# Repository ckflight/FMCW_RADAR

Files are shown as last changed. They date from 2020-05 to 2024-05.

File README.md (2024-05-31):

# Frequency Modulated Continuous Wave Radar Hardware Design and the Firmware

Check the new design's Python files for better processing and analysis https://github.com/ckflight/FMCW_RADAR_2v2

#### Later Update 1: 
  New version of the hardware is available in the **Radar 2** folder. For **Radar 2** design, two separated boards in **Radar MCU** and **Radar RF** folders are brought together with several necessary improvements. I recommend using the second design since it is more reliable and tested. The reason behind two separate board was to change digital part of the board without changing the RF part of it. However, one united design performs better and have a better temperature cooling control which affect the overall perfomance significantly.
  
  ##### Important Power Supply Note: I used switching regulator for 3.3 and 5V power sources to test their effect on the RF performance and oscillation of ripple voltage on OpAmp analog amplifier side. Therefore do not use switching regulator in your design. Change them to LDO type of clean supplies. Or add second LDO stage to the switching regulator unless you want an AM modulated ( 1.4 MHz switching freq. is very visible ) signal at the OpAmp side. After observing these affects i had to fine tune components which is not necessary if you use a cleaner source !!!

#### Later Update 2: 
  I have added a new Python script for plotting the radar data with Python Qt5 and Vispy plotting tool which uses GPU instead of CPU. Radar_Plot2.py is the source code. New code plots the time domain and frequency domain data together with scale and restart options. It has thread based approach between Vispy and Qt classes by using DataSource which allows us to manage more data. See first screenshot under Python Script Plots section below.

#### Radar Info:
 * Frequency Modulated Continuous Wave Radar with 26 dBm output power covering around 250 meters range with 10 dBi gain patch antenna (400 meters in theory by using a better ADC with higher sampling rate to match the noise floor of the RF receiver chain).
 
 $$ Range(radar) = {\sqrt[4]{Pt * G^2 * \lambda^2 * \sigma \over Pmin * 4\pi^3}} $$
 
  * Receiver chain has LNA, Gain Block and Mixer. The gain block drops the Noise Figure from 7 dB to 2 dB, which doubles the detection range. To determine the radar detection range, minimum detectable signal is needed. RF receiver chain has thermal noise and it determines the noise floor for Pmin. Signal to Noise (SNR) ratio of 20 dB is assumed for a good detectable signal then:
 
 $$ Pthermal(watt) = {k * T * B * F} $$
 
 $$ Pthermal(dBm) = {10\log_{10} {kT \over 1mW} + NF + 10\log_{10} BW} $$
  
 $$ Pmin(dBm) = {Pthermal(dBm) + 20dB} $$

 * Radar, has an auto gain configuration with a digital potentiometer to control intermediate frequency (IF) signal gain at the last stage of the analog amplifier before sampling with ADC.
 
 * -40 dB / Decade Range Compensation Filter is implemented. Closer objects reflect more powerful RF signal which suppresses the signal of the objects at further distance. By amplifying the weaker signals and filtering the closer ones, each frequency band is adjusted to the same amplitude.
 
 * The IF signal is available at different stages of the amplifier and filter circuit for testing with other configurations.

 * The VCO range of the radar is from 5.5 to 6.1 GHz
 
 * Directional coupler has low insertion loss of 0.25 dB and 16 dB coupling.
 
 * ADF4158 Frequency Synthesizer is available due to the nonlinear characteristics of the VCO profile for accurate distance detection. ADF4158 can generate pulses with some gap between each sweep. During this gap samples are packed and buffered over USB.
 
  * STM32F4's DAC has a triangular waveform generation option and it can be used for VCO signal generation as well. Both option are available on board. Check schematic to populate necessary resistor values to use either mode.
 
 * SMA connector has 1 mm pad size, but the 50 Ohm transmission line is 0.342 mm wide. To prevent reflection, cutout is implemented beneath the SMA pad with CST Studio simulation which is also available at my repository https://github.com/ckflight/CST_ADS_MODELS_SIMULATIONS

 * PCB has 4 layers. 50 Ohm impedance microstrip transmission line is making 0.342mm trace width by using oshpark's stack-up below. Stack-up layer information can be found here: https://docs.oshpark.com/services/four-layer/

 * Main loop runs with a Finite State Machine (FSM) to control radar, which checks the condition of the start of the sweep and the gap. ADF4158 Muxout is generating a pulse according to the sweep condition. External interrupt tracks this pulse to move between FSM states. 

 * Hardware is configured using Python script so the PC is in Host mode and controls everything. In this way, any hardware parameters can be changed without reflashing the firmware.

 * N number of samples are determined by sweep bandwidth rise time and the sampling frequency. 
   For example:

   Fs = 500.000 samples/sec and the sweep rise time is 1 millisecond (ms) for 200 MHz bandwidth. The system will pack 500 x  16 bit ADC samples and transfer 1000 x 8 bit ADC samples to Python script in 1 ms. Therefore, 1 MegaByte data is buffered to Host PC for 500 KHz sampling frequency in 1 second.
  
 * Python Script: I have uploaded an example record file along with python scripts where the peaks of the stationary objects can be seen. 

### Object Type Detection:

 * Object type detection is done with the similar code that i wrote for my project at the repository https://github.com/ckflight/RADAR_24GHZ_NEURAL_NETWORK
 
## RADAR 2 Screenshot:
Radar 2

## RADAR 1 RF Board Screenshot:
RADAR_RF

## RADAR 1 MCU Board Screenshot:
RADAR_MCU



## Python Script Plots:
radar1

radar2

radar3

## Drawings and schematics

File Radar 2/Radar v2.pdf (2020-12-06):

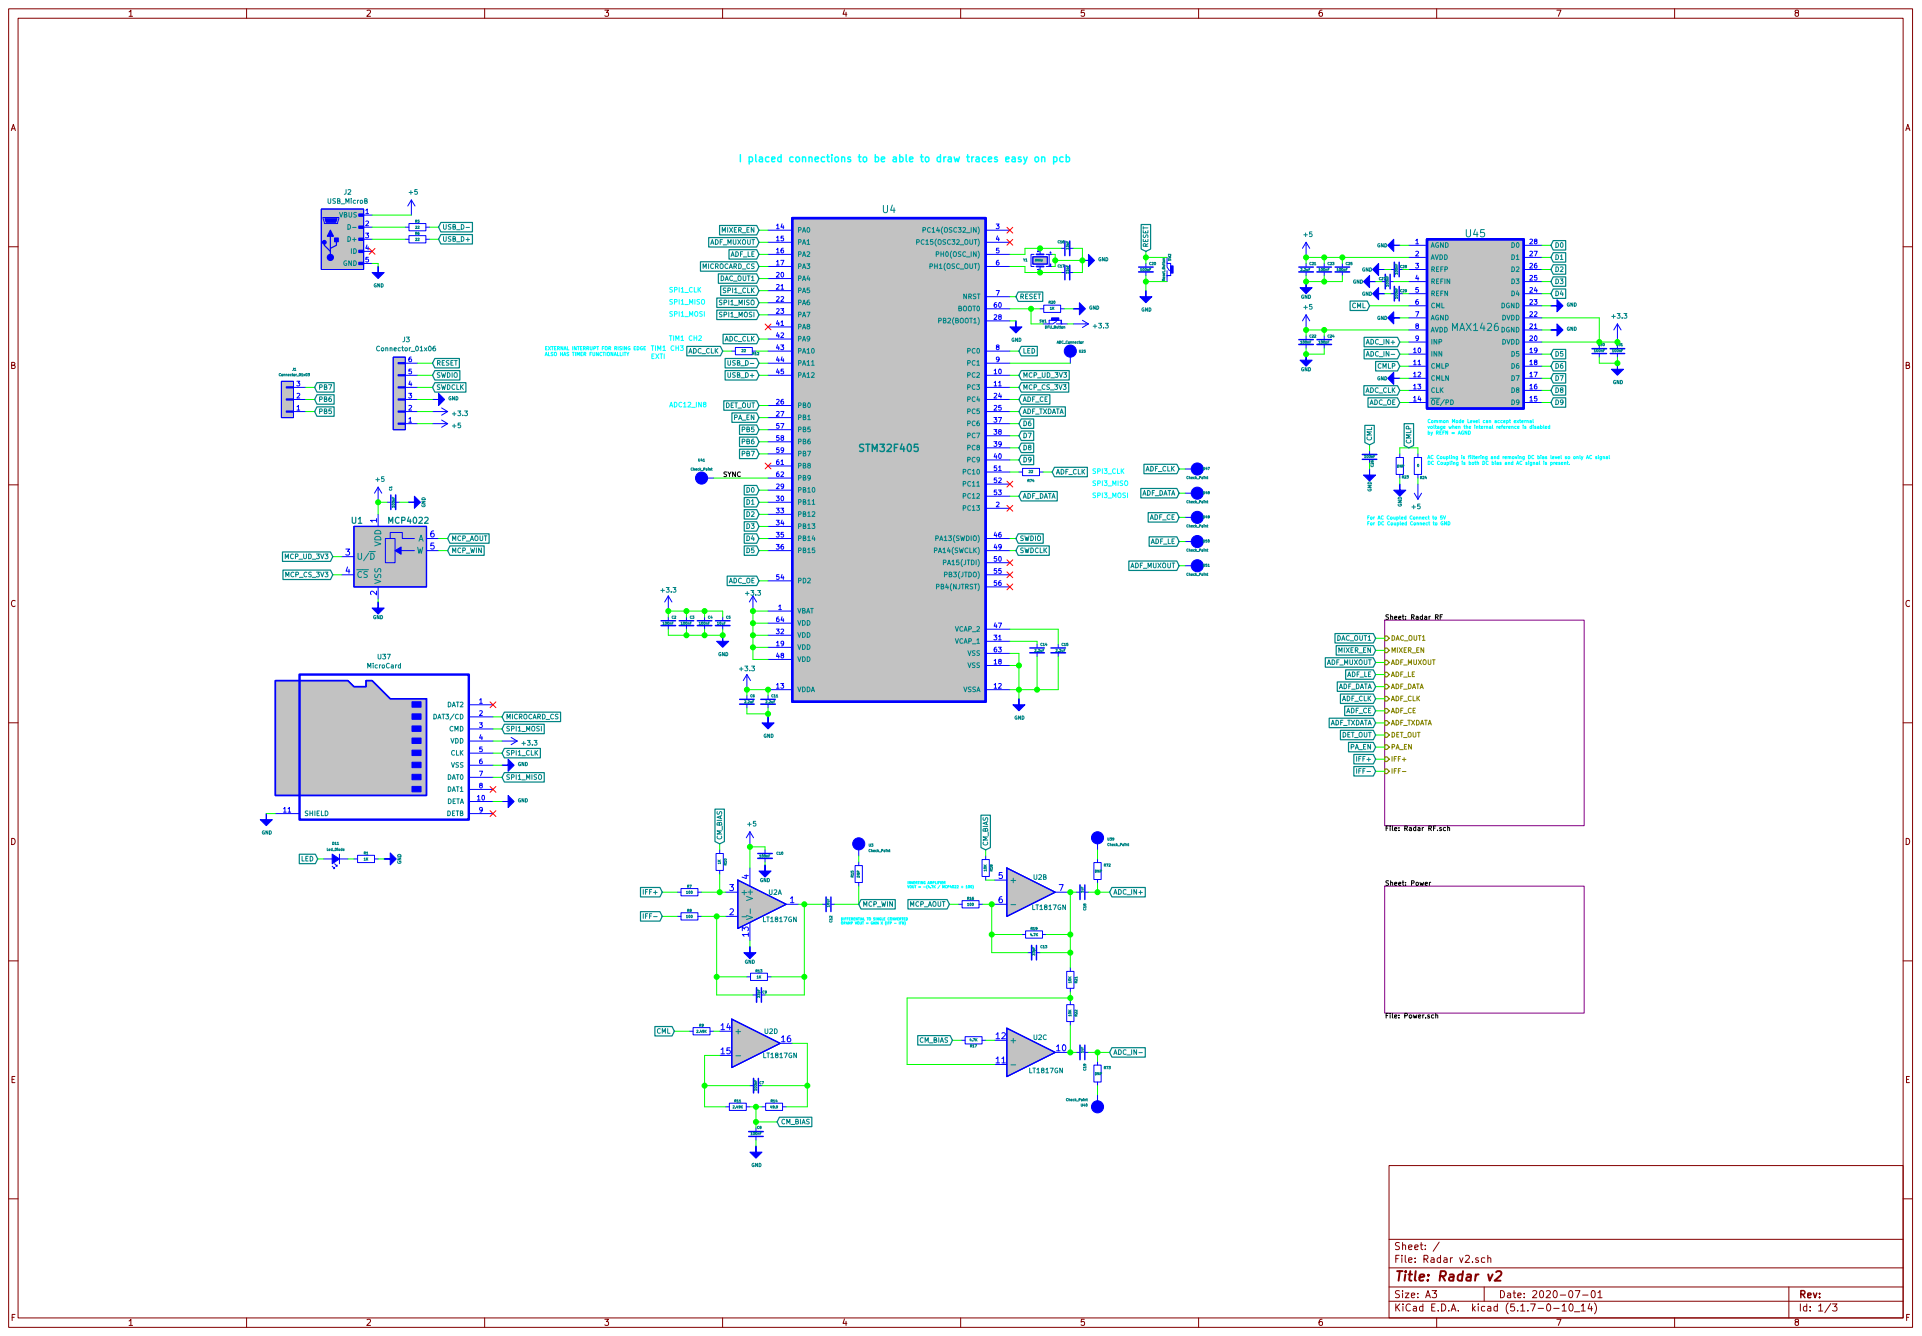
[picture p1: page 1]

I placed connections to be able to draw traces easy on pcb

LED | 1K

AC Coupling is filtering and removing DC bias level so only AC signal DC Coupling is both DC bias and AC signal is present. ADC12_IN8

Common Mode Level can accept external voltage when the internal reference is disabled

For AC Coupled Connect to 5V
For DC Coupled Connect to GND

Sheet: Radar RF
File: Radar RF.sch DAC_OUT1 MIXER_EN

VOUT = -(4.7K / MCP4022 + 100) DIFFERENTIAL TO SINGLE CONVERTED OPAMP VOUT = GAIN X (IFP - IFN)

File: Radar v2.sch Sheet: /
Id: 1/3 Title: Radar v2

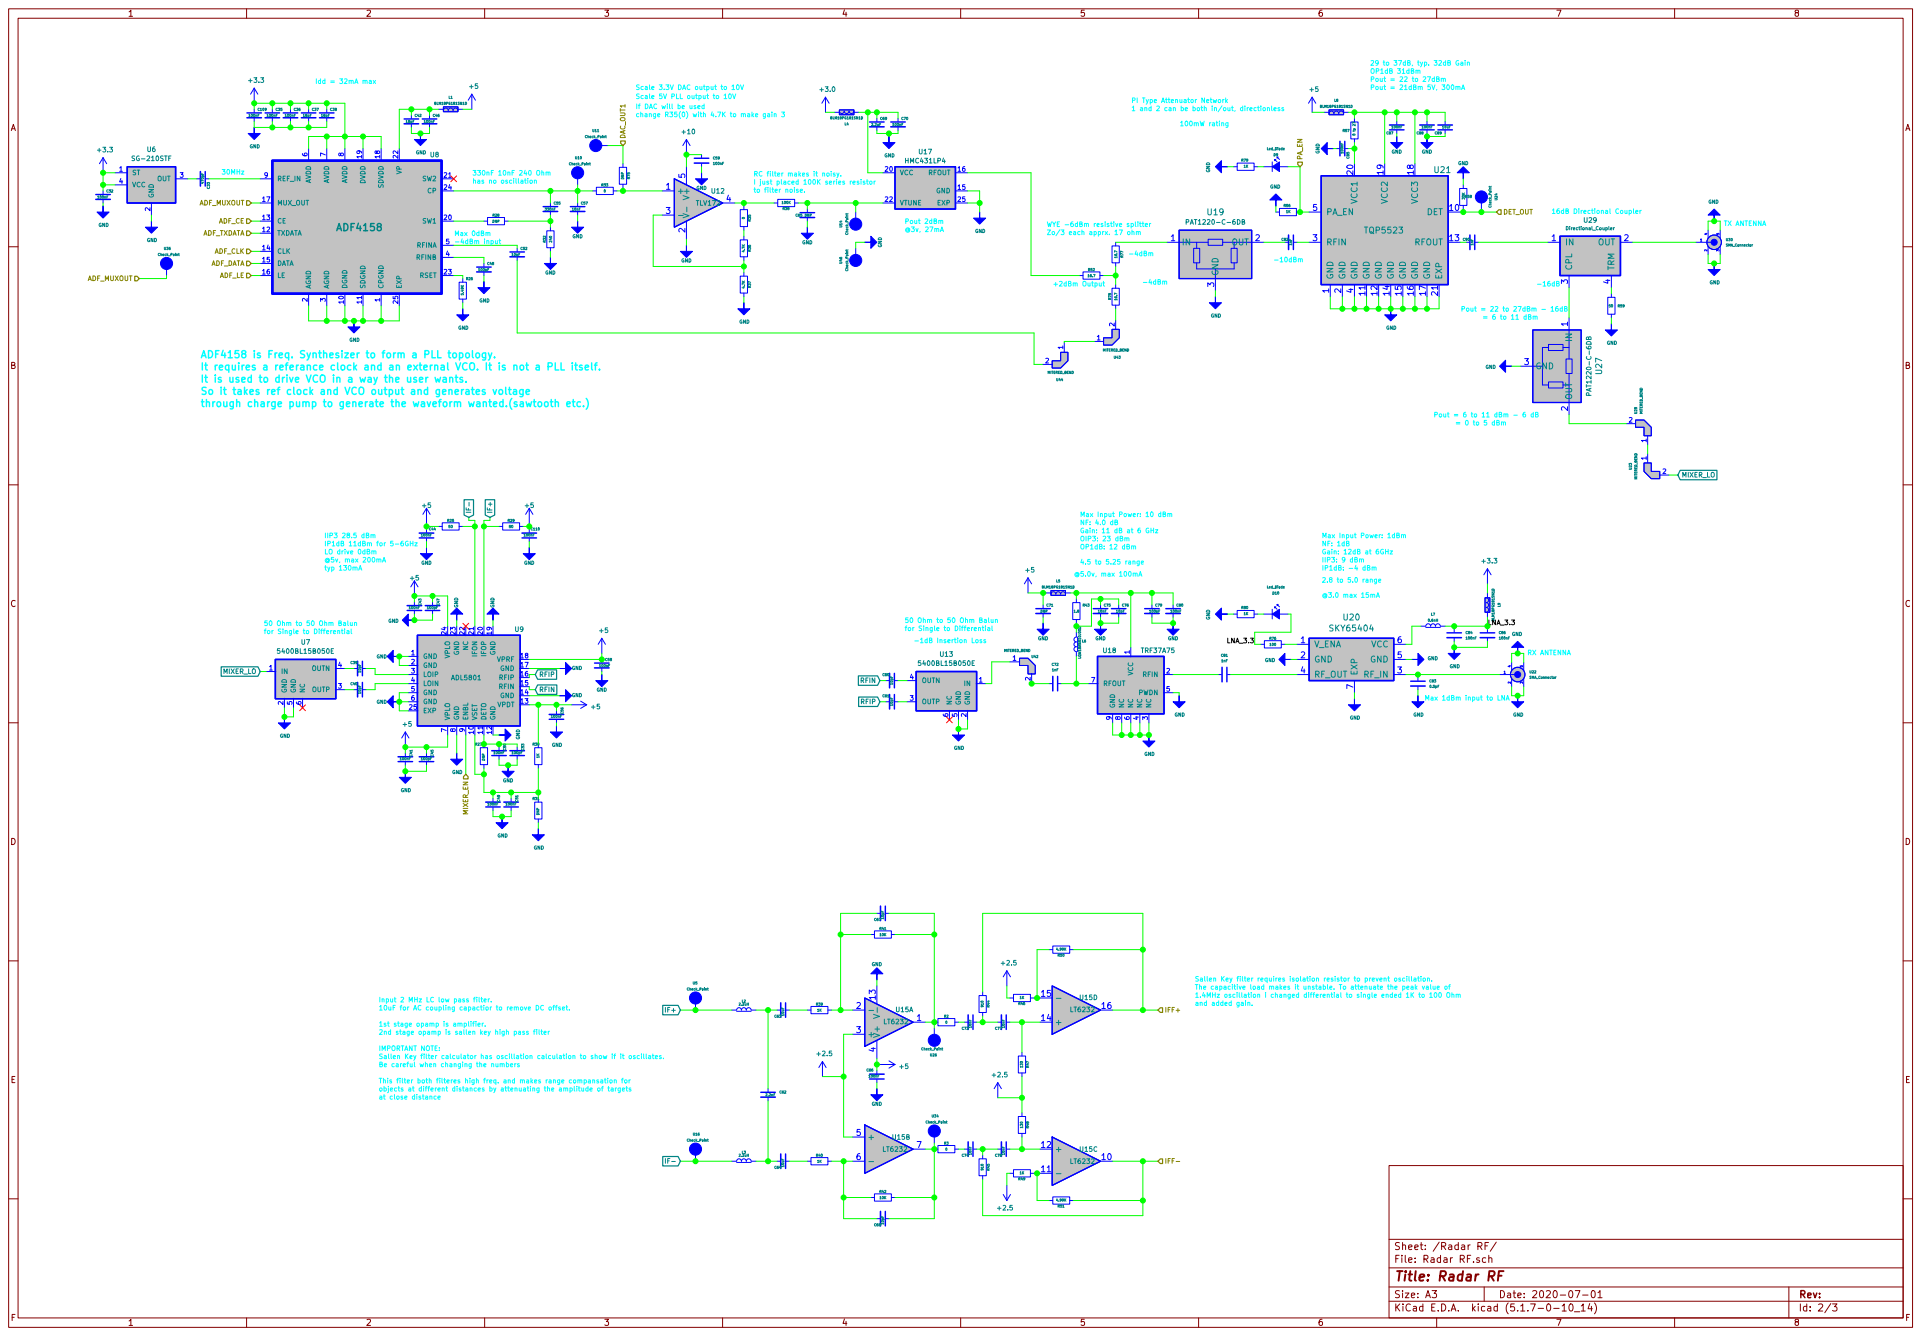
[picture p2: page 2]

Scale 3.3V DAC output to 10V
Scale 5V PLL output to 10V
If DAC will be used
change R35(0) with 4.7K to make gain 3

Pout = 21dBm 5V, 300mA WYE -6dBm resistive splitter Zo/3 each apprx. 17 ohm

2 SW1 20 SW2 21 VP 22 RSET 23 CP 24 EXP 25 AGND

1 DET 10 GND 11 GND 12 RFOUT 13 GND 14 GND 15 GND 16 GND 17 VCC3 18 VCC2 19 GND

RC filter makes it noisy.
I just placed 100K series resistor
to filter noise.

1 DGND 10 SDGND 11 TXDATA 12 CE 13 CLK 14 DATA 15

for Single to Differential ADF4158 is Freq. Synthesizer to form a PLL topology.
It requires a referance clock and an external VCO. It is not a PLL itself.
It is used to drive VCO in a way the user wants.
So it takes ref clock and VCO output and generates voltage
through charge pump to generate the waveform wanted.(sawtooth etc.)

Pout = 6 to 11 dBm - 6 dB
= 0 to 5 dBm

Max 1dBm input to LNA Max Input Power: 10 dBm
NF: 4.0 dB Gain: 11 dB at 6 GHz OIP3: 23 dBm

IIP3 28.5 dBm
IP1dB 11dBm for 5-6GHz LO drive 0dBm @5v, max 200mA

RX ANTENNA Max Input Power: 1dBm
NF: 1dB Gain: 12dB at 6GHz

100pF GND
for Single to Differential 50 Ohm to 50 Ohm Balun

50 Ohm to 50 Ohm Balun

Sallen Key filter requires isolation resistor to prevent oscillation. The capacitive load makes it unstable. To attenuate the peak value of 1.4MHz oscillation i changed differential to single ended 1K to 100 Ohm

Input 2 MHz LC low pass filter. 10uF for AC coupling capactior to remove DC offset. 1st stage opamp is amplifier. 2nd stage opamp is sallen key high pass filter

IMPORTANT NOTE: Sallen Key filter calculator has oscillation calculation to show if it oscillates. Be careful when changing the numbers This filter both filteres high freq. and makes range compansation for objects at different distances by attenuating the amplitude of targets

Id: 2/3 Title: Radar RF

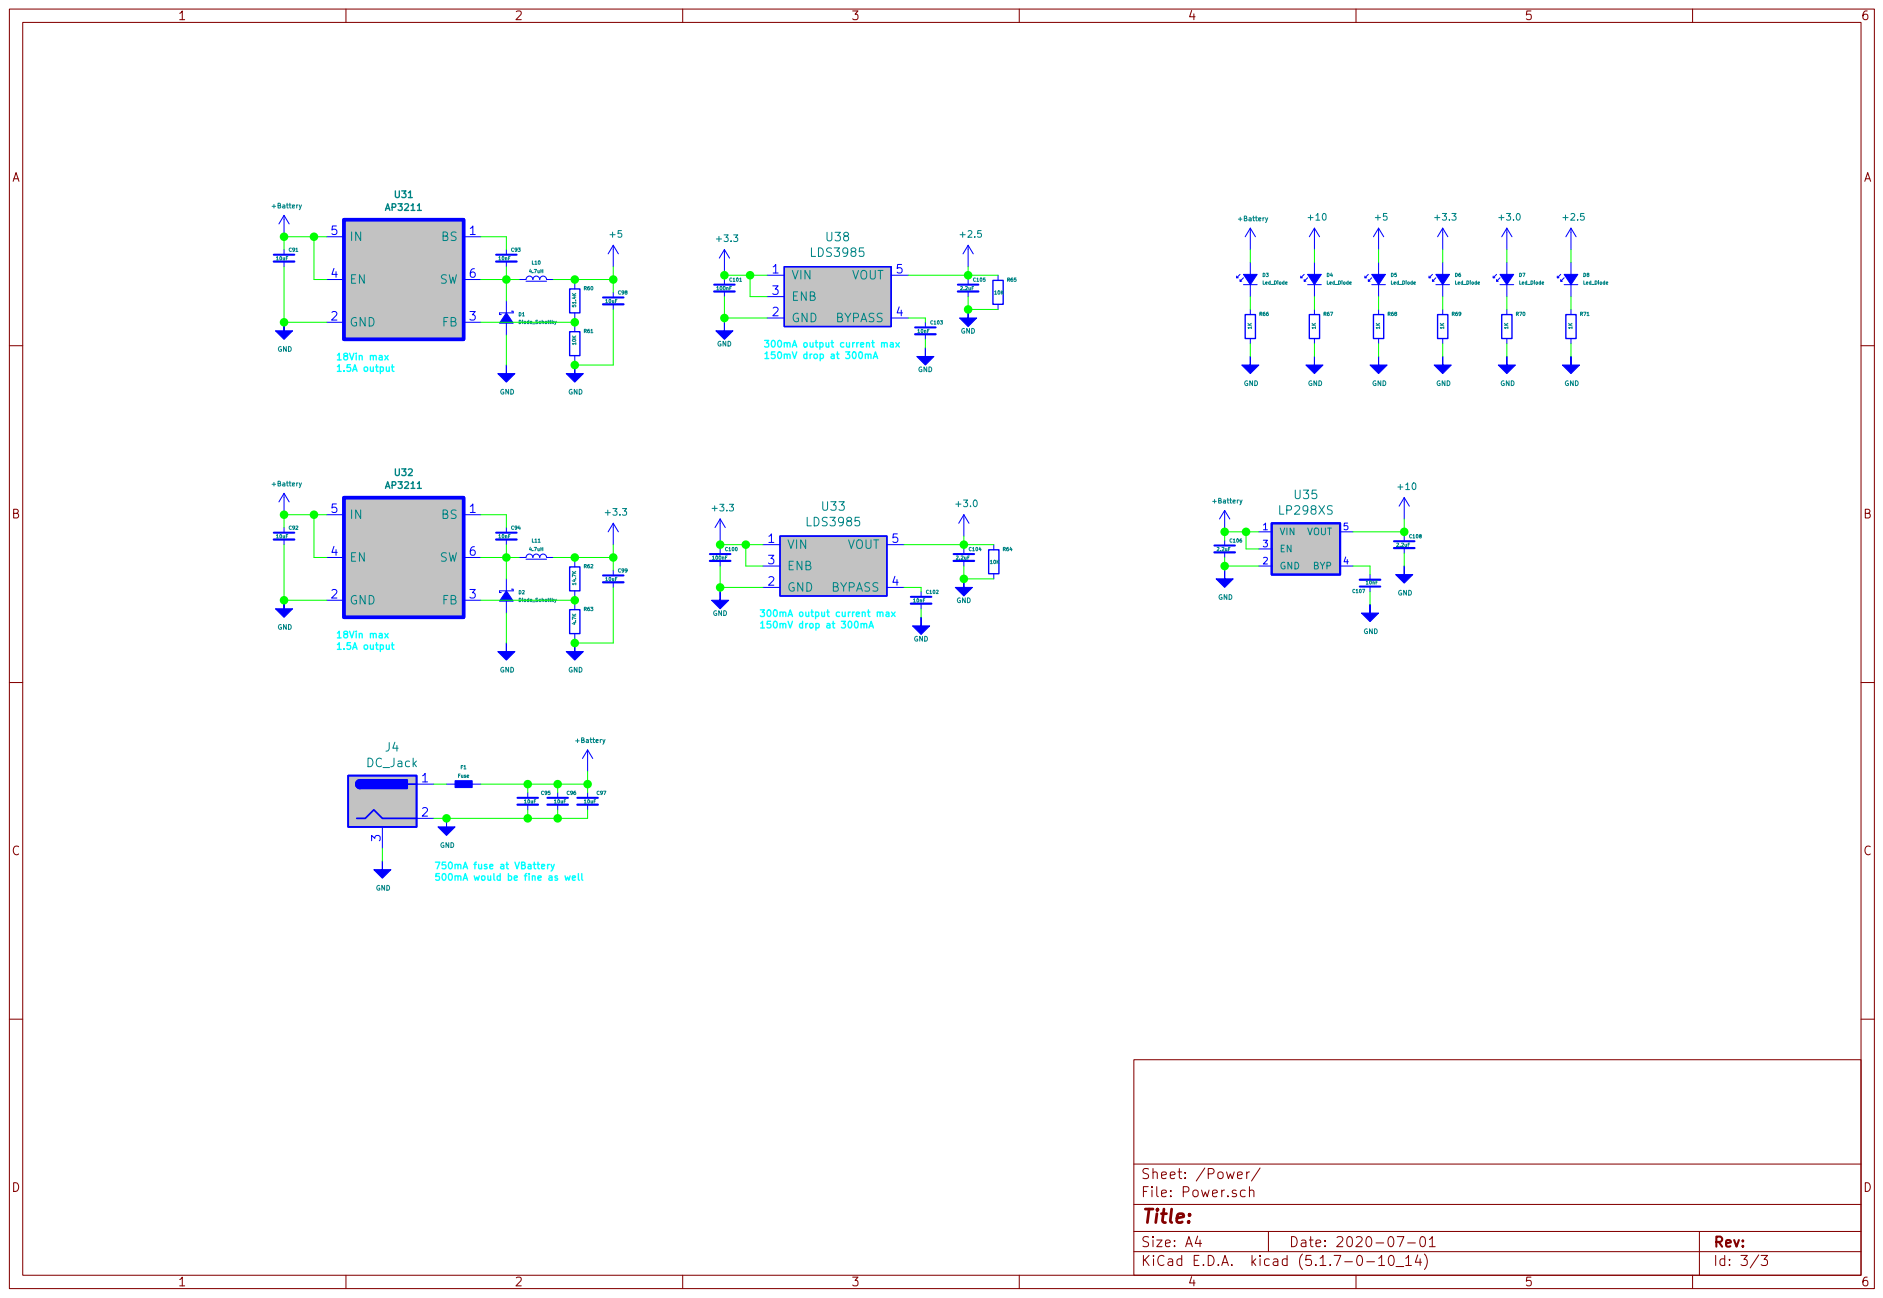
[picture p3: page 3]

Id: 3/3 Title: File: Power.sch Sheet: /Power/

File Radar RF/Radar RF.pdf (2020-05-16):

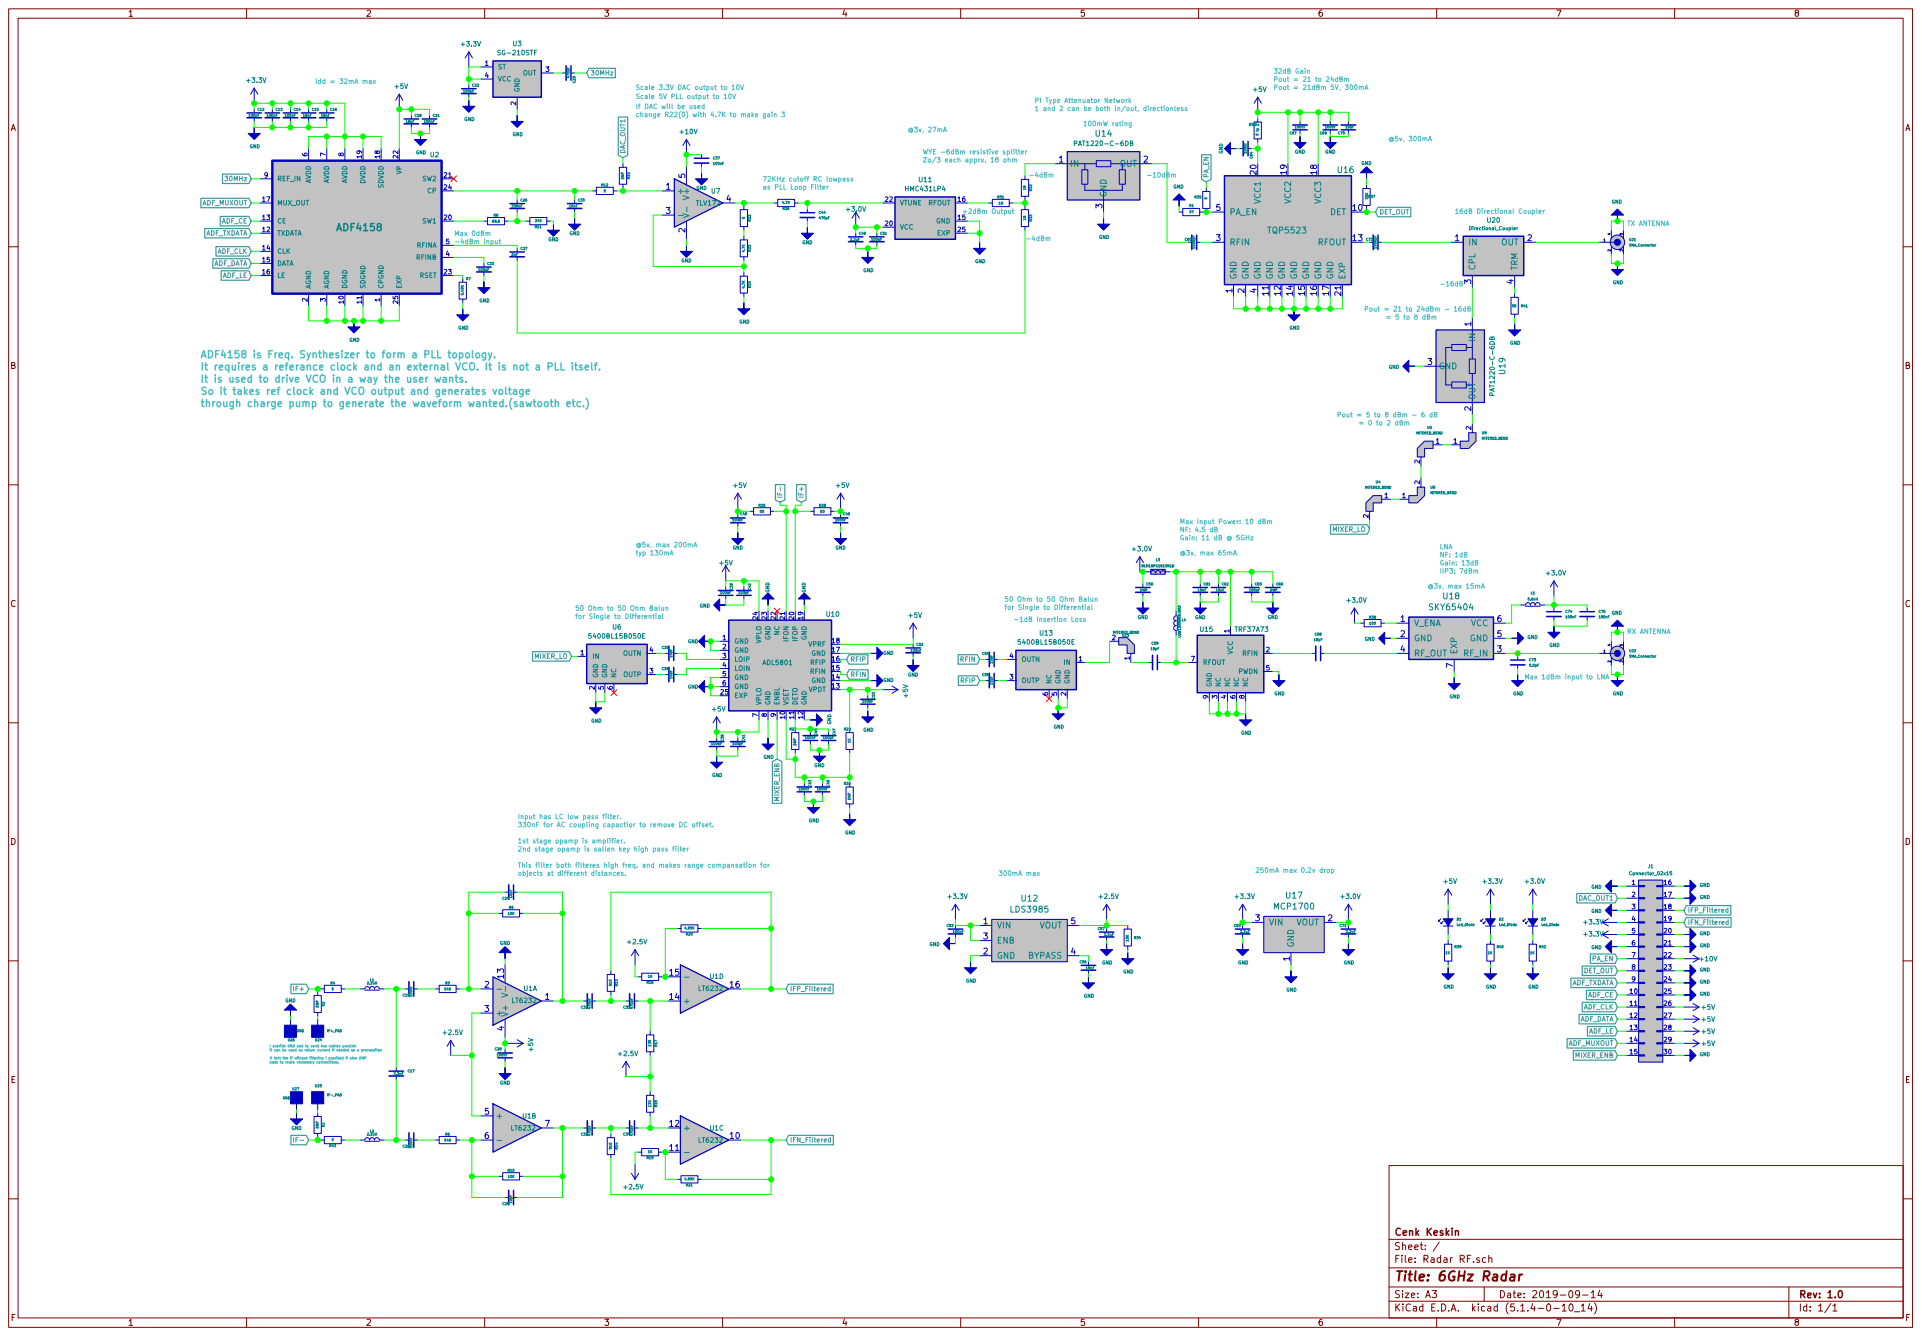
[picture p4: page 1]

Scale 5V PLL output to 10V
If DAC will be used

PI Type Attenuator Network

2 SW1 20 SW2 21 VP 22 RSET 23 CP 24 EXP 25 AGND

WYE -6dBm resistive splitter Zo/3 each apprx. 18 ohm

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

1 DGND 10 SDGND 11 TXDATA 12 CE 13 CLK 14 DATA 15

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

Pout = 5 to 8 dBm - 6 dB
= 0 to 2 dBm

50 C40 | 50 GND

NF: 4.5 dB Gain: 11 dB @ 5GHz

Input has LC low pass filter. 330nF for AC coupling capactior to remove DC offset. 1st stage opamp is amplifier. 2nd stage opamp is sallen key high pass filter This filter both filteres high freq. and makes range compansation for objects at different distances.

GND GND GND GND GND GND +3.3V

I provide GND pad to send two cables parallel
it can be used as return current if needed as a precausiton

If test the if without filtering i provided 0 ohm DNP pads to make necessary connections.

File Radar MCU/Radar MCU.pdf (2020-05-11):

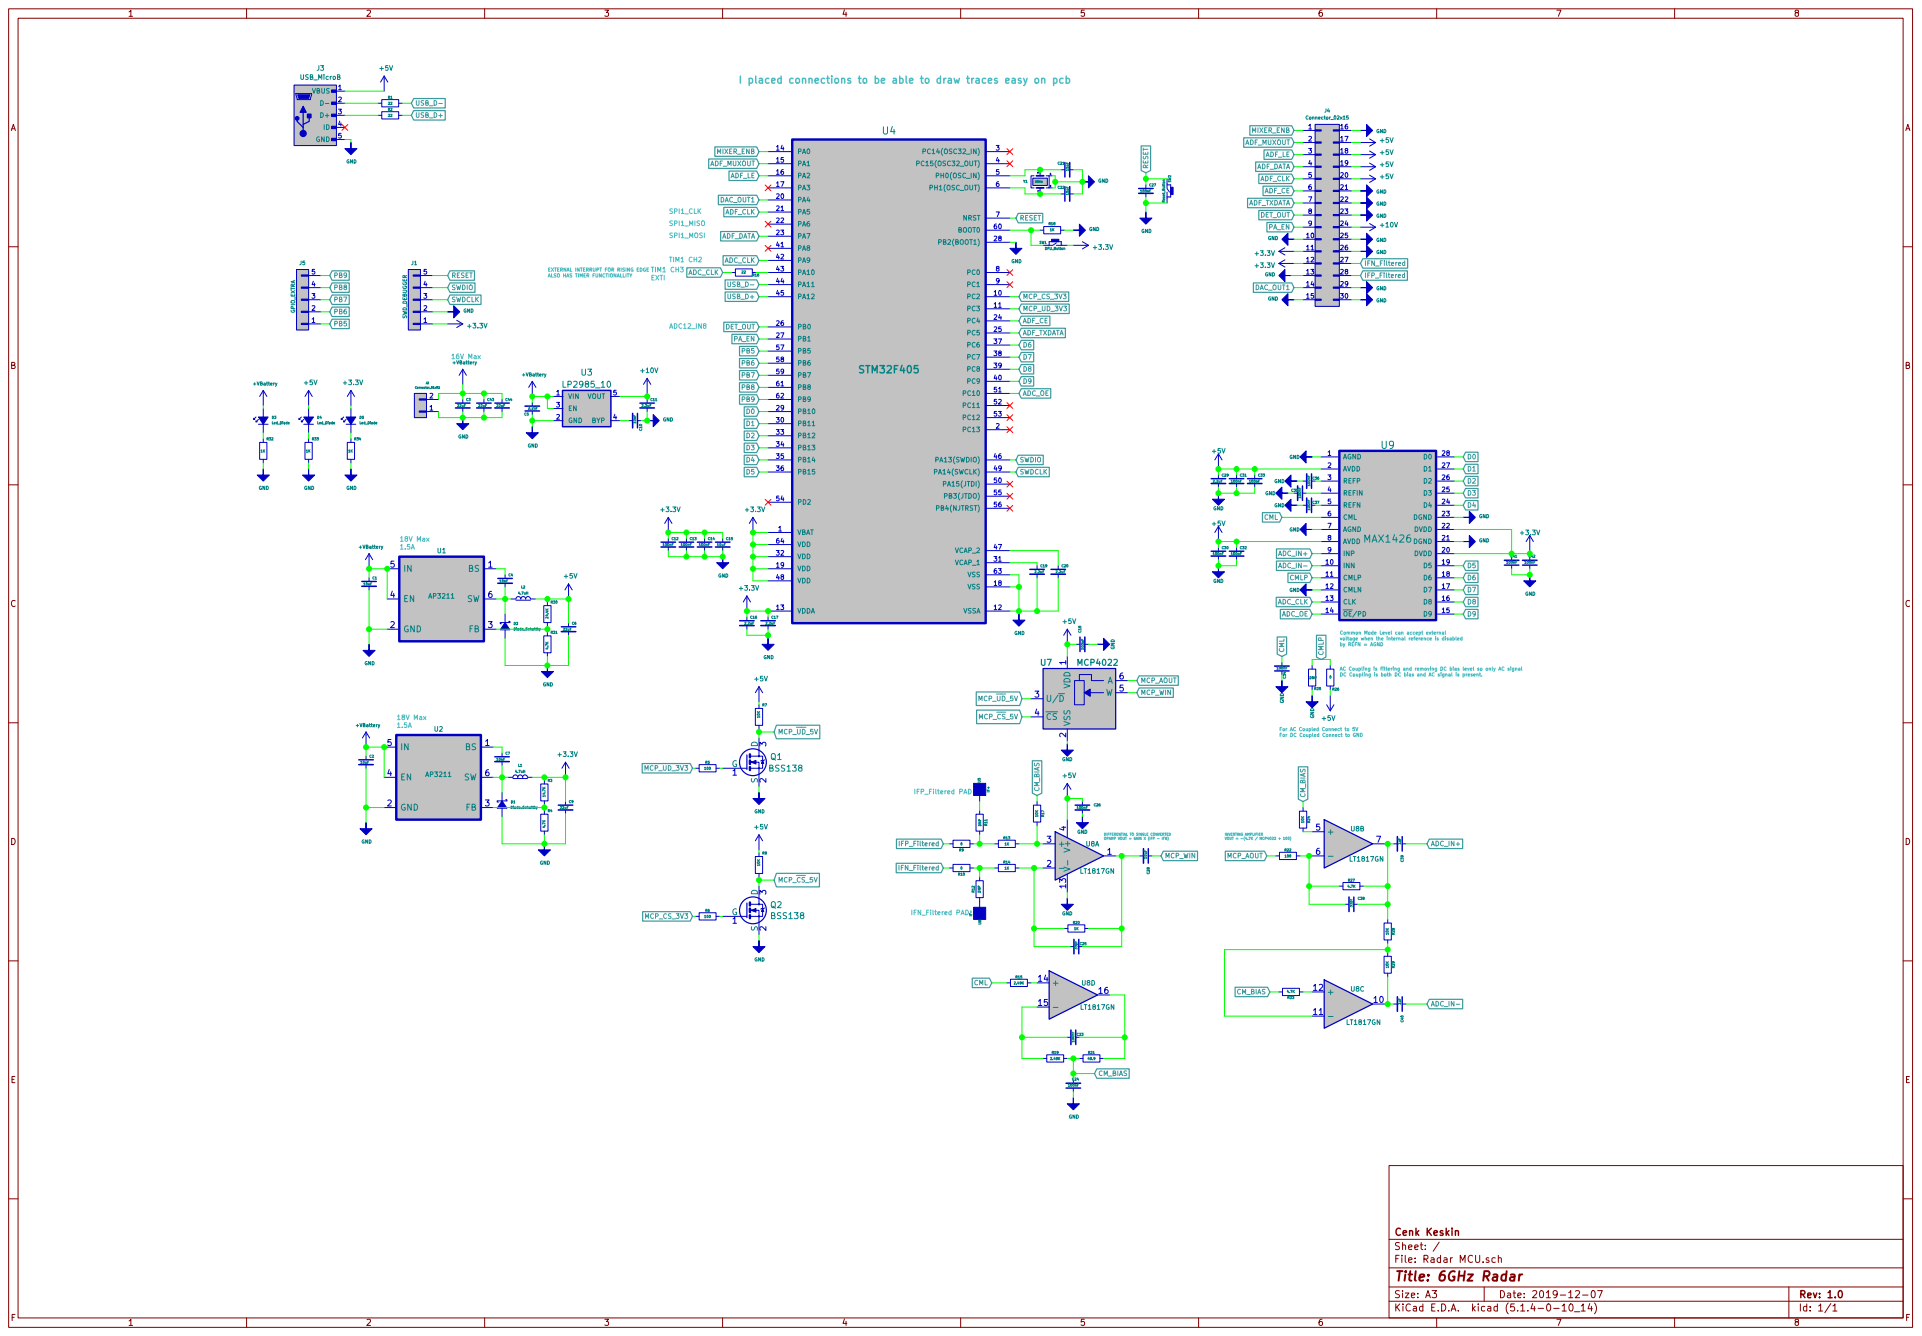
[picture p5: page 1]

I placed connections to be able to draw traces easy on pcb

EXTERNAL INTERRUPT FOR RISING EDGE ALSO HAS TIMER FUNCTIONALLITY

AC Coupling is filtering and removing DC bias level so only AC signal DC Coupling is both DC bias and AC signal is present. Common Mode Level can accept external voltage when the internal reference is disabled

For AC Coupled Connect to 5V
For DC Coupled Connect to GND

VOUT = -(4.7K / MCP4022 + 100) DIFFERENTIAL TO SINGLE CONVERTED OPAMP VOUT = GAIN X (IFP - IFN)

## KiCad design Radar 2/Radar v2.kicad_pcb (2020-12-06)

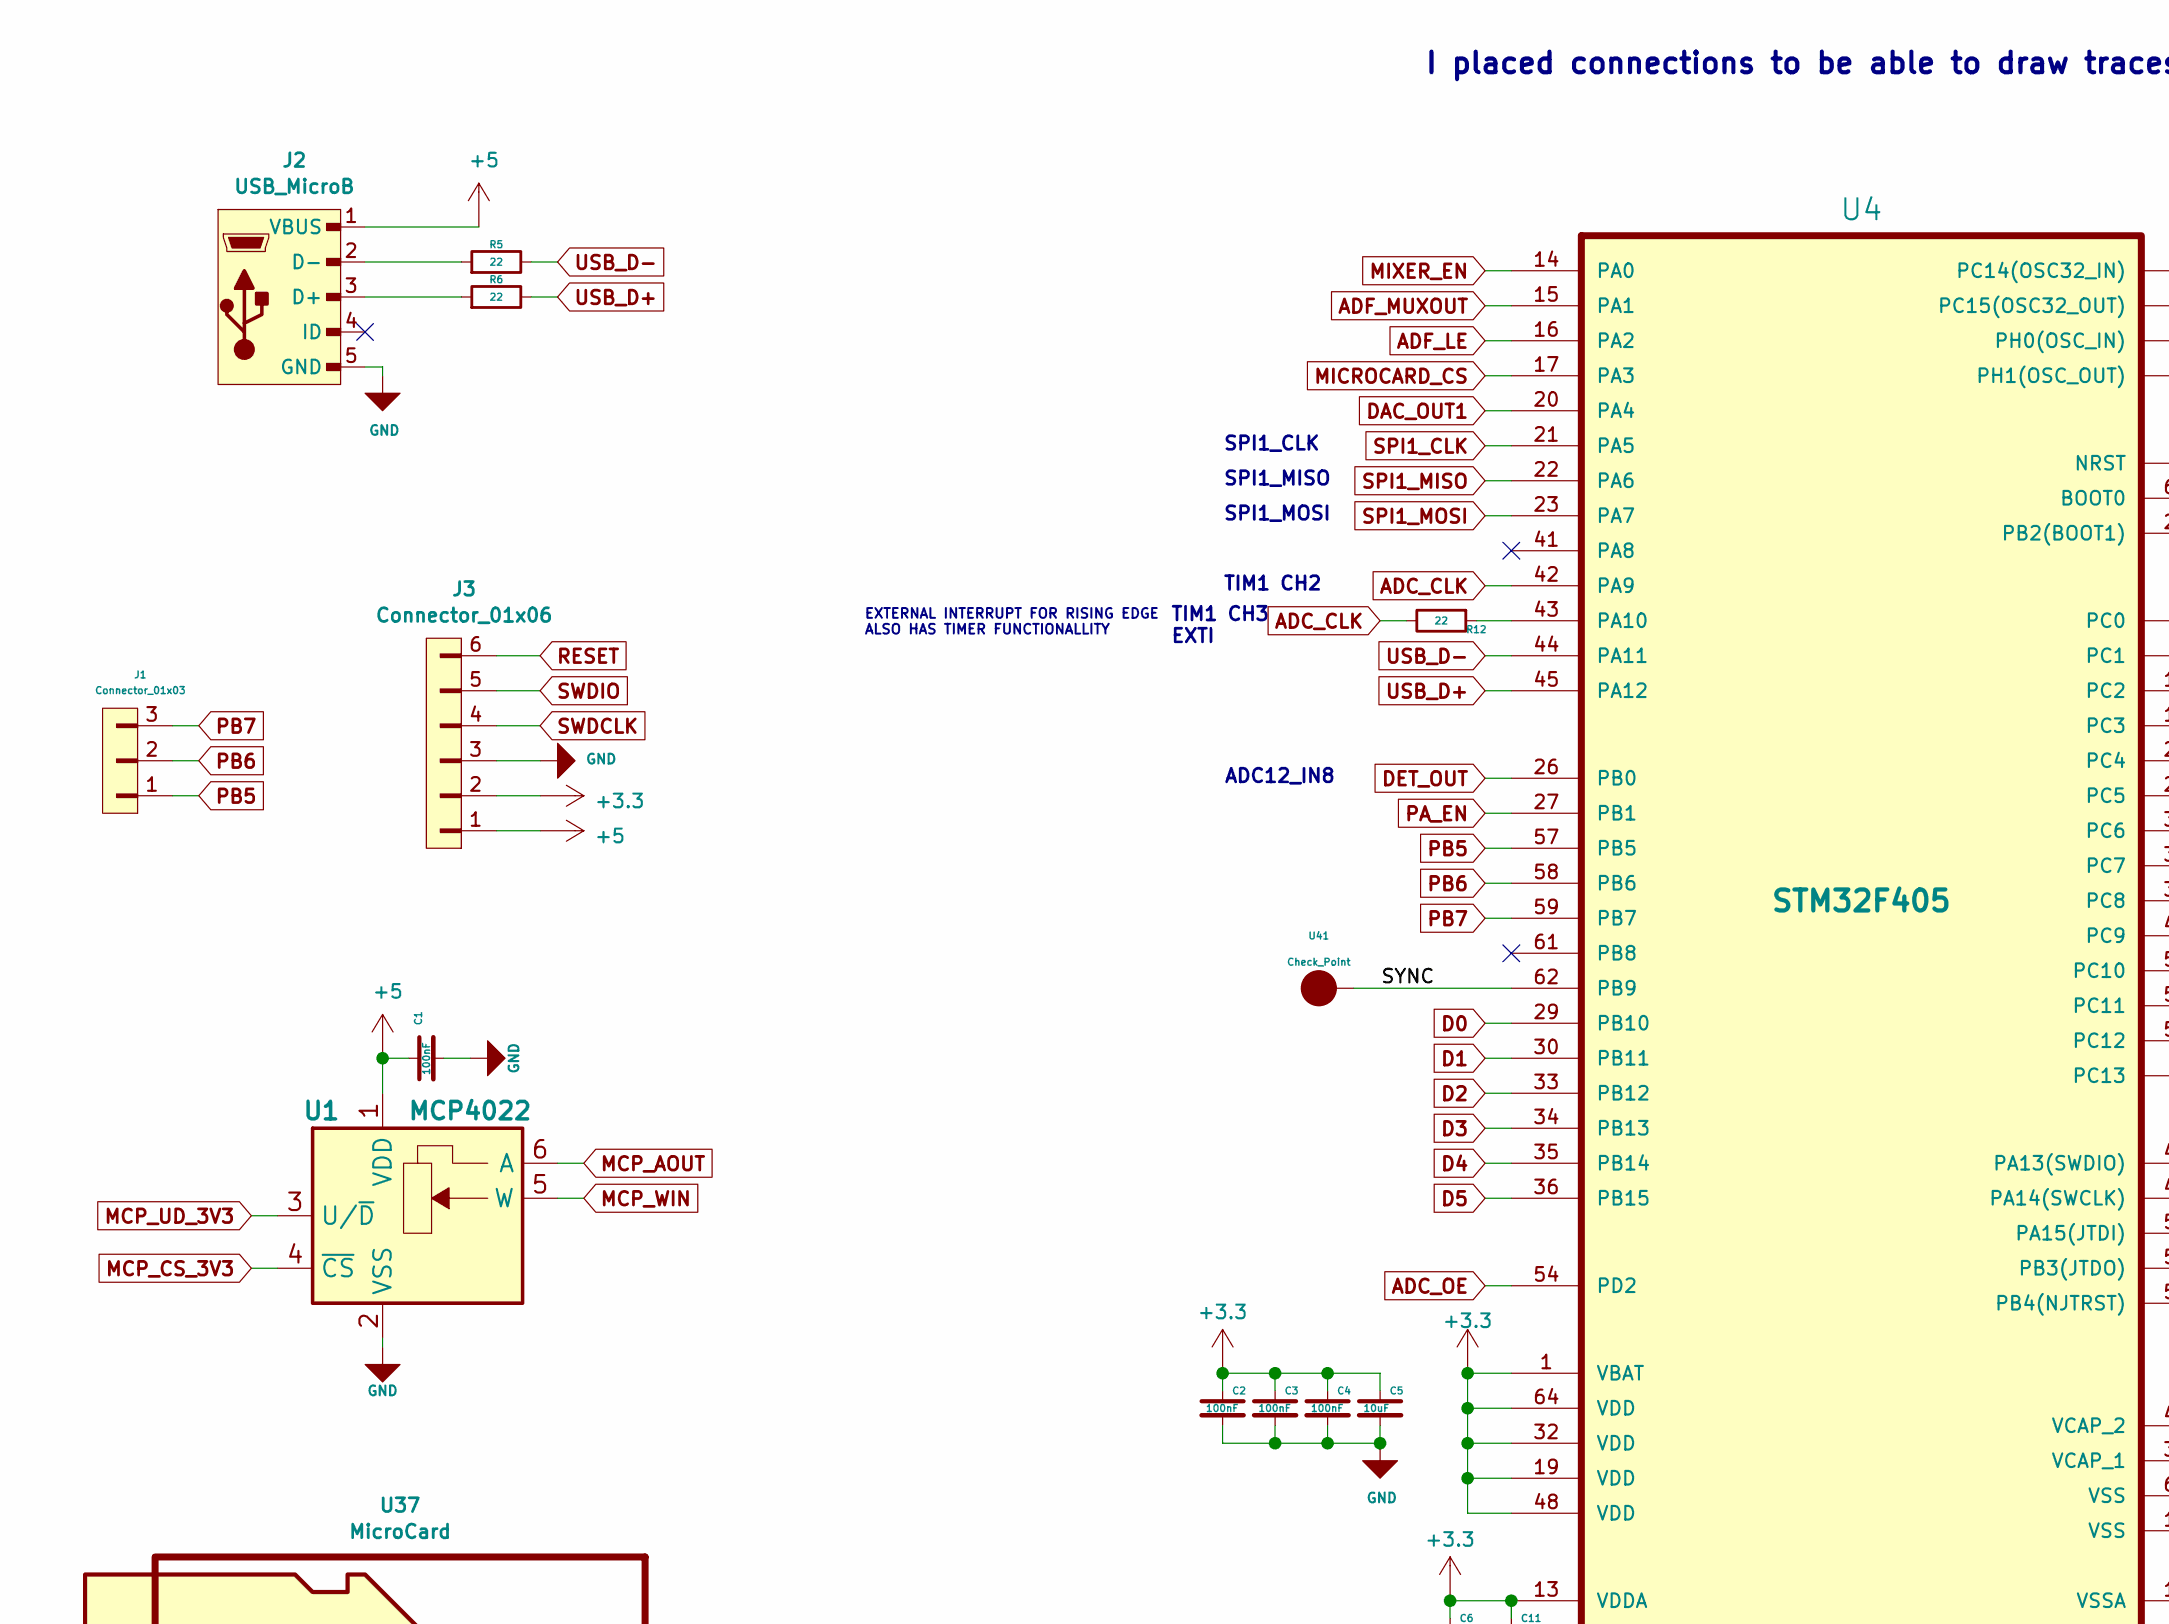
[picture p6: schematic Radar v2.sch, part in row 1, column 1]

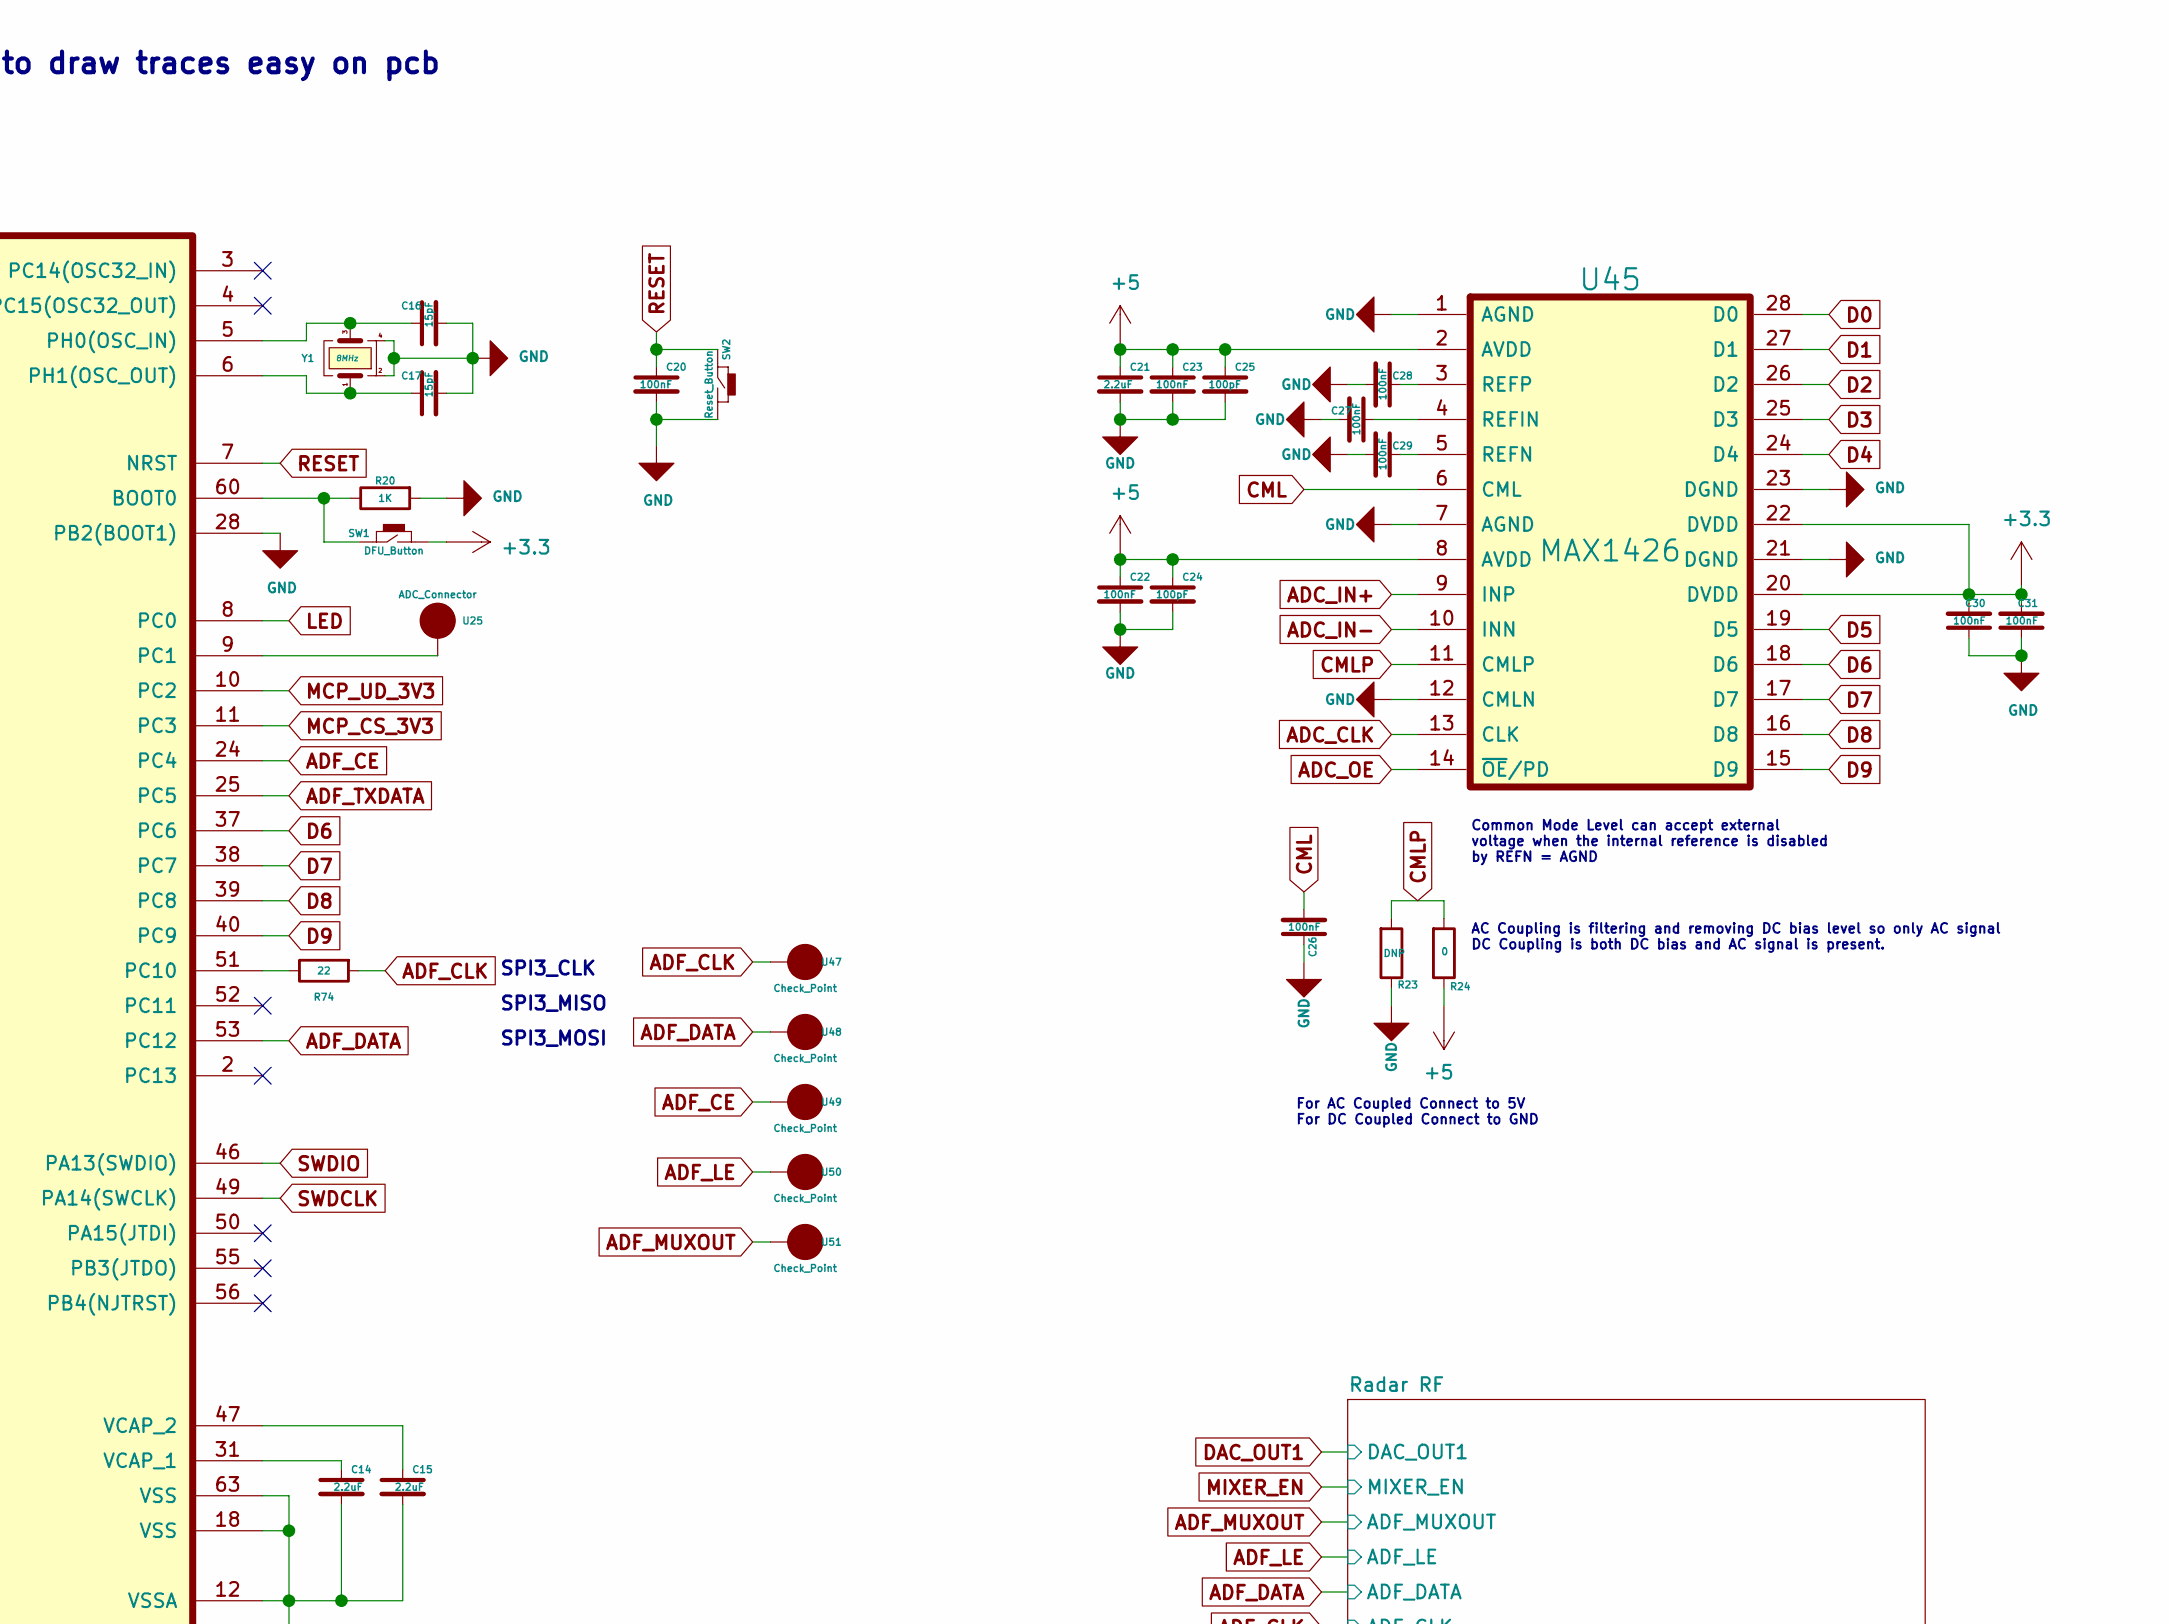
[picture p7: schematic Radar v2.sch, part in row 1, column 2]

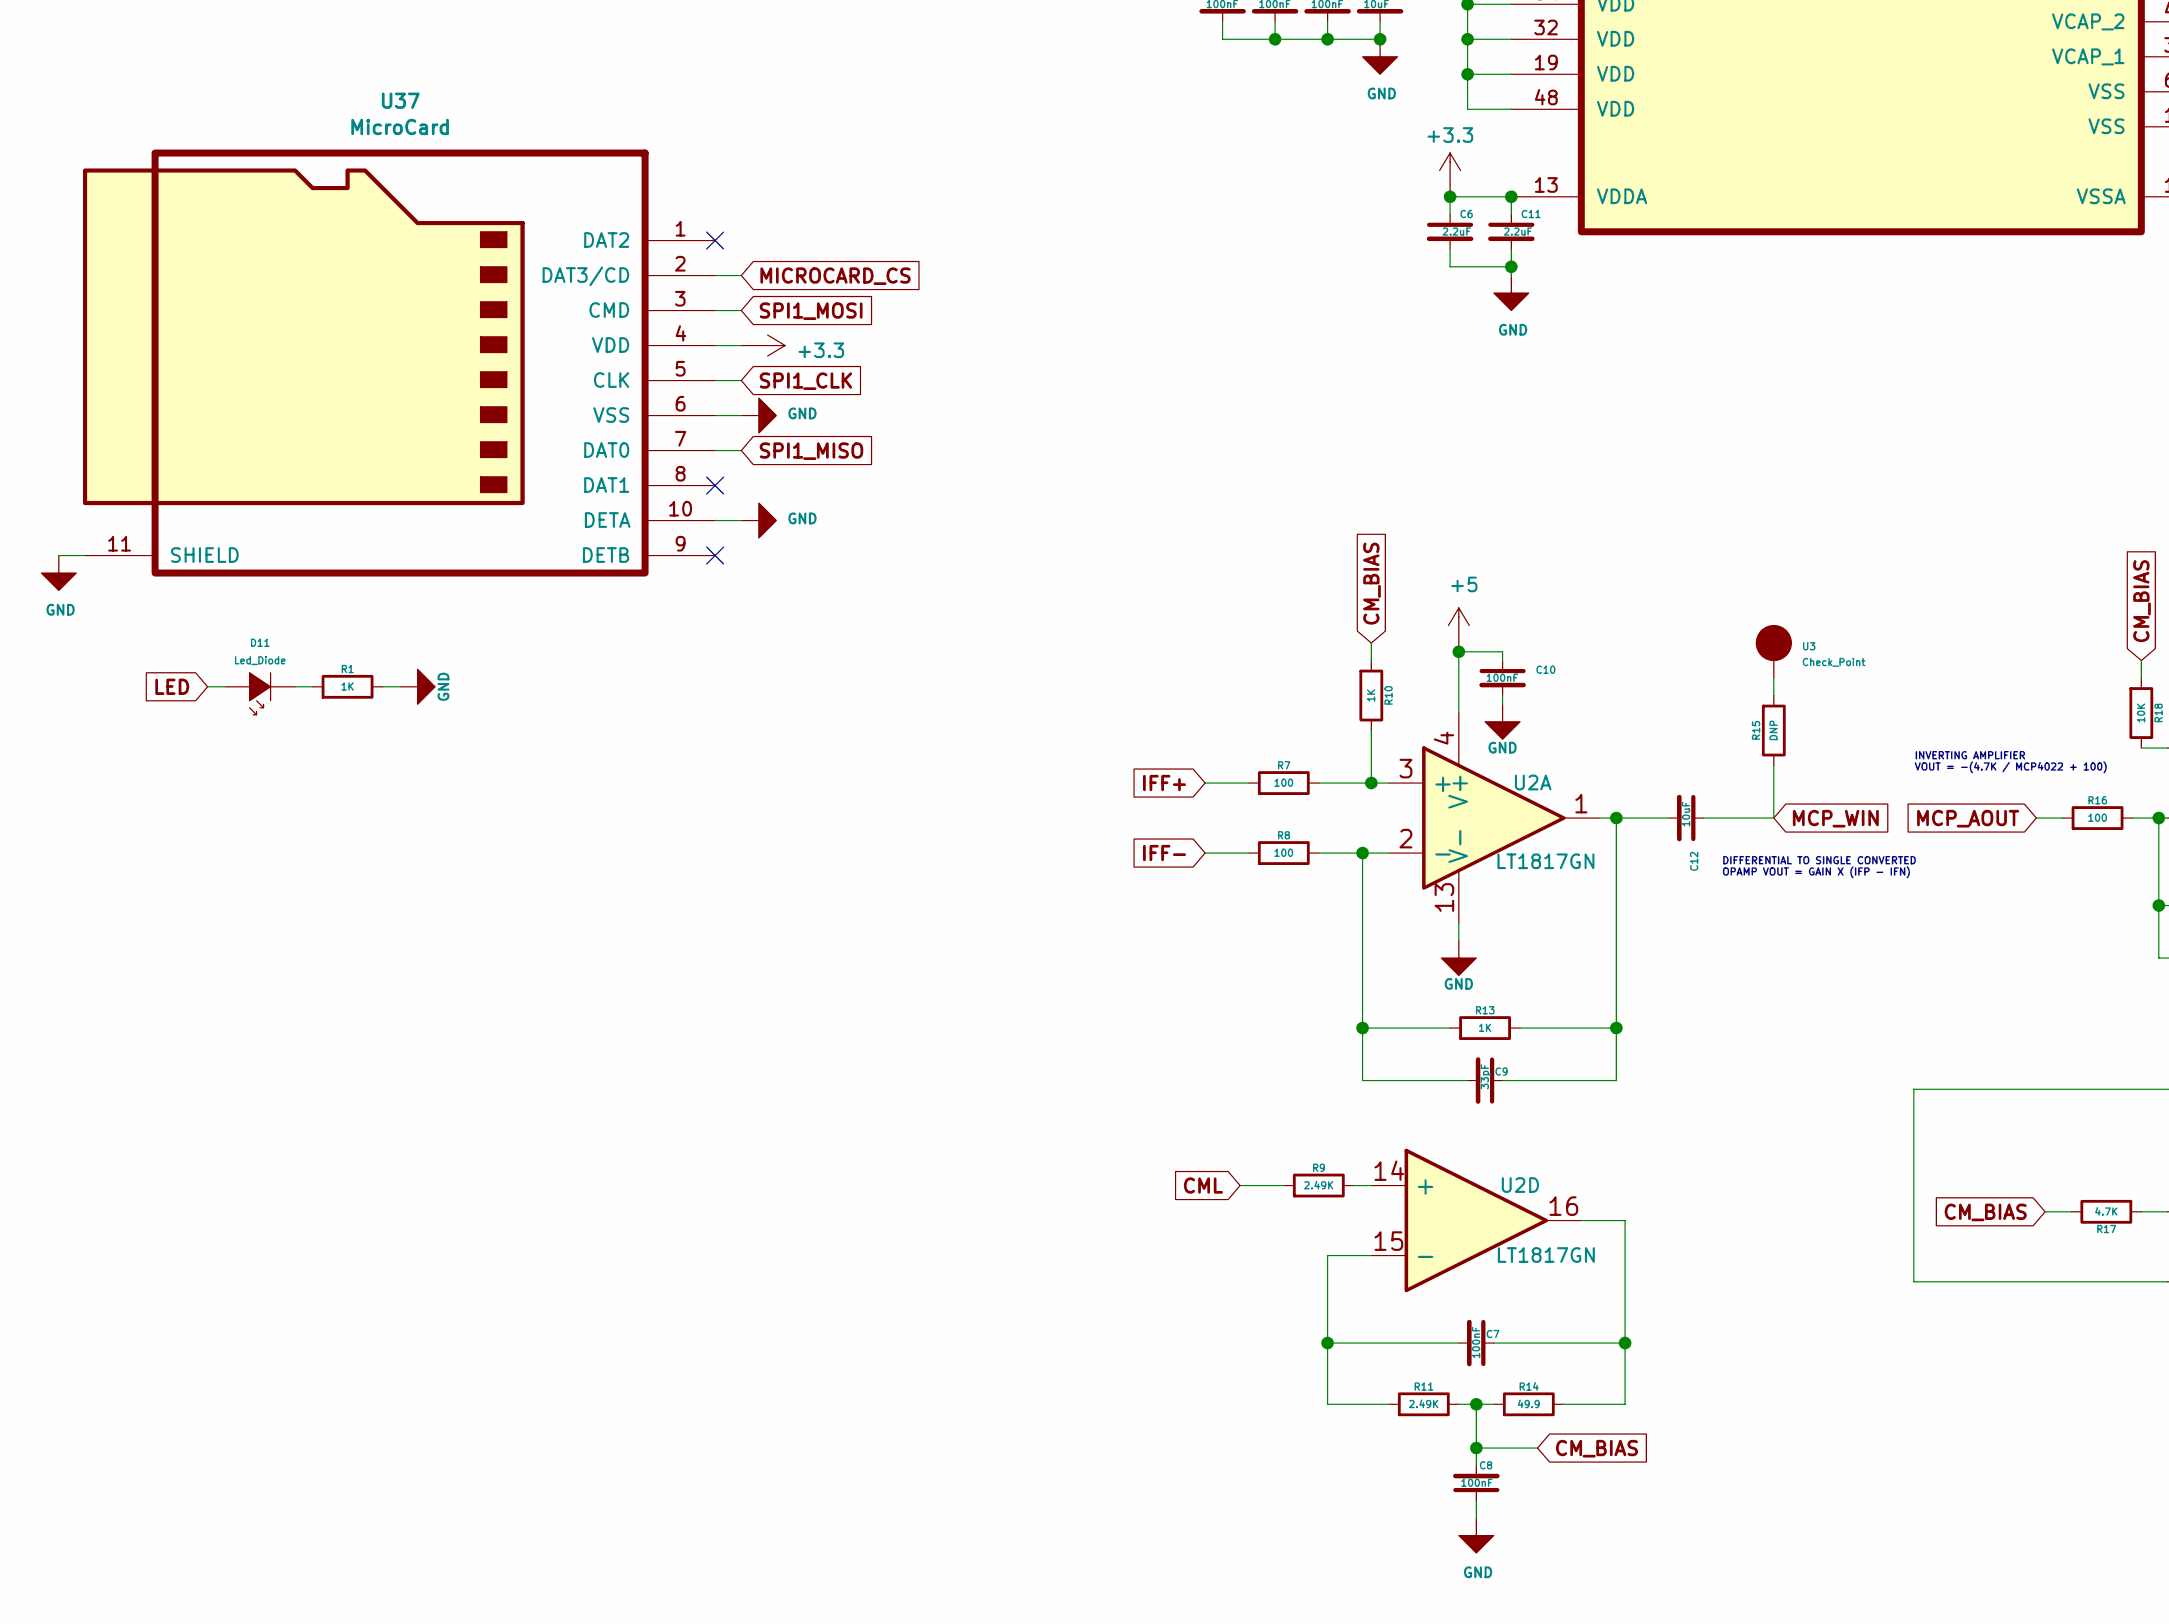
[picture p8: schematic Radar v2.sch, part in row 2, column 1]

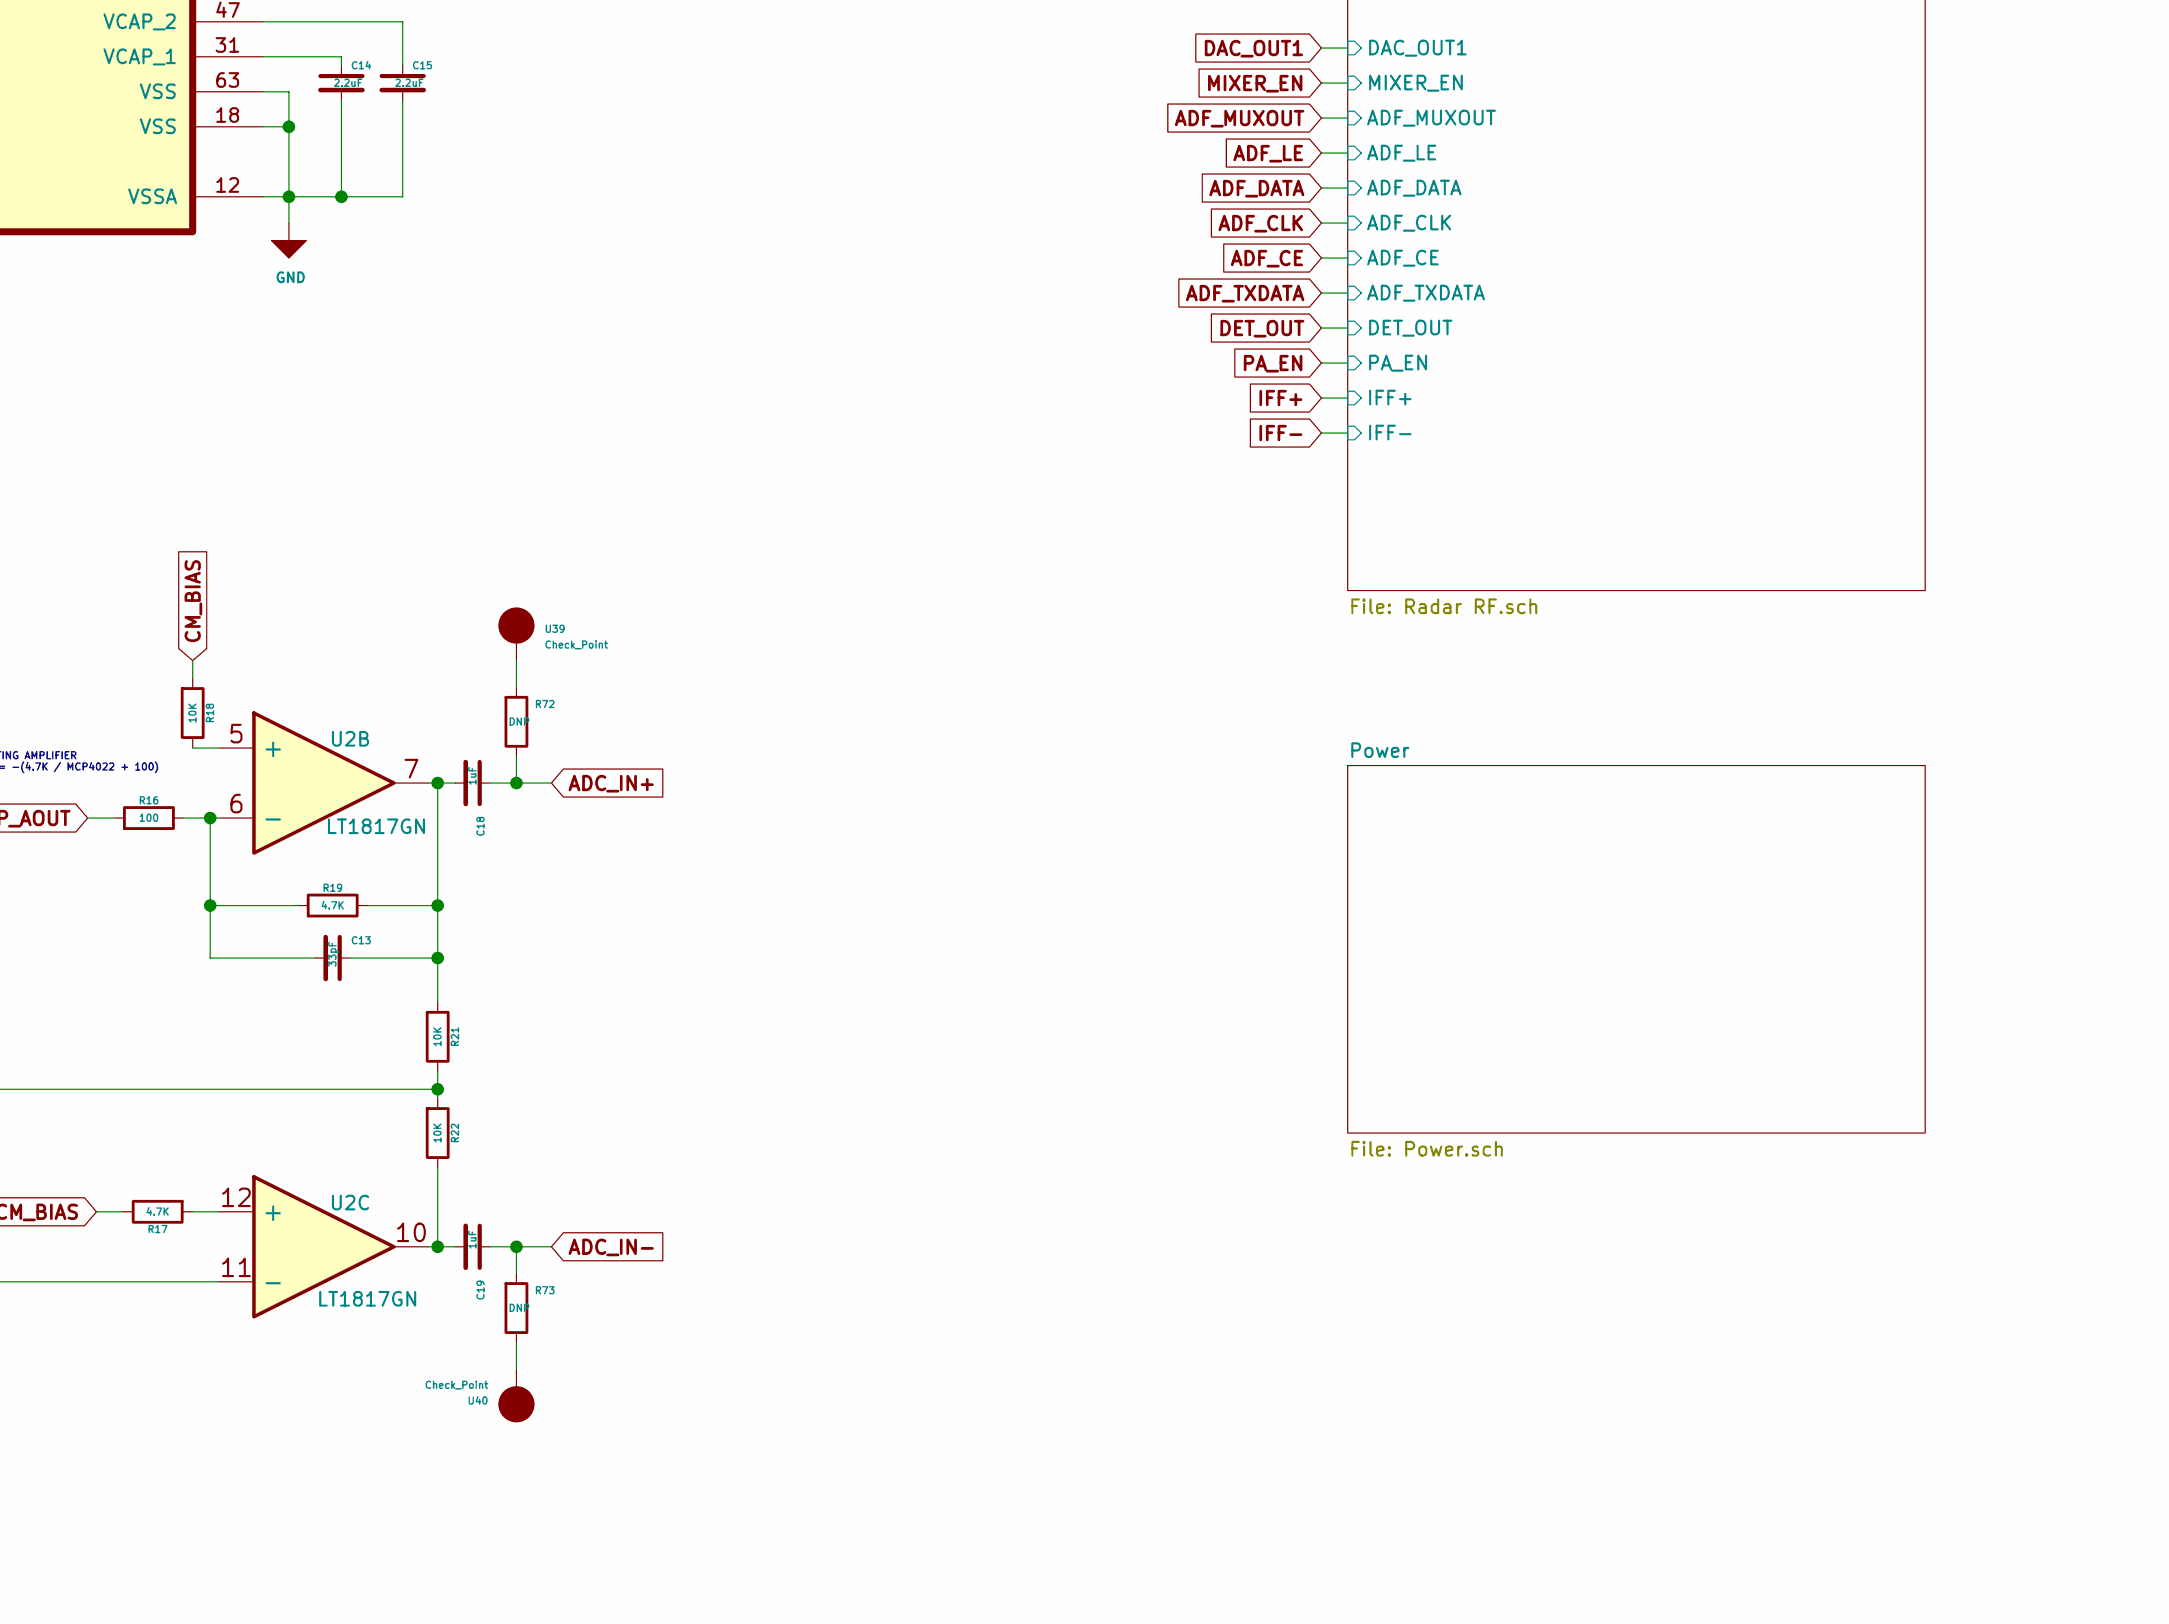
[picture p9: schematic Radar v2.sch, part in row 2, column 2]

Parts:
C1, C2, C3, C4, C7, C8, C10, C20, C22, C23, C26, C27, C28, C29, C30, C31: 100nF; SMD_0402
C5, C12: 10uF; SMD_0603
C6, C11, C14, C15, C21: 2.2uF; SMD_0402
C9, C13: 33pF; SMD_0402
C16, C17: 15pF; SMD_0402
C18, C19: 1uF; SMD_0402
C24, C25: 100pF; SMD_0402
D11: Led_Diode; Diode_0603
J1: Connector_01x03; PinHeader_1x3_P2.5mm
J2: USB_MicroB; USB_MicroB_TH
J3: Connector_01x06; PinHeader_1x6_P2.5mm
R1, R10, R13, R20: 1K; SMD_0402
R5, R6, R12, R74: 22; SMD_0402
R7, R8, R16: 100; SMD_0402
R9, R11: 2.49K; SMD_0402
R14: 49.9; SMD_0402
R15, R23, R72, R73: DNP; SMD_0402
R17, R19: 4.7K; SMD_0402
R18, R21, R22: 10K; SMD_0402
R24: 0; SMD_0402
SW1: DFU_Button; Button_B3U_1000P
SW2: Reset_Button; Button_B3U_1000P
U1: MCP4022; SOT23_6
U2: LT1817GN; SSOP16_3.9x4.9mm_P0.635mm
U3, U39, U40, U41: Check_Point; SolderPad_1_1.5mm_SMD_Circle
U4: STM32F405; LQFP64_10x10mm_P0.5mm
U25: ADC_Connector; SolderPad_1_1.5mm_SMD_Circle
U37: MicroCard; MICROCARD_DM3AT_SF_PEJM5
U45: MAX1426; SSOP28_5.3x10.2mm_P0.65mm
U47, U48, U49, U50, U51: Check_Point; SolderPad_1_1.2mm_SMD_Circle
Y1: 8MHz; Crystal_3.2x2.5mm

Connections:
+3.3: C2.1, C3.1, C4.1, C5.1, C6.1, C11.1, C30.2, C31.2, J3.2, SW1.2, U4.1 (VBAT), U4.13 (VDDA), U4.19 (VDD), U4.32 (VDD), U4.48 (VDD), U4.64 (VDD), U37.4 (VDD), U45.20 (DVDD), U45.22 (DVDD); also elsewhere on the board
+5: C1.1, C10.1, C21.1, C22.1, C23.1, C24.1, C25.1, J2.1 (VBUS), J3.1, R24.2, U1.1 (VDD), U2.4 (V+), U45.2 (AVDD), U45.8 (AVDD); also elsewhere on the board
/SYNC: U4.62 (PB9), U41.1
ADC_CLK: R12.2, U4.42 (PA9), U45.13 (CLK)
ADC_IN+: C18.1, R72.2, U45.9 (INP)
ADC_IN-: C19.1, R73.1, U45.10 (INN)
ADC_OE: U4.54 (PD2), U45.14 (~OE~/PD)
ADF_CE: U4.24 (PC4), U49.1; also elsewhere on the board
ADF_CLK: R74.1, U47.1; also elsewhere on the board
ADF_DATA: U4.53 (PC12), U48.1; also elsewhere on the board
ADF_LE: U4.16 (PA2), U50.1; also elsewhere on the board
ADF_MUXOUT: U4.15 (PA1), U51.1; also elsewhere on the board
ADF_TXDATA: U4.25 (PC5); also elsewhere on the board
CML: C26.2, R9.1, U45.6 (CML)
CMLP: R23.1, R24.1, U45.11 (CMLP)
CM_BIAS: C8.2, R10.1, R11.2, R14.1, R17.2, R18.1
D0: U4.29 (PB10), U45.28 (D0)
D1: U4.30 (PB11), U45.27 (D1)
D2: U4.33 (PB12), U45.26 (D2)
D3: U4.34 (PB13), U45.25 (D3)
D4: U4.35 (PB14), U45.24 (D4)
D5: U4.36 (PB15), U45.19 (D5)
D6: U4.37 (PC6), U45.18 (D6)
D7: U4.38 (PC7), U45.17 (D7)
D8: U4.39 (PC8), U45.16 (D8)
D9: U4.40 (PC9), U45.15 (D9)
DAC_OUT1: U4.20 (PA4); also elsewhere on the board
DET_OUT: U4.26 (PB0); also elsewhere on the board
GND: C1.2, C2.2, C3.2, C4.2, C5.2, C6.2, C8.1, C10.2, C11.2, C14.2, C15.2, C16.2, C17.2, C20.2, C21.2, C22.2, C23.2, C24.2, C25.2, C26.1, C27.2, C28.2, C29.2, C30.1, C31.1, J2.5 (GND), J3.3, R1.2, R20.1, R23.2, SW2.2, U1.2 (VSS), U2.13 (V-), U4.12 (VSSA), U4.18 (VSS), U4.28 (PB2(BOOT1)), U4.63 (VSS), U37.6 (VSS), U37.10 (DETA), U37.11 (SHIELD), U45.1 (AGND), U45.7 (AGND), U45.12 (CMLN), U45.21 (DGND), U45.23 (DGND), Y1.2, Y1.4; also elsewhere on the board
IFF+: R7.1; also elsewhere on the board
IFF-: R8.1; also elsewhere on the board
LED: D11.2 (A), U4.8 (PC0)
MCP_AOUT: R16.1, U1.6 (A)
MCP_CS_3V3: U1.4 (~CS), U4.11 (PC3)
MCP_UD_3V3: U1.3 (U/~D), U4.10 (PC2)
MCP_WIN: C12.1, R15.2, U1.5 (W)
MICROCARD_CS: U4.17 (PA3), U37.2 (DAT3/CD)
MIXER_EN: U4.14 (PA0); also elsewhere on the board
unnamed: C7.1, R14.2, U2.16
unnamed: C7.2, R11.1, U2.15 (-)
unnamed: C9.2, R8.2, R13.1, U2.2 (-)
unnamed: C9.1, C12.2, R13.2, U2.1
unnamed: C13.1, C18.2, R19.2, R21.1, U2.7
unnamed: C13.2, R16.2, R19.1, U2.6 (-)
unnamed: C14.1, U4.31 (VCAP_1)
unnamed: C15.1, U4.47 (VCAP_2)
unnamed: C16.1, U4.5 (PH0(OSC_IN)), Y1.3
unnamed: C17.1, U4.6 (PH1(OSC_OUT)), Y1.1
unnamed: C19.2, R22.2, U2.10
unnamed: C27.1, U45.4 (REFIN)
unnamed: C28.1, U45.3 (REFP)
unnamed: C29.1, U45.5 (REFN)
unnamed: D11.1 (K), R1.1
unnamed: J2.2 (D-), R5.1
unnamed: J2.3 (D+), R6.1
unnamed: R9.2, U2.14 (+)
unnamed: R7.2, R10.2, U2.3 (+)
unnamed: R12.1, U4.43 (PA10)
unnamed: R15.1, U3.1
unnamed: R17.1, U2.12 (+)
unnamed: R18.2, U2.5 (+)
unnamed: R20.2, SW1.1, U4.60 (BOOT0)
unnamed: R21.2, R22.1, U2.11 (-)
unnamed: R72.1, U39.1
unnamed: R73.2, U40.1
unnamed: R74.2, U4.51 (PC10)
unnamed: U4.9 (PC1), U25.1
PA_EN: U4.27 (PB1); also elsewhere on the board
PB5: J1.1, U4.57 (PB5)
PB6: J1.2, U4.58 (PB6)
PB7: J1.3, U4.59 (PB7)
RESET: C20.1, J3.6, SW2.1, U4.7 (NRST)
SPI1_CLK: U4.21 (PA5), U37.5 (CLK)
SPI1_MISO: U4.22 (PA6), U37.7 (DAT0)
SPI1_MOSI: U4.23 (PA7), U37.3 (CMD)
SWDCLK: J3.4, U4.49 (PA14(SWCLK))
SWDIO: J3.5, U4.46 (PA13(SWDIO))
USB_D+: R6.2, U4.45 (PA12)
USB_D-: R5.2, U4.44 (PA11)

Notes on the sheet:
SPI1_MOSI
SPI1_CLK
ADC12_IN8
For AC Coupled Connect to 5V For DC Coupled Connect to GND
Common Mode Level can accept external voltage when the internal reference is disabled by REFN = AGND
AC Coupling is filtering and removing DC bias level so only AC signal DC Coupling is both DC bias and AC signal is present.
DIFFERENTIAL TO SINGLE CONVERTED OPAMP VOUT = GAIN X (IFP - IFN)
INVERTING AMPLIFIER VOUT = -(4.7K / MCP4022 + 100)
TIM1 CH2
EXTERNAL INTERRUPT FOR RISING EDGE ALSO HAS TIMER FUNCTIONALLITY
SPI1_MISO
TIM1 CH3 EXTI
I placed connections to be able to draw traces easy on pcb
SPI3_CLK
SPI3_MISO
SPI3_MOSI

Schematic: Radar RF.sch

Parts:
C32, C35, C36, C41, C43, C44, C46, C49, C50, C51, C56, C58, C59, C66, C70, C80, C84, C85, C86, C87, C88, C109, C110: 100nF; SMD_0402
C33: 470pF; SMD_0402
C37, C38, C42: 18pF; SMD_0402
C39, C40, C52, C60, C61, C67, C68, C76: 10pF; SMD_0402
C45, C47, C48, C53, C79: 100pF; SMD_0402
C55: 330nF; SMD_0402
C57, C73, C74, C75, C77, C78: 10nF; SMD_0402
C62: 2.2nF; SMD_0402
C63, C64, C89: 10uF; SMD_0603
C65, C71: DNP; SMD_0402
C69: 2.2uF; SMD_0402
C72, C81, C82, C90: 1nF; SMD_0402
C83: 0.5pF; SMD_0402
D9, D10: Led_Diode; Diode_0603
L1, L4, L5, L8, L9: BLM18PG181SN1D; SMD_0603
L2, L3: 2.2uH; SMD_0603
L6: LQW18ANR10J00D; SMD_0603
L7: 0.6nH; SMD_0402
R2, R3, R33, R35: 0; SMD_0402
R25, R29, R59: 50; SMD_0402
R26: 5.49K; SMD_0402
R27, R28, R31, R75: DNP; SMD_0402
R30, R39, R40, R46, R49, R56, R79, R80: 1K; SMD_0402
R32: 240; SMD_0402
R36, R37: 4.7K; SMD_0402
R38: 100K; SMD_0402
R41, R42: 10K; SMD_0402
R43: 1.8; SMD_0402
R44, R45: 910; SMD_0402
R47, R48: 130; SMD_0402
R50, R51: 4.99K; SMD_0402
R52, R77, R78: 16.7; SMD_0402
R57: 0 to 27; SMD_0402
R58: 30K; SMD_0402
R76: 100; SMD_0402
U5, U10, U11, U14, U16, U24, U26, U34, U36, U46: Check_Point; SolderPad_1_1.5mm_SMD_Circle
U6: SG-210STF; Crystal_2.5x2mm
U7, U13: 5400BL15B050E; Balun_5400BL15B050E
U8: ADF4158; LFCSP24_4x4mm_P0.5mm_1EXP_2.5x2.5mm
U9: ADL5801; LFCSP24_4x4mm_P0.5mm_1EXP_2.5x2.5mm
U12: TLV172; SC70_5
U15: LT6232; SSOP16_3.9x4.9mm_P0.635mm
U17: HMC431LP4; QFN24_4x4mm_P0.5mm_1EXP_2.7x2.7mm
U18: TRF37A75; WSON8_2x2mm_P0.5mm_1EXP_0.9x1.6mm
U19, U27: PAT1220-C-6DB; PAT1220_6dB
U20: SKY65404; SKY65404_31
U21: TQP5523; QFN20_4x4mm_P0.5mm_1EXP_2.5x2.5mm
U22, U30: SMA_Connector
U23, U28, U42, U43, U44: MITERED_BEND; Mitered_Bend_0.33mm_90
U29: Directional_Coupler; Directional_Coupler_15dB

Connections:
+2.5: R46.2, R47.2, R48.1, R49.2, U15.3 (+), U15.5 (+); also elsewhere on the board
+3.0: L4.2; also elsewhere on the board
+3.3: C32.1, C35.1, C36.1, C37.1, C38.1, C109.1, L9.1, U6.1 (ST), U6.4 (VCC), U8.6 (AVDD), U8.7 (AVDD), U8.8 (AVDD), U8.18 (SDVDD), U8.19 (DVDD); also elsewhere on the board
+5: C41.2, C43.2, C44.2, C45.2, C47.2, C56.2, C58.1, C66.2, C71.1, C110.2, L1.2, L5.1, L8.1, R25.1, R29.2, R30.1, U9.7 (VPLO), U9.13 (VPDT), U9.18 (VPRF), U9.24 (VPLO), U15.4 (V+); also elsewhere on the board
+10: C59.1, U12.5 (V+); also elsewhere on the board
/Radar RF/LNA_3.3: C84.1, C86.1, D10.2 (A), L7.2, L9.2, R76.1
ADF_CE: U8.13 (CE); also elsewhere on the board
ADF_CLK: U8.14 (CLK); also elsewhere on the board
ADF_DATA: U8.15 (DATA); also elsewhere on the board
ADF_LE: U8.16 (LE); also elsewhere on the board
ADF_MUXOUT: U8.17 (MUX_OUT), U36.1; also elsewhere on the board
ADF_TXDATA: U8.12 (TXDATA); also elsewhere on the board
DAC_OUT1: R75.1, U11.1; also elsewhere on the board
DET_OUT: R58.1, U21.10 (DET), U24.1; also elsewhere on the board
GND: C32.2, C35.2, C36.2, C37.2, C38.2, C41.1, C42.2, C43.1, C44.1, C45.1, C46.2, C47.1, C48.2, C49.1, C50.1, C51.1, C53.1, C56.1, C57.2, C58.2, C59.2, C65.2, C66.1, C69.2, C70.2, C71.2, C75.2, C76.2, C79.2, C80.2, C83.2, C84.2, C85.2, C86.2, C87.1, C88.1, C89.1, C109.2, C110.1, R26.2, R31.2, R32.1, R37.2, R56.2, R58.2, R59.2, R79.2, R80.2, U6.2 (GND), U7.2 (GND), U7.5 (GND), U8.1 (CPGND), U8.2 (AGND), U8.3 (AGND), U8.10 (DGND), U8.11 (SDGND), U8.25 (EXP), U9.1 (GND), U9.2 (GND), U9.5 (GND), U9.6 (GND), U9.8 (GND), U9.12 (GND), U9.14 (GND), U9.17 (GND), U9.19 (GND), U9.23 (GND), U9.25 (EXP), U12.2 (V-), U13.2 (GND), U13.5 (GND), U15.13 (V-), U17.15 (GND), U17.25 (EXP), U18.3 (NC), U18.4 (NC), U18.5 (PWDN), U18.6 (NC), U18.8 (NC), U18.9 (GND), U19.3 (GND), U20.2 (GND), U20.5 (GND), U20.7 (EXP), U21.1 (GND), U21.2 (GND), U21.4 (GND), U21.11 (GND), U21.12 (GND), U21.14 (GND), U21.15 (GND), U21.16 (GND), U21.17 (GND), U21.21 (EXP), U22.2, U22.3, U22.4, U22.5, U27.3 (GND), U30.2, U30.3, U30.4, U30.5, U46.1; also elsewhere on the board
IF+: L2.1, R29.1, U5.1, U9.20 (IFOP)
IF-: L3.1, R25.2, U9.21 (IFON), U16.1
IFF+: R44.1, R50.1, U15.16; also elsewhere on the board
IFF-: R45.2, R51.1, U15.10; also elsewhere on the board
MIXER_EN: U9.9 (ENBL); also elsewhere on the board
MIXER_LO: U7.1 (IN), U23.2
unnamed: C33.1, U8.9 (REF_IN)
unnamed: C33.2, U6.3 (OUT)
unnamed: C39.1, U9.3 (LOIP)
unnamed: C39.2, U7.4 (OUTN)
unnamed: C40.1, U9.4 (LOIN)
unnamed: C40.2, U7.3 (OUTP)
unnamed: C42.1, C46.1, L1.1, U8.22 (VP)
unnamed: C48.1, U8.4 (RFINB)
unnamed: C49.2, C51.2, R27.2, R30.2, R31.1, U9.10 (VSET)
unnamed: C50.2, C53.2, R27.1, U9.11 (DETO)
unnamed: C52.1, U8.5 (RFINA)
unnamed: C52.2, U44.2
unnamed: C55.1, C57.1, R33.1, U8.24 (CP), U10.1
unnamed: C55.2, R28.2, R32.2
unnamed: C60.1, U13.4 (OUTN)
unnamed: C61.1, U13.3 (OUTP)
unnamed: C62.1, C63.2, L2.2
unnamed: C62.2, C64.2, L3.2
unnamed: C63.1, R39.1
unnamed: C64.1, R40.1
unnamed: C65.1, R38.1, U14.1, U17.22 (VTUNE)
unnamed: C67.1, R2.1, R41.2, U15.1, U26.1
unnamed: C67.2, R39.2, R41.1, U15.2 (-)
unnamed: C68.1, R3.1, R42.2, U15.7, U34.1
unnamed: C68.2, R40.2, R42.1, U15.6 (-)
unnamed: C69.1, C70.1, L4.1, U17.20 (VCC)
unnamed: C72.1, L6.1, U18.7 (RFOUT)
unnamed: C72.2, U42.2
unnamed: C73.1, C77.2, R44.2
unnamed: C73.2, R2.2
unnamed: C74.1, C78.2, R45.1
unnamed: C74.2, R3.2
unnamed: C75.1, C76.1, L6.2, R43.2
unnamed: C77.1, R47.1, U15.14 (+)
unnamed: C78.1, R48.2, U15.12 (+)
unnamed: C79.1, C80.1, L5.2, R43.1, U18.1 (VCC)
unnamed: C81.1, U20.4 (RF_OUT)
unnamed: C81.2, U18.2 (RFIN)
unnamed: C82.1, U21.3 (RFIN)
unnamed: C82.2, U19.2 (OUT)
unnamed: C83.1, U20.3 (RF_IN), U22.1
unnamed: C85.1, R57.2, U21.20 (VCC1)
unnamed: C87.2, C88.2, C89.2, L8.2, R57.1, U21.18 (VCC3), U21.19 (VCC2)
unnamed: C90.1, U29.1 (IN)
unnamed: C90.2, U21.13 (RFOUT)
unnamed: D9.1 (K), R79.1
unnamed: D10.1 (K), R80.1
unnamed: L7.1, U20.6 (VCC)
unnamed: R26.1, U8.23 (RSET)
unnamed: R28.1, U8.20 (SW1)
unnamed: R33.2, R75.2, U12.1 (+)
unnamed: R35.1, R38.2, U12.4
unnamed: R35.2, R36.1
unnamed: R36.2, R37.1, U12.3 (-)
unnamed: R46.1, R50.2, U15.15 (-)
unnamed: R49.1, R51.2, U15.11 (-)
unnamed: R52.1, U17.16 (RFOUT)
unnamed: R52.2, R77.1, R78.2
unnamed: R59.1, U29.4 (TRM)
unnamed: R76.2, U20.1 (V_ENA)
unnamed: R77.2, U19.1 (IN)
unnamed: R78.1, U43.2
unnamed: U13.1 (IN), U42.1
unnamed: U23.1, U28.1
unnamed: U27.1 (IN), U29.3 (CPL)
unnamed: U27.2 (OUT), U28.2
unnamed: U29.2 (OUT), U30.1
unnamed: U43.1, U44.1
PA_EN: D9.2 (A), R56.1, U21.5 (PA_EN); also elsewhere on the board
RFIN: C60.2, U9.15 (RFIN)
RFIP: C61.2, U9.16 (RFIP)

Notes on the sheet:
Scale 3.3V DAC output to 10V
Scale 5V PLL output to 10V
If DAC will be used change R35(0) with 4.7K to make gain 3
RC filter makes it noisy. I just placed 100K series resistor to filter noise.
Max 0dBm -4dBm input
-4dBm
29 to 37dB, typ. 32dB Gain OP1dB 31dBm Pout = 22 to 27dBm Pout = 21dBm 5V, 300mA
WYE -6dBm resistive splitter Zo/3 each apprx. 17 ohm
-10dBm
100mW rating
TX ANTENNA
16dB Directional Coupler
-16dB
Pout = 6 to 11 dBm - 6 dB = 0 to 5 dBm
Pout = 22 to 27dBm - 16dB = 6 to 11 dBm
RX ANTENNA
Max Input Power: 1dBm NF: 1dB Gain: 12dB at 6GHz IIP3: 9 dBm IP1dB: -4 dBm
Max 1dBm input to LNA
Max Input Power: 10 dBm NF: 4.0 dB Gain: 11 dB at 6 GHz OIP3: 23 dBm OP1dB: 12 dBm
-1dB Insertion Loss
Idd = 32mA max
Pout 2dBm @3v, 27mA
PI Type Attenuator Network 1 and 2 can be both in/out, directionless
@3.0 max 15mA
@5.0v, max 100mA
IIP3 28.5 dBm IP1dB 11dBm for 5-6GHz LO drive 0dBm @5v, max 200mA typ 130mA
Input 2 MHz LC low pass filter. 10uF for AC coupling capactior to remove DC offset. 1st stage opamp is amplifier. 2nd stage opamp is sallen key high pass filter IMPORTANT NOTE: Sallen Key filter calculator has oscillation calculation to show if it oscillates. Be careful when changing the numbers Th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
ADF4158 is Freq. Synthesizer to form a PLL topology. It requires a referance clock and an external VCO. It is not a PLL itself. It is used to drive VCO in a way the user wants. So it takes ref clock and VCO output and generates voltage through charge pump to generate the waveform wanted.(sawtooth e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
50 Ohm to 50 Ohm Balun for Single to Differential
4.5 to 5.25 range
30MHz
2.8 to 5.0 range
+2dBm Output
330nF 10nF 240 Ohm has no oscillation
Sallen Key filter requires isolation resistor to prevent oscillation. The capacitive load makes it unstable. To attenuate the peak value of 1.4MHz oscillation i changed differential to single ended 1K to 100 Ohm and added gain.

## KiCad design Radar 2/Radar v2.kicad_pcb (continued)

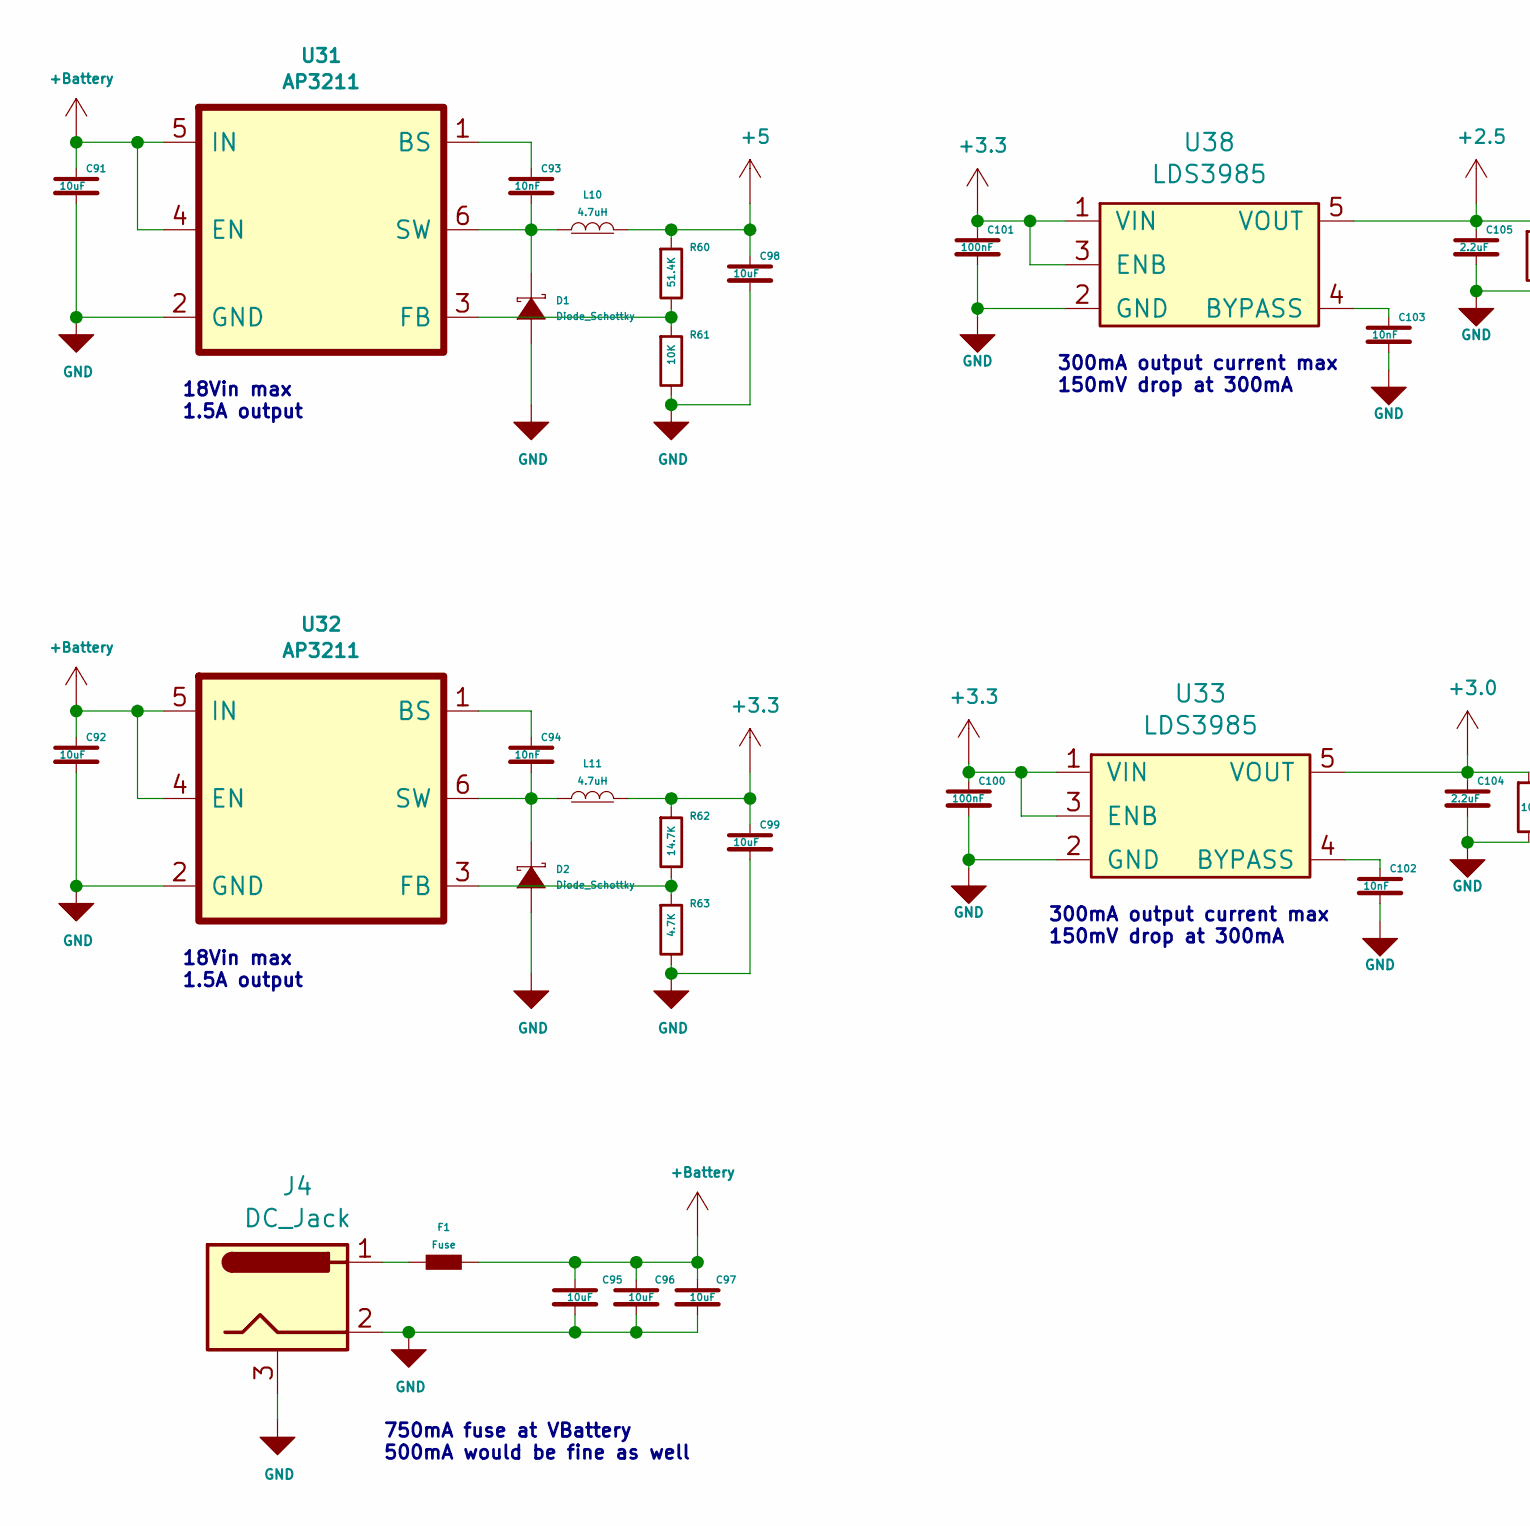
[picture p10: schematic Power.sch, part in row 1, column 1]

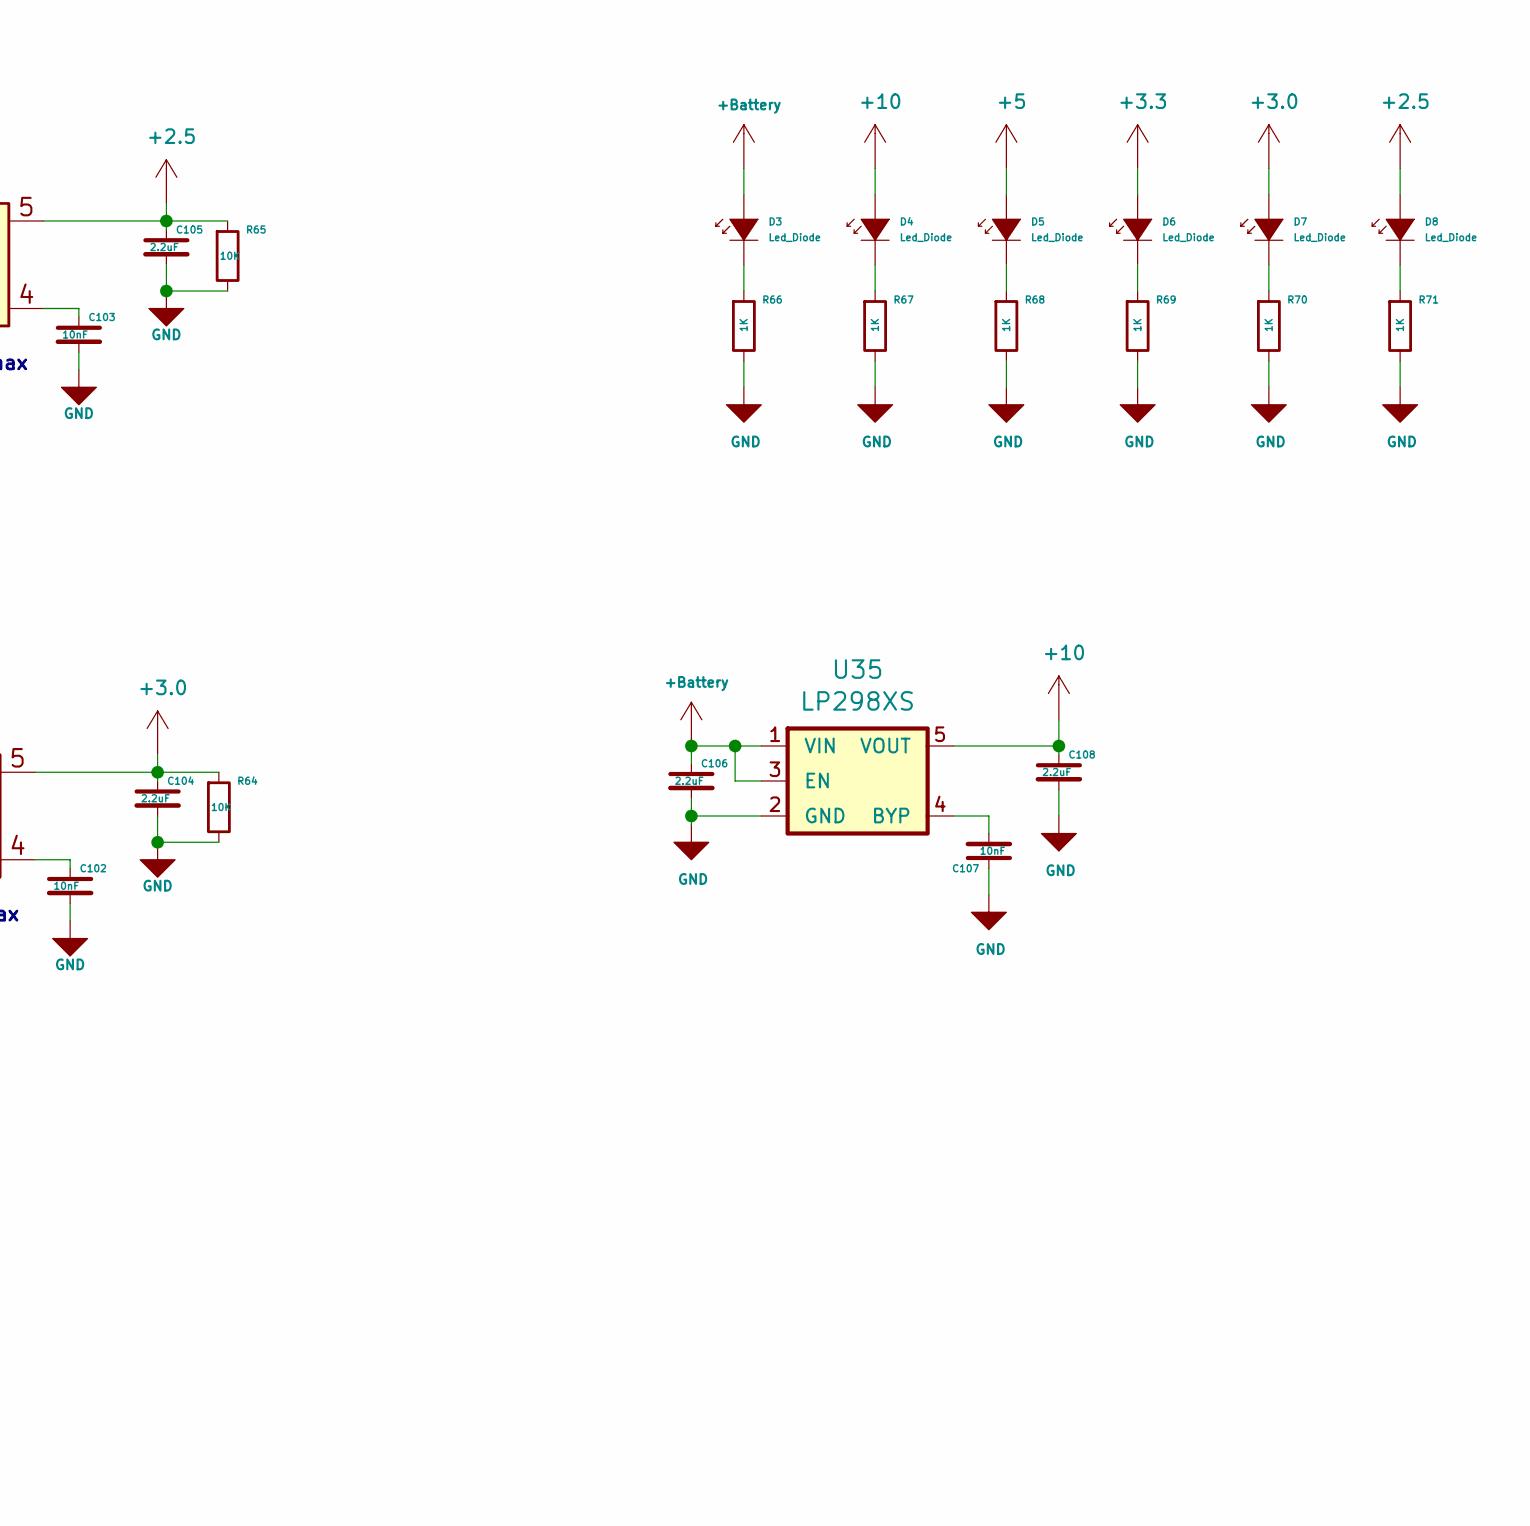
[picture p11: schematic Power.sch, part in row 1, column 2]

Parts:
C91, C92, C95, C96, C97, C98, C99: 10uF; SMD_0603
C93, C94, C102, C103, C107: 10nF; SMD_0402
C100, C101: 100nF; SMD_0402
C104, C105, C106, C108: 2.2uF; SMD_0603
D1, D2: Diode_Schottky; Diode_SDM2U30CSP_7
D3, D4, D5, D6, D7, D8: Led_Diode; Diode_0603
F1: Fuse; SMD_0805
J4: DC_Jack; BarrelJack
L10, L11: 4.7uH; SMD_0805
R60: 51.4K; SMD_0402
R61, R64, R65: 10K; SMD_0402
R62: 14.7K; SMD_0402
R63: 4.7K; SMD_0402
R66, R67, R68, R69, R70, R71: 1K; SMD_0402
U31, U32: AP3211; SOT23_6
U33, U38: LDS3985; SOT23_5
U35: LP298XS; SOT23_5

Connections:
+2.5: C105.1, D8.2 (A), R65.1, U38.5 (VOUT); also elsewhere on the board
+3.0: C104.1, D7.2 (A), R64.1, U33.5 (VOUT); also elsewhere on the board
+3.3: C99.1, C100.1, C101.1, D6.2 (A), L11.2, R62.1, U33.1 (VIN), U33.3 (ENB), U38.1 (VIN), U38.3 (ENB); also elsewhere on the board
+5: C98.1, D5.2 (A), L10.2, R60.1; also elsewhere on the board
+10: C108.1, D4.2 (A), U35.5 (VOUT); also elsewhere on the board
+Battery: C91.1, C92.1, C95.1, C96.1, C97.1, C106.1, D3.2 (A), F1.2, U31.4 (EN), U31.5 (IN), U32.4 (EN), U32.5 (IN), U35.1 (VIN), U35.3 (EN)
GND: C91.2, C92.2, C95.2, C96.2, C97.2, C98.2, C99.2, C100.2, C101.2, C102.2, C103.2, C104.2, C105.2, C106.2, C107.1, C108.2, D1.2 (A), D2.2 (A), J4.2, J4.3, R61.2, R63.2, R64.2, R65.2, R66.2, R67.2, R68.2, R69.2, R70.2, R71.2, U31.2 (GND), U32.2 (GND), U33.2 (GND), U35.2 (GND), U38.2 (GND); also elsewhere on the board
unnamed: C93.1, U31.1 (BS)
unnamed: C93.2, D1.1 (C), L10.1, U31.6 (SW)
unnamed: C94.1, U32.1 (BS)
unnamed: C94.2, D2.1 (C), L11.1, U32.6 (SW)
unnamed: C102.1, U33.4 (BYPASS)
unnamed: C103.1, U38.4 (BYPASS)
unnamed: C107.2, U35.4 (BYP)
unnamed: D3.1 (K), R66.1
unnamed: D4.1 (K), R67.1
unnamed: D5.1 (K), R68.1
unnamed: D6.1 (K), R69.1
unnamed: D7.1 (K), R70.1
unnamed: D8.1 (K), R71.1
unnamed: F1.1, J4.1
unnamed: R60.2, R61.1, U31.3 (FB)
unnamed: R62.2, R63.1, U32.3 (FB)

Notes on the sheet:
300mA output current max 150mV drop at 300mA
18Vin max 1.5A output
750mA fuse at VBattery 500mA would be fine as well

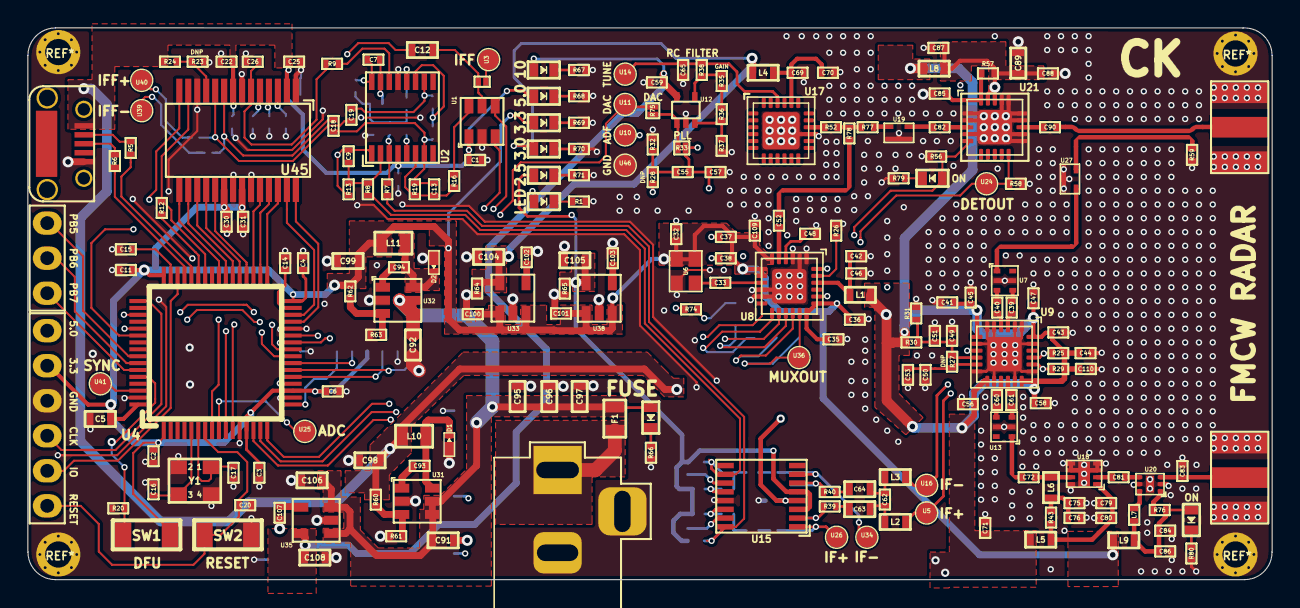
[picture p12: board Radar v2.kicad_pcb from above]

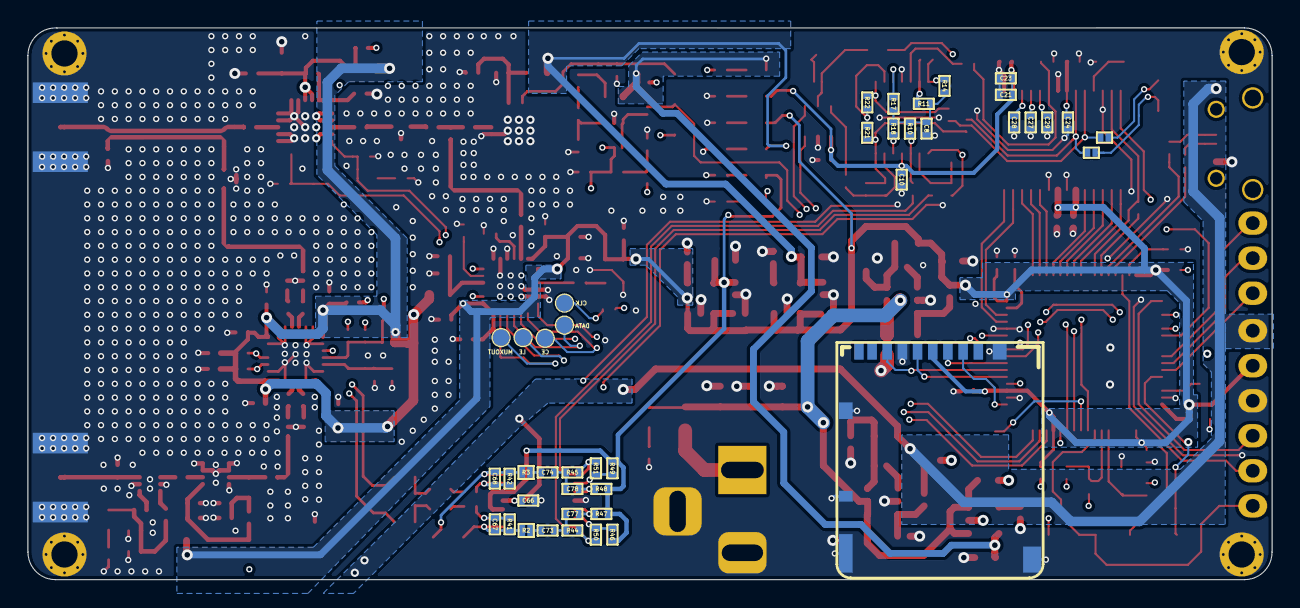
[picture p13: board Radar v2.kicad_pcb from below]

Board: 4 copper layers, 90.2 x 40.0 mm, 264 parts (42 on the bottom side), 173 nets.

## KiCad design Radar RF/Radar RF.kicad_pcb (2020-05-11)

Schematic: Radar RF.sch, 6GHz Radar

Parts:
C12, C13, C14, C21, C22, C28, C37, C38, C39, C40, C43, C45, C46, C48, C50, C51, C52, C53, C64, C67, C69, C74, C75: 100nF; SMD_0402
C15, C16, C18, C59, C68: 18pF; SMD_0402
C17: 2.2nF; SMD_0402
C19, C20, C26: 330nF; SMD_0402
C23, C41, C42, C47, C65: 100pF; SMD_0402
C24, C25, C35, C36, C54, C55, C62: 10pF; SMD_0402
C27: 2pF; SMD_0402
C29, C31, C32, C33, C34, C44: 470pF; SMD_0402
C30, C56, C61: 10nF; SMD_0402
C49, C57, C63, C71: 2.2uF; SMD_0402
C58, C66: DNP; SMD_0402
C60, C72: 1000pF; SMD_0402
C70: 10uF; SMD_0603
C73: 0.5pF; SMD_0402
D1, D2, D3: Led_Diode; Diode_0603
J1: Connector_02x15; PinHeader_2x15_DF12B(5.0)-30DP-0.5V(86)
L1, L2: 2.2uH; SMD_0603
L3: BLM18PG181SN1D; SMD_0603
L4: LQW15AN9N9J80D; SMD_0402
L5: 0.6nH; SMD_0402
R1, R16, R19, R29, R39, R40, R42: 1K; SMD_0402
R2, R3, R15, R27, R30: DNP; SMD_0402
R4, R12, R22, R35, R43: 0; SMD_0402
R5, R6: 549; SMD_0402
R7: 5.49K; SMD_0402
R8: 69.8; SMD_0402
R9, R10, R34: 10K; SMD_0402
R11: 240; SMD_0402
R13, R14: 910; SMD_0402
R17, R18: 130; SMD_0402
R20, R21: 4.99K; SMD_0402
R23, R24, R26: 4.7K; SMD_0402
R25, R28, R41: 50; SMD_0402
R31, R32, R33: 18; SMD_0402
R36: 0 to 27; SMD_0402
R37: 30K; SMD_0402
R38: 100; SMD_0402
U1: LT6232; SSOP16_3.9x4.9mm_P0.635mm
U2: ADF4158; LFCSP24_4x4mm_P0.5mm_1EXP_2.5x2.5mm
U3: SG-210STF; Crystal_2.5x2mm
U4, U9, U23: MITERED_BEND; Mitered_Bend_0.34mm_90
U5: MITERED_BEND; Mitered_Bend_0.34mm_45
U6, U13: 5400BL15B050E; Balun_5400BL15B050E
U7: TLV172; SC70_5
U8: MITERED_BEND; Mitered_Bend_0.34mm_45_Mirrored
U10: ADL5801; LFCSP24_4x4mm_P0.5mm_1EXP_2.5x2.5mm
U11: HMC431LP4; QFN24_4x4mm_P0.5mm_1EXP_2.7x2.7mm
U12: LDS3985; SOT23_5
U14, U19: PAT1220-C-6DB; PAT1220_6dB
U15: TRF37A73; WSON8_2x2mm_P0.5mm_1EXP_0.9x1.6mm
U16: TQP5523; QFN20_4x4mm_P0.5mm_1EXP_2.5x2.5mm
U17: MCP1700; SOT23_3
U18: SKY65404; SKY65404_31
U20: Directional_Coupler; Directional_Coupler_15dB
U21, U22: SMA_Connector
U24: IF+_PAD; SolderPad_1_1.5mm_SMD_Rectangle
U25: IF-_PAD; SolderPad_1_1.5mm_SMD_Rectangle
U26, U27: GND; SolderPad_1_1.5mm_SMD_Rectangle

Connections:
25MHz: C29.1, U2.9 (REF_IN)
+2V5: C57.1, R16.2, R17.2, R18.1, R19.2, R34.1, U1.3 (+), U1.5 (+), U12.5 (VOUT)
+3V0: C49.1, C51.1, C58.1, C71.1, C74.1, C75.1, D3.2 (A), L3.1, L5.2, R38.1, U11.20 (VCC), U17.2 (VOUT); also elsewhere on the board
+3V3: C12.1, C13.1, C14.1, C15.1, C16.1, C22.1, C53.1, C63.1, D2.2 (A), J1.4, J1.5, U2.6 (AVDD), U2.7 (AVDD), U2.8 (AVDD), U2.18 (SDVDD), U2.19 (DVDD), U3.1 (ST), U3.4 (VCC), U12.1 (VIN), U12.3 (ENB), U17.3 (VIN); also elsewhere on the board
+5V: C18.1, C21.1, C28.2, C38.2, C39.2, C40.2, C41.2, C42.2, C48.2, C50.2, C52.1, C67.2, C69.2, C70.2, D1.2 (A), J1.26, J1.27, J1.28, J1.29, R25.1, R28.2, R29.1, R36.1, U1.4 (V+), U2.22 (VP), U10.7 (VPLO), U10.13 (VPDT), U10.18 (VPRF), U10.24 (VPLO), U16.18 (VCC3), U16.19 (VCC2); also elsewhere on the board
+10V: C37.1, J1.22, U7.5 (V+)
ADF_CE: J1.10, U2.13 (CE)
ADF_CLK: J1.11, U2.14 (CLK)
ADF_DATA: J1.12, U2.15 (DATA)
ADF_LE: J1.13, U2.16 (LE)
ADF_MUXOUT: J1.14, U2.17 (MUX_OUT)
ADF_TXDATA: J1.9, U2.12 (TXDATA)
DAC_OUT1: J1.2, R15.1
DET_OUT: J1.8, R37.1, U16.10 (DET)
GND: C12.2, C13.2, C14.2, C15.2, C16.2, C18.2, C21.2, C22.2, C23.2, C28.1, C30.2, C37.2, C38.1, C39.1, C40.1, C41.1, C42.1, C43.1, C44.2, C45.1, C46.1, C47.1, C48.1, C49.2, C50.1, C51.2, C52.2, C53.2, C56.2, C57.2, C58.2, C61.2, C62.2, C63.2, C64.2, C65.2, C66.2, C67.1, C69.1, C70.1, C71.2, C73.2, C74.2, C75.2, J1.1, J1.3, J1.6, J1.16, J1.17, J1.20, J1.21, J1.23, J1.24, J1.25, J1.30, R1.2, R7.2, R11.1, R24.2, R30.2, R34.2, R37.2, R39.2, R40.2, R41.2, R42.2, U1.13 (V-), U2.1 (CPGND), U2.2 (AGND), U2.3 (AGND), U2.10 (DGND), U2.11 (SDGND), U2.25 (EXP), U3.2 (GND), U6.2 (GND), U6.5 (GND), U7.2 (V-), U10.1 (GND), U10.2 (GND), U10.5 (GND), U10.6 (GND), U10.8 (GND), U10.12 (GND), U10.14 (GND), U10.17 (GND), U10.19 (GND), U10.23 (GND), U10.25 (EXP), U11.15 (GND), U11.25 (EXP), U12.2 (GND), U13.2 (GND), U13.5 (GND), U14.3 (GND), U15.3 (NC), U15.4 (NC), U15.5 (PWDN), U15.6 (NC), U15.8 (NC), U15.9 (GND), U16.1 (GND), U16.2 (GND), U16.4 (GND), U16.11 (GND), U16.12 (GND), U16.14 (GND), U16.15 (GND), U16.16 (GND), U16.17 (GND), U16.21 (EXP), U17.1 (GND), U18.2 (GND), U18.5 (GND), U18.7 (EXP), U19.3 (GND), U21.2, U21.3, U21.4, U21.5, U22.2, U22.3, U22.4, U22.5, U26.1, U27.1; also elsewhere on the board
IF+: R2.1, R4.1, R28.1, U10.20 (IFOP)
IF-: R3.2, R25.2, R43.2, U10.21 (IFON)
IFN_Filtered: J1.19, R14.2, R21.1, U1.10
IFP_Filtered: J1.18, R13.1, R20.1, U1.16
MIXER_ENB: J1.15, U10.9 (ENBL)
MIXER_LO: U4.2, U6.1 (IN)
unnamed: C17.1, C19.2, L1.2
unnamed: C17.2, C20.2, L2.2
unnamed: C19.1, R5.1
unnamed: C20.1, R6.1
unnamed: C23.1, U2.4 (RFINB)
unnamed: C24.1, C31.2, R9.2, U1.1
unnamed: C24.2, R5.2, R9.1, U1.2 (-)
unnamed: C25.1, C32.2, R10.2, U1.7
unnamed: C25.2, R6.2, R10.1, U1.6 (-)
unnamed: C26.1, C30.1, R12.1, U2.24 (CP)
unnamed: C26.2, R8.2, R11.2
unnamed: C27.1, U2.5 (RFINA)
unnamed: C27.2, R33.2
unnamed: C29.2, U3.3 (OUT)
unnamed: C31.1, C33.2, R13.2
unnamed: C32.1, C34.2, R14.1
unnamed: C33.1, R17.1, U1.14 (+)
unnamed: C34.1, R18.2, U1.12 (+)
unnamed: C35.1, U10.3 (LOIP)
unnamed: C35.2, U6.4 (OUTN)
unnamed: C36.1, U10.4 (LOIN)
unnamed: C36.2, U6.3 (OUTP)
unnamed 43: C43.2, C46.2, R27.2, R29.2, R30.1, U10.10 (VSET); also elsewhere on the board
unnamed: C44.1, R26.1, U11.22 (VTUNE)
unnamed 45: C45.2, C47.2, R27.1, U10.11 (DETO); also elsewhere on the board
unnamed: C54.1, U13.4 (OUTN)
unnamed: C55.1, U13.3 (OUTP)
unnamed: C56.1, U12.4 (BYPASS)
unnamed: C59.1, L4.1, U15.7 (RFOUT)
unnamed: C59.2, U23.1
unnamed: C60.1, U16.3 (RFIN)
unnamed: C60.2, U14.2 (OUT)
unnamed: C61.1, C62.1, C65.1, C66.1, L3.2, L4.2, U15.1 (VCC)
unnamed: C64.1, R36.2, U16.20 (VCC1)
unnamed: C68.1, U18.4 (RF_OUT)
unnamed: C68.2, U15.2 (RFIN)
unnamed: C72.1, U20.1 (IN)
unnamed: C72.2, U16.13 (RFOUT)
unnamed: C73.1, U18.3 (RF_IN), U22.1
unnamed 60: D1.1 (K), R39.1; also elsewhere on the board
unnamed 61: D2.1 (K), R40.1; also elsewhere on the board
unnamed 62: D3.1 (K), R42.1; also elsewhere on the board
unnamed: L1.1, R4.2
unnamed: L2.1, R43.1
unnamed: L5.1, U18.6 (VCC)
unnamed: R1.1, R35.2, U16.5 (PA_EN)
unnamed 67: R2.2, U24.1; also elsewhere on the board
unnamed 68: R3.1, U25.1; also elsewhere on the board
unnamed: R7.1, U2.23 (RSET)
unnamed: R8.1, U2.20 (SW1)
unnamed: R12.2, R15.2, U7.1 (+)
unnamed: R16.1, R20.2, U1.15 (-)
unnamed: R19.1, R21.2, U1.11 (-)
unnamed: R22.1, R26.2, U7.4
unnamed: R22.2, R23.1
unnamed: R23.2, R24.1, U7.3 (-)
unnamed: R31.1, U11.16 (RFOUT)
unnamed: R31.2, R32.2, R33.1
unnamed: R32.1, U14.1 (IN)
unnamed: R38.2, U18.1 (V_ENA)
unnamed: R41.1, U20.4 (TRM)
unnamed: U4.1, U8.1
unnamed: U5.1, U9.1
unnamed: U5.2, U8.2
unnamed: U13.1 (IN), U23.2
unnamed: U19.1 (IN), U20.3 (CPL)
unnamed: U9.2, U19.2 (OUT)
unnamed: U20.2 (OUT), U21.1
PA_EN: J1.7, R35.1
RFIN: C54.2, U10.15 (RFIN)
RFIP: C55.2, U10.16 (RFIP)

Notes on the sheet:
Scale 3.3V DAC output to 10V
Scale 5V PLL output to 10V
If DAC will be used change R22(0) with 4.7K to make gain 3
72KHz cutoff RC lowpass as PLL Loop Filter
+2dBm Output
Max 0dBm -4dBm input
-4dBm
32dB Gain Pout = 21 to 24dBm Pout = 21dBm 5V, 300mA
Delta -6dBm resistive splitter Zo/3 each apprx. 18 ohm
-10dBm
100mW rating
TX ANTENNA
16dB Directional Coupler
-16dB
Pout = 5 to 8 dBm - 6 dB = 0 to 2 dBm
Pout = 21 to 24dBm - 16dB = 5 to 8 dBm
RX ANTENNA
LNA NF: 1dB Gain: 13dB IIP3: 7dBm
Max 1dBm input to LNA
Max Input Power: 10 dBm NF: 4.5 dB Gain: 11 dB @ 5GHz
-1dB Insertion Loss
Idd = 32mA max
@3v, 27mA
@5v, 300mA
PI Type Attenuator Network 1 and 2 can be both in/out, directionless
@3v, max 15mA
@3v, max 65mA
@5v, max 200mA typ 130mA
Input has LC low pass filter. 330nF for AC coupling capactior to remove DC offset. 1st stage opamp is amplifier. 2nd stage opamp is sallen key high pass filter This filter both filteres high freq. and makes range compansation for objects at different distances.
250mA max 0.2v drop
300mA max
ADF4158 is Freq. Synthesizer to form a PLL topology. It requires a referance clock and an external VCO. It is not a PLL itself. It is used to drive VCO in a way the user wants. So it takes ref clock and VCO output and generates voltage through charge pump to generate the waveform wanted.(sawtooth e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
50 Ohm to 50 Ohm Balun for Single to Differential
I provide GND pad to send two cables parallel it can be used as return current if needed as a precausiton
If test the if without filtering i provided 0 ohm DNP pads to make necessary connections.

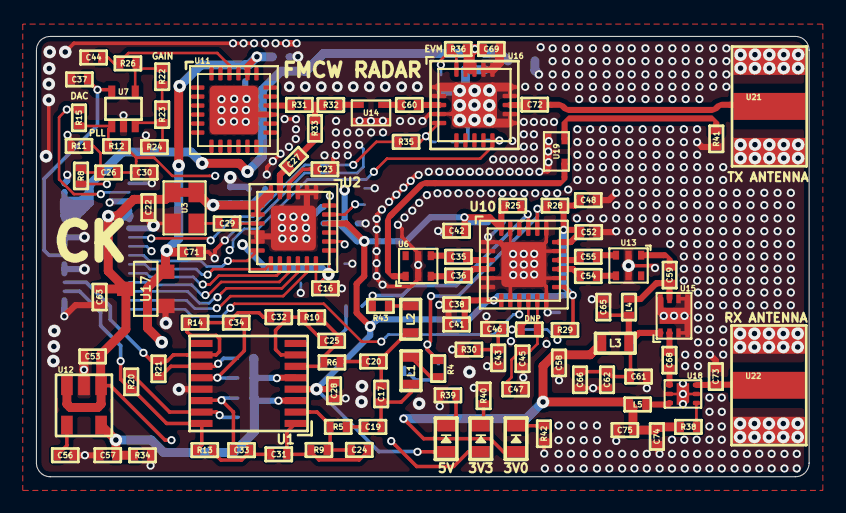
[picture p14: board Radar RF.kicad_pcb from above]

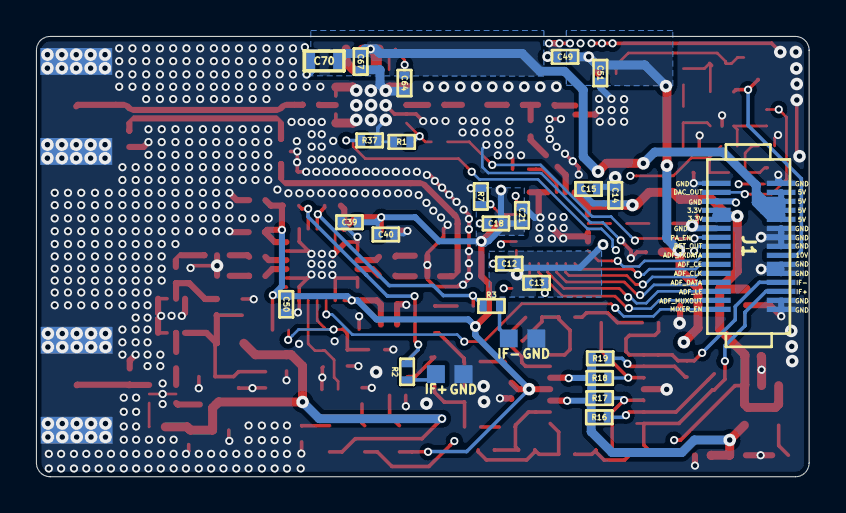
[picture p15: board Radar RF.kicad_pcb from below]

Board: 4 copper layers, 42.9 x 24.5 mm, 143 parts (28 on the bottom side), 92 nets.

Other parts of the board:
3V0, 3V3, 5V: Led_Diode; Diode_0603
DNP: DNP; SMD_0402
GND: GND; SolderPad_1_1.5mm_SMD_Rectangle
GND#2: GND; SolderPad_1_1.5mm_SMD_Rectangle
IF+: IF+_PAD; SolderPad_1_1.5mm_SMD_Rectangle
IF-: IF-_PAD; SolderPad_1_1.5mm_SMD_Rectangle

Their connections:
+3V0: 3V0.2; also elsewhere on the board
+3V3: 3V3.2; also elsewhere on the board
+5V: 5V.2; also elsewhere on the board
GND: GND.1, GND#2.1; also elsewhere on the board
unnamed 43: DNP.2; also elsewhere on the board
unnamed 45: DNP.1; also elsewhere on the board
unnamed 60: 5V.1; also elsewhere on the board
unnamed 61: 3V3.1; also elsewhere on the board
unnamed 62: 3V0.1; also elsewhere on the board
unnamed 67: IF+.1; also elsewhere on the board
unnamed 68: IF-.1; also elsewhere on the board

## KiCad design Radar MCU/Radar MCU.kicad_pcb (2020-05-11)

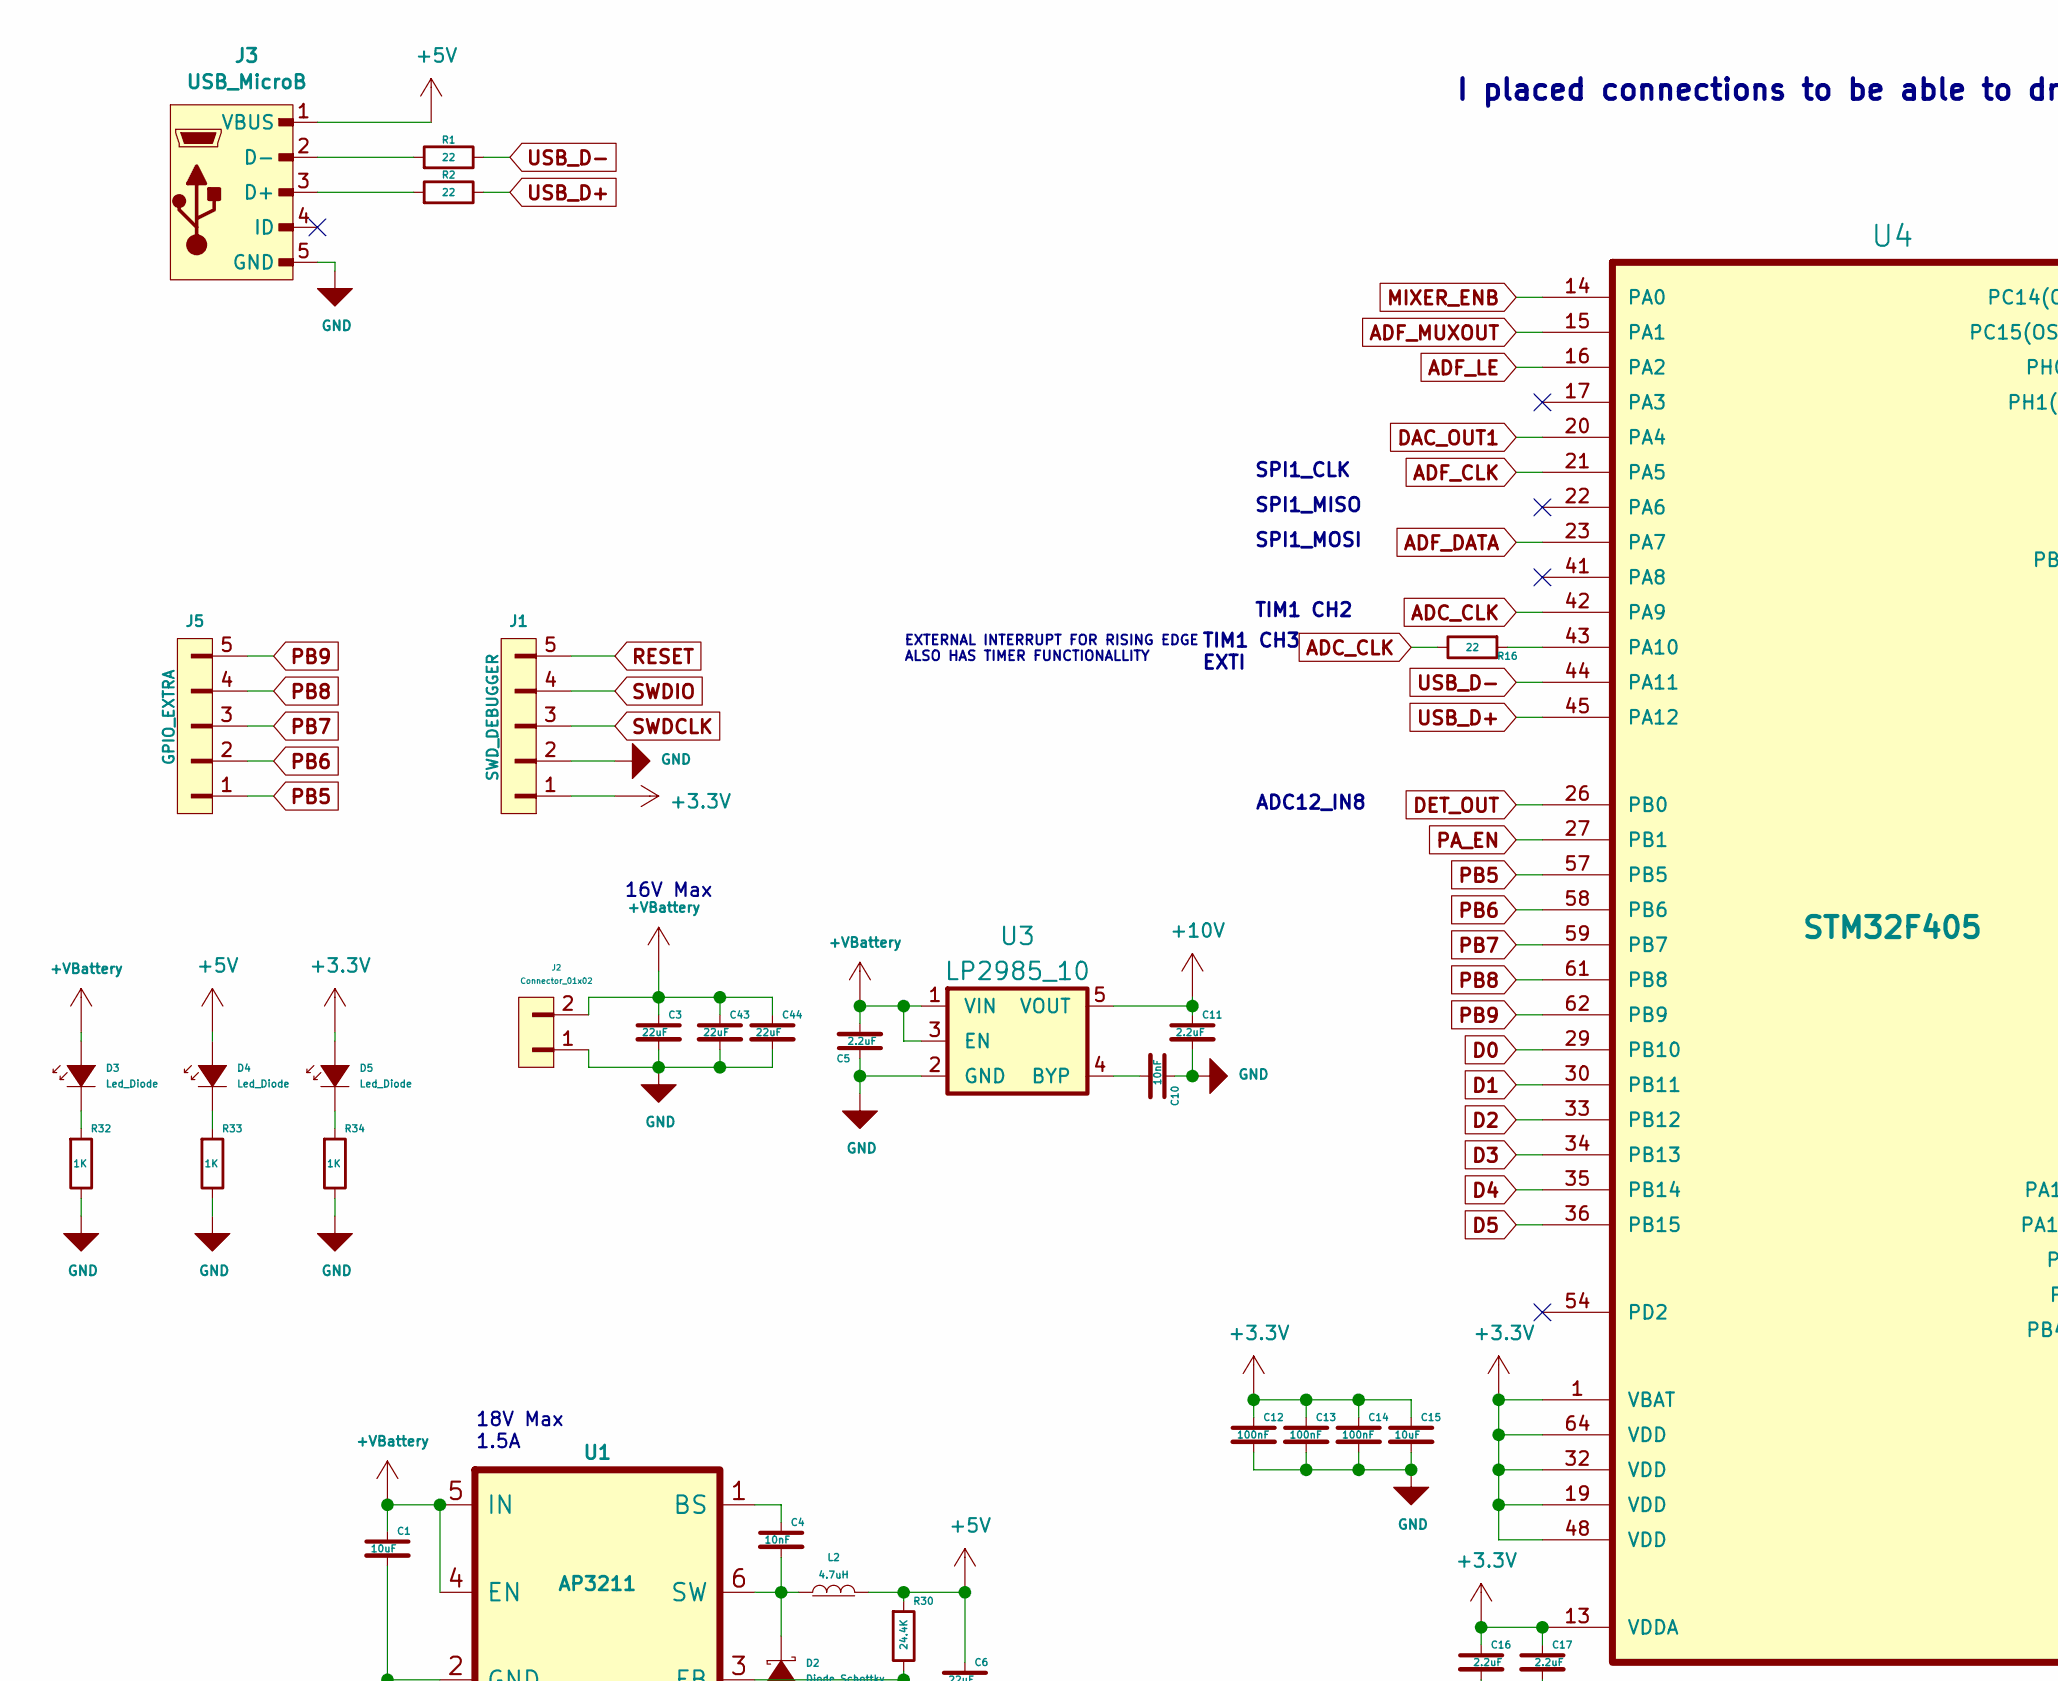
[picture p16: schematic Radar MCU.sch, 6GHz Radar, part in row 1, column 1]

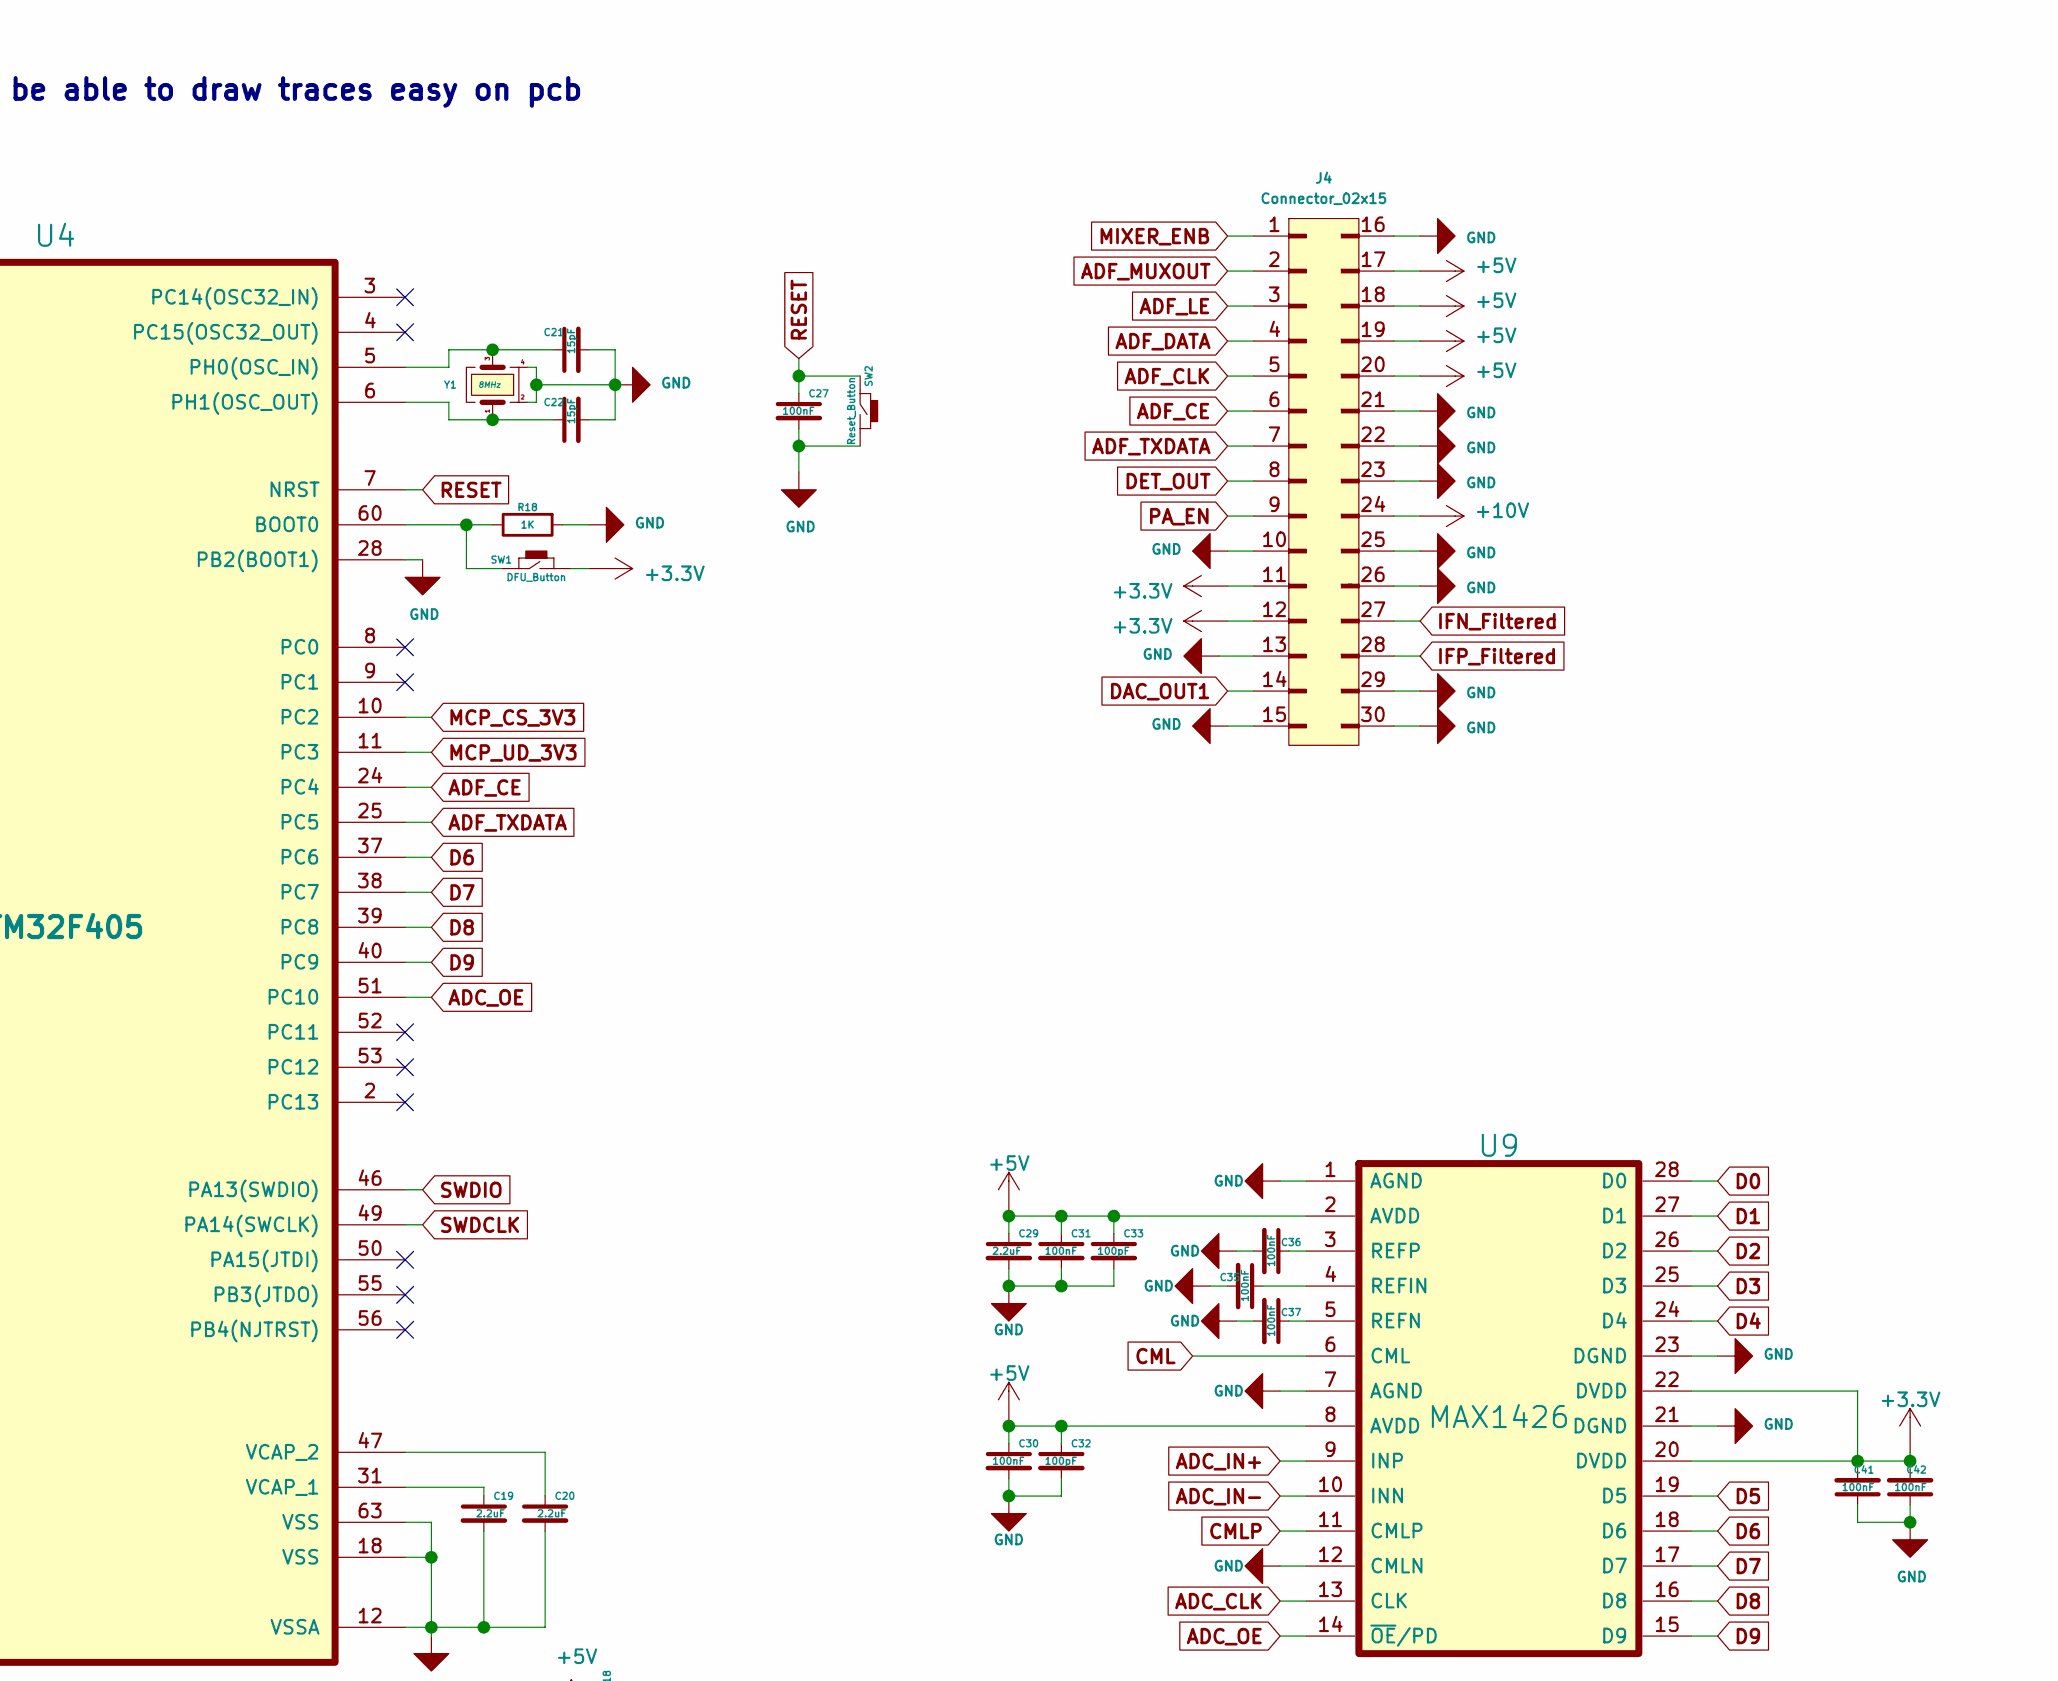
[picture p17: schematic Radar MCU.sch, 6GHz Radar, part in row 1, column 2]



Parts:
C1, C2, C15, C28: 10uF; SMD_0603
C3, C6, C9, C43, C44: 22uF; SMD_0603
C4, C7, C10: 10nF; SMD_0402
C5, C11, C16, C17, C19, C20, C29: 2.2uF; SMD_0402
C12, C13, C14, C18, C23, C24, C26, C27, C30, C31, C34, C35, C36, C37, C41, C42: 100nF; SMD_0402
C21, C22: 15pF; SMD_0402
C25, C38: 33pF; SMD_0402
C32, C33: 100pF; SMD_0402
C39, C40: 1uF; SMD_0402
D1, D2: Diode_Schottky; Diode_SDM2U30CSP_7
D3, D4, D5: Led_Diode; Diode_0603
J1: SWD_DEBUGGER; PinHeader_1x5_P2.54mm
J2: Connector_01x02; PinHeader_1x2_P2.54mm
J3: USB_MicroB; USB_MicroB_TH
J4: Connector_02x15; PinHeader_2x15_DF12B(5.0)-30DP-0.5V(86)
J5: GPIO_EXTRA; PinHeader_1x5_P2.54mm
L1, L2: 4.7uH; SMD_0805
Q1, Q2: BSS138; SOT23_3
R1, R2, R16: 22; SMD_0402
R3: 14.7K; SMD_0402
R4, R23, R27, R31: 4.7K; SMD_0402
R5, R6, R22: 100; SMD_0402
R7, R8, R17, R24, R28, R29: 10K; SMD_0402
R9, R10, R26: 0; SMD_0402
R11, R12, R25: DNP; SMD_0402
R13, R14, R18, R20, R32, R33, R34: 1K; SMD_0402
R15, R19: 2.49K; SMD_0402
R21: 49.9; SMD_0402
R30: 24.4K; SMD_0402
SW1: DFU_Button; Button_B3U_1000P
SW2: Reset_Button; Button_B3U_1000P
U1, U2: AP3211; SOT23_6
U3: LP2985_10; SOT23_5
U4: STM32F405; LQFP64_10x10mm_P0.5mm
U5: IF+; SolderPad_1_1.5mm_SMD_Rectangle
U6: IF-; SolderPad_1_1.5mm_SMD_Rectangle
U7: MCP4022; SOT23_6
U8: LT1817GN; SSOP16_3.9x4.9mm_P0.635mm
U9: MAX1426; SSOP28_5.3x10.2mm_P0.65mm
Y1: 8MHz; Crystal_3.2x2.5mm

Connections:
+3V3: C9.1, C12.1, C13.1, C14.1, C15.1, C16.1, C17.1, C41.2, C42.2, D5.2 (A), J1.1, J4.11, J4.12, L1.2, R3.1, SW1.2, U4.1 (VBAT), U4.13 (VDDA), U4.19 (VDD), U4.32 (VDD), U4.48 (VDD), U4.64 (VDD), U9.20 (DVDD), U9.22 (DVDD); also elsewhere on the board
+5V: C6.1, C18.1, C26.1, C29.1, C30.1, C31.1, C32.1, C33.1, D4.2 (A), J3.1 (VBUS), J4.17, J4.18, J4.19, J4.20, L2.2, R7.1, R8.1, R26.2, R30.1, U7.1 (VDD), U8.4 (V+), U9.2 (AVDD), U9.8 (AVDD); also elsewhere on the board
+10V: C11.1, J4.24, U3.5 (VOUT)
+VBattery: C1.1, C2.1, C3.1, C5.2, C43.1, C44.1, D3.2 (A), J2.2, U1.4 (EN), U1.5 (IN), U2.4 (EN), U2.5 (IN), U3.1 (VIN), U3.3 (EN); also elsewhere on the board
ADC_CLK: R16.2, U4.42 (PA9), U9.13 (CLK)
ADC_IN+: C39.1, U9.9 (INP)
ADC_IN-: C40.1, U9.10 (INN)
ADC_OE: U4.51 (PC10), U9.14 (~OE~/PD)
ADF_CE: J4.6, U4.24 (PC4)
ADF_CLK: J4.5, U4.21 (PA5)
ADF_DATA: J4.4, U4.23 (PA7)
ADF_LE: J4.3, U4.16 (PA2)
ADF_MUXOUT: J4.2, U4.15 (PA1)
ADF_TXDATA: J4.7, U4.25 (PC5)
CML: C34.2, R15.1, U9.6 (CML)
CMLP: R25.1, R26.1, U9.11 (CMLP)
CM_BIAS: C24.2, R17.1, R19.2, R21.1, R23.2, R24.1
D0: U4.29 (PB10), U9.28 (D0)
D1: U4.30 (PB11), U9.27 (D1)
D2: U4.33 (PB12), U9.26 (D2)
D3: U4.34 (PB13), U9.25 (D3)
D4: U4.35 (PB14), U9.24 (D4)
D5: U4.36 (PB15), U9.19 (D5)
D6: U4.37 (PC6), U9.18 (D6)
D7: U4.38 (PC7), U9.17 (D7)
D8: U4.39 (PC8), U9.16 (D8)
D9: U4.40 (PC9), U9.15 (D9)
DAC_OUT1: J4.14, U4.20 (PA4)
DET_OUT: J4.8, U4.26 (PB0)
GND: C1.2, C2.2, C3.2, C5.1, C6.2, C9.2, C10.1, C11.2, C12.2, C13.2, C14.2, C15.2, C16.2, C17.2, C18.2, C19.2, C20.2, C21.2, C22.2, C24.1, C26.2, C27.2, C29.2, C30.2, C31.2, C32.2, C33.2, C34.1, C35.2, C36.2, C37.2, C41.1, C42.1, C43.2, C44.2, D1.2 (A), D2.2 (A), J1.2, J2.1, J3.5 (GND), J4.10, J4.13, J4.15, J4.16, J4.21, J4.22, J4.23, J4.25, J4.26, J4.29, J4.30, Q1.2 (S), Q2.2 (S), R4.2, R18.1, R25.2, R31.2, R32.2, R33.2, R34.2, SW2.2, U1.2 (GND), U2.2 (GND), U3.2 (GND), U4.12 (VSSA), U4.18 (VSS), U4.28 (PB2(BOOT1)), U4.63 (VSS), U7.2 (VSS), U8.13 (V-), U9.1 (AGND), U9.7 (AGND), U9.12 (CMLN), U9.21 (DGND), U9.23 (DGND), Y1.2, Y1.4; also elsewhere on the board
IFN_Filtered: J4.27, R10.1
IFP_Filtered: J4.28, R9.1
MCP_AOUT: R22.1, U7.6 (A)
MCP_CS_3V3: R6.1, U4.10 (PC2)
MCP_UD_3V3: R5.1, U4.11 (PC3)
MCP_WIN: C28.1, U7.5 (W)
MCP_~CS~_5V: Q2.3 (D), R8.2, U7.4 (~CS)
MCP_~UD~_5V: Q1.3 (D), R7.2, U7.3 (U/~D)
MIXER_ENB: J4.1, U4.14 (PA0)
unnamed: C4.1, U1.1 (BS)
unnamed: C4.2, D2.1 (C), L2.1, U1.6 (SW)
unnamed: C7.1, U2.1 (BS)
unnamed: C7.2, D1.1 (C), L1.1, U2.6 (SW)
unnamed: C10.2, U3.4 (BYP)
unnamed: C19.1, U4.31 (VCAP_1)
unnamed: C20.1, U4.47 (VCAP_2)
unnamed: C21.1, U4.5 (PH0(OSC_IN)), Y1.3
unnamed: C22.1, U4.6 (PH1(OSC_OUT)), Y1.1
unnamed: C23.1, R21.2, U8.16
unnamed: C23.2, R19.1, U8.15 (-)
unnamed: C25.1, C28.2, R20.2, U8.1
unnamed: C25.2, R14.2, R20.1, U8.2 (-)
unnamed: C35.1, U9.4 (REFIN)
unnamed: C36.1, U9.3 (REFP)
unnamed: C37.1, U9.5 (REFN)
unnamed: C38.1, C39.2, R27.2, R28.1, U8.7
unnamed: C38.2, R22.2, R27.1, U8.6 (-)
unnamed: C40.2, R29.2, U8.10
unnamed 58: D3.1 (K), R32.1; also elsewhere on the board
unnamed 59: D4.1 (K), R33.1; also elsewhere on the board
unnamed 60: D5.1 (K), R34.1; also elsewhere on the board
unnamed: J3.2 (D-), R1.1
unnamed: J3.3 (D+), R2.1
unnamed: Q1.1 (G), R5.2
unnamed: Q2.1 (G), R6.2
unnamed: R3.2, R4.1, U2.3 (FB)
unnamed: R10.2, R12.1, R14.1
unnamed: R9.2, R11.1, R13.1
unnamed 69: R11.2, U5.1; also elsewhere on the board
unnamed 70: R12.2, U6.1; also elsewhere on the board
unnamed: R13.2, R17.2, U8.3 (+)
unnamed: R15.2, U8.14 (+)
unnamed: R16.1, U4.43 (PA10)
unnamed 74: R18.2, SW1.1, U4.60 (BOOT0); also elsewhere on the board
unnamed: R23.1, U8.12 (+)
unnamed: R24.2, U8.5 (+)
unnamed: R28.2, R29.1, U8.11 (-)
unnamed: R30.2, R31.1, U1.3 (FB)
PA_EN: J4.9, U4.27 (PB1)
PB5: J5.1, U4.57 (PB5)
PB6: J5.2, U4.58 (PB6)
PB7: J5.3, U4.59 (PB7)
PB8: J5.4, U4.61 (PB8)
PB9: J5.5, U4.62 (PB9)
RESET: C27.1, J1.5, SW2.1, U4.7 (NRST); also elsewhere on the board
SWDCLK: J1.3, U4.49 (PA14(SWCLK))
SWDIO: J1.4, U4.46 (PA13(SWDIO))
USB_D+: R2.2, U4.45 (PA12)
USB_D-: R1.2, U4.44 (PA11)

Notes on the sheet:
SPI1_MOSI
SPI1_CLK
ADC12_IN8
For AC Coupled Connect to 5V For DC Coupled Connect to GND
Common Mode Level can accept external voltage when the internal reference is disabled by REFN = AGND
AC Coupling is filtering and removing DC bias level so only AC signal DC Coupling is both DC bias and AC signal is present.
DIFFERENTIAL TO SINGLE CONVERTED OPAMP VOUT = GAIN X (IFP - IFN)
INVERTING AMPLIFIER VOUT = -(4.7K / MCP4022 + 100)
TIM1 CH2
EXTERNAL INTERRUPT FOR RISING EDGE ALSO HAS TIMER FUNCTIONALLITY
16V Max
18V Max 1.5A
SPI1_MISO
TIM1 CH3 EXTI
I placed connections to be able to draw traces easy on pcb
IFP_Filtered PAD
IFN_Filtered PAD



Board: 4 copper layers, 36.9 x 32.9 mm, 104 parts (34 on the bottom side), 89 nets.

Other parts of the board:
3V3, 5V: Led_Diode; Diode_0603
BOOT: DFU_Button; Button_B3U_1000P
C8: 100nF; SMD_0402
IFN_FILTERED: IF-; SolderPad_1_1.5mm_SMD_Rectangle
IFP_FILTERED: IF+; SolderPad_1_1.5mm_SMD_Rectangle
POWER IN: Connector_01x02; PinHeader_1x2_P2.54mm
RESET: Reset_Button; Button_B3U_1000P
VIN: Led_Diode; Diode_0603

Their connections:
+3V3: 3V3.2, BOOT.2; also elsewhere on the board
+5V: 5V.2, C8.1; also elsewhere on the board
+VBattery: POWER IN.2, VIN.2; also elsewhere on the board
GND: C8.2, POWER IN.1, RESET.2; also elsewhere on the board
unnamed 58: VIN.1; also elsewhere on the board
unnamed 59: 5V.1; also elsewhere on the board
unnamed 60: 3V3.1; also elsewhere on the board
unnamed 69: IFP_FILTERED.1; also elsewhere on the board
unnamed 70: IFN_FILTERED.1; also elsewhere on the board
unnamed 74: BOOT.1; also elsewhere on the board
RESET: RESET.1; also elsewhere on the board

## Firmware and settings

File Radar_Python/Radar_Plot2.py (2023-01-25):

# pip3 install pyserial

import serial.tools.list_ports
import numpy as np
import matplotlib.pyplot as mp
import peakutils
import time
from scipy import signal

from PyQt5 import QtWidgets, QtCore
from vispy.scene import SceneCanvas, visuals
from vispy.app import use_app
from vispy import scene

record_file = open("Radar_Records/_rcmp76KHZ_5.5G_400MHZ_1.txt", "r")

data = str(record_file.readline())
RECORD_COUNTER = int(data[0:len(data) - 1])
print("Record Counter: ", str(RECORD_COUNTER))

data = str(record_file.readline())
RECORD_TIME = int(data[0:len(data) - 1])
print("Record Time: ", str(RECORD_TIME), " sec.")

data = str(record_file.readline())
SWEEP_TIME = int(data[0:len(data) - 1]) / 1000000
print("Sweep Time : ", str(SWEEP_TIME), " microsec.")

data = str(record_file.readline())
SWEEP_GAP = int(data[0:len(data) - 1]) / 1000000
print("Sweep Gap : ", str(SWEEP_GAP), " microsec.")

data = str(record_file.readline())
SAMPLING_FREQUENCY = int(data[0:len(data) - 1])
print("Sampling Freqeuncy : ", str(SAMPLING_FREQUENCY), " Hz.")

data = str(record_file.readline())
NUMBER_OF_SAMPLES = int(data[0:len(data) - 1])
print("Samples per sweep : ", str(NUMBER_OF_SAMPLES))

data = str(record_file.readline())
TX_MODE = int(data[0:len(data) - 1])
print("Tx Mode : ", str(TX_MODE))

data = str(record_file.readline())
TX_POWER_DBM = int(data[0:len(data) - 1])
print("Tx Power : ", str(TX_POWER_DBM), " dBm.")

data = str(record_file.readline())
hz_per_m = int(data[0:len(data) - 1])
print("Hz per m : ", str(hz_per_m))

data = str(record_file.readline())
DATA_LOG = int(data[0:len(data) - 1])
print("Data Log : ", str(DATA_LOG))

data = str(record_file.readline())
ADC_SELECT = int(data[0:len(data) - 1])
print("ADC Select : ", str(ADC_SELECT))

line_number_textFile = 0

is_restart_clicked = False

CANVAS_SIZE = (1200, 700)  # (width, height)

# freq plot variables
MAX_FREQ_RANGE = SAMPLING_FREQUENCY / 2 # for 933KHz sampling 933K / 2 is max range
FREQ_RANGE = MAX_FREQ_RANGE / 2
AVERAGING_NUM = 100
MAX_DISTANCE = FREQ_RANGE / hz_per_m

FREQ_NUM_LINE_POINTS = int((FREQ_RANGE / 2)) + 2 - AVERAGING_NUM # this is the array size according to averaging.

FREQ_X_LIMIT_MIN = 0.0
FREQ_X_LIMIT_MAX = float(FREQ_RANGE)

FREQ_Y_LIMIT_MIN = 0
FREQ_Y_LIMIT_MAX = 100

# time plot variables
TIME_MS = 100
TIME_NUM_LINE_POINTS = NUMBER_OF_SAMPLES * TIME_MS # TIME_MS millisecond range plot

TIME_X_LIMIT_MIN = 0.0
TIME_X_LIMIT_MAX = float(TIME_MS / 1000)

TIME_Y_LIMIT_MIN = 1.0
TIME_Y_LIMIT_MAX = 2.5

# calculate this so that if record is 10 sec plot should take 10 seconds.
#FREQ_TIME_BETWEEN_PLOT = (FREQ_RANGE / SAMPLING_FREQUENCY) * 2 # Full freq range takes 1 second, half range 0.5 sec
#FREQ_TIME_BETWEEN_PLOT = TIME_BETWEEN_PLOT * 1  # i add this line to change plot speed. multp for slower div for faster

TIME_COLOR_CHOICES = ["black", "red", "blue"]
TIME_SCALE_CHOICES = ["scale/1","scale/2", "scale/4", "scale/8", "scale/16", "scale/32"]

FREQ_COLOR_CHOICES = ["black", "red", "blue"]
FREQ_SCALE_CHOICES = ["scale/1","scale/2", "scale/4", "scale/8", "scale/16", "scale/32"]

# Decode data_record
freq_sample_array = []
time_sample_array = []

USB_PLOT = 1
MICROCARD_PLOT = 0
REMOVE_CLUTTER = 1
clutter_counter = 0
fft_prev_array = np.zeros(FREQ_NUM_LINE_POINTS)
fft_current_array = np.zeros(FREQ_NUM_LINE_POINTS)

def Moving_Average_Filter(a, n = 1):

    ret = np.cumsum(a, dtype=float)
    ret[n:] = ret[n:] - ret[:-n]
    return ret[n - 1:] / n


def FFT_Calculate(sample_data, sample_period, window = None, average = 1):

    if window:
        w = window(len(sample_data))
        sample_data = [sample_data[i] * w[i] for i in range(len(w))]

    fs = 0.5/float(sample_period)
    fft_ = np.fft.rfft(sample_data)

    #fft2_ = pyfftw.FFTW(sample_data);

    averages = average
    fft_ = Moving_Average_Filter(np.abs(fft_), averages)
    bins = len(fft_)
    f_step = fs/bins
    fx = [f_step*i for i in range(0, bins)]

    #peakIndexes = peakutils.indexes(finalFFT, 0.025, min_dist=50, thres_abs=True)

    return fx, fft_

class Controls(QtWidgets.QWidget):
    def __init__(self, parent=None):
        super().__init__(parent)
        layout = QtWidgets.QVBoxLayout()

        self.time_color_label = QtWidgets.QLabel("Time Color:")
        layout.addWidget(self.time_color_label)
        self.time_color_chooser = QtWidgets.QComboBox()
        self.time_color_chooser.addItems(TIME_COLOR_CHOICES)
        layout.addWidget(self.time_color_chooser)

        self.freq_color_label = QtWidgets.QLabel("Freq Color:")
        layout.addWidget(self.freq_color_label)
        self.freq_color_chooser = QtWidgets.QComboBox()
        self.freq_color_chooser.addItems(FREQ_COLOR_CHOICES)
        layout.addWidget(self.freq_color_chooser)

        self.time_scale_label = QtWidgets.QLabel("Time Scale:")
        layout.addWidget(self.time_scale_label)
        self.time_scale_chooser = QtWidgets.QComboBox()
        self.time_scale_chooser.addItems(TIME_SCALE_CHOICES)
        layout.addWidget(self.time_scale_chooser)

        self.freq_scale_label = QtWidgets.QLabel("Freq Scale:")
        layout.addWidget(self.freq_scale_label)
        self.freq_scale_chooser = QtWidgets.QComboBox()
        self.freq_scale_chooser.addItems(FREQ_SCALE_CHOICES)
        layout.addWidget(self.freq_scale_chooser)

        self.restart_label = QtWidgets.QLabel("Restart Plot")
        layout.addWidget(self.restart_label)
        self.restart_button = QtWidgets.QPushButton()
        self.restart_button.setText("Restart")
        layout.addWidget(self.restart_button)


        layout.addStretch(1)
        self.setLayout(layout)


class CanvasWrapper:
    def __init__(self):
        self.canvas = SceneCanvas(size=CANVAS_SIZE)
        self.grid = self.canvas.central_widget.add_grid()

        global line_number_textFile

        number_of_plot_row = 3

        canvas_offset_per_row = CANVAS_SIZE[1] / number_of_plot_row

        # Time Plot
        # color array
        print("TIME_NUM_LINE_POINTS",TIME_NUM_LINE_POINTS)
        color = np.ones((TIME_NUM_LINE_POINTS, 4), dtype=np.float32)
        color[:, 0] = np.linspace(0, 1, TIME_NUM_LINE_POINTS)
        color[:, 1] = color[::-1, 0]

        time_plot_data = np.zeros((TIME_NUM_LINE_POINTS, 2), dtype=np.float32) # 2x6000 array

        # background color
        self.view_time_plot = self.grid.add_view(0, 0, bgcolor='#063970')
        self.time_line = visuals.Line(time_plot_data, parent=self.view_time_plot.scene, color=color)
        self.view_time_plot.camera = "panzoom"

        print("TIME_X_LIMIT_MIN", TIME_X_LIMIT_MIN)
        print("TIME_X_LIMIT_MAX", TIME_X_LIMIT_MAX)
        print("TIME_Y_LIMIT_MIN", TIME_Y_LIMIT_MIN)
        print("TIME_Y_LIMIT_MAX", TIME_Y_LIMIT_MAX)
        self.view_time_plot.camera.set_range(x=(TIME_X_LIMIT_MIN, TIME_X_LIMIT_MAX),
                                             y=(TIME_Y_LIMIT_MIN, TIME_Y_LIMIT_MAX))

        # add x axis
        xaxis1 = scene.AxisWidget(orientation='top', axis_label='X Axis', axis_font_size=10, axis_label_margin=6, tick_label_margin=3)
        xaxis1.height_max = CANVAS_SIZE[1]

        self.grid.add_widget(xaxis1, row=0, col=0)
        xaxis1.link_view(self.view_time_plot)

        # add y axis
        yaxis1 = scene.AxisWidget(orientation='left', axis_label='Y Axis', axis_font_size=10, axis_label_margin=6, tick_label_margin=3)
        yaxis1.width_max = 0 # distance from right side of the window

        self.grid.add_widget(yaxis1, row=0, col=1)
        yaxis1.link_view(self.view_time_plot)




        # Freq Plot ***************************
        # color array
        print("FREQ_NUM_LINE_POINTS", FREQ_NUM_LINE_POINTS)
        color = np.ones((FREQ_NUM_LINE_POINTS, 4), dtype=np.float32)
        color[:, 0] = np.linspace(0, 1, FREQ_NUM_LINE_POINTS)
        color[:, 1] = color[::-1, 0]

        freq_plot_data = np.zeros((FREQ_NUM_LINE_POINTS, 2), dtype=np.float32)  # 2x6000 array

        # background color
        self.view_freq_plot = self.grid.add_view(1, 0, bgcolor='#063970')
        self.freq_line = visuals.Line(freq_plot_data, parent=self.view_freq_plot.scene, color=color)
        self.view_freq_plot.camera = "panzoom"

        print("FREQ_X_LIMIT_MIN", FREQ_X_LIMIT_MIN)
        print("FREQ_X_LIMIT_MAX", FREQ_X_LIMIT_MAX)
        print("FREQ_Y_LIMIT_MIN", FREQ_Y_LIMIT_MIN)
        print("FREQ_Y_LIMIT_MAX", FREQ_Y_LIMIT_MAX)
        self.view_freq_plot.camera.set_range(x=(FREQ_X_LIMIT_MIN, FREQ_X_LIMIT_MAX),
                                             y=(FREQ_Y_LIMIT_MIN, FREQ_Y_LIMIT_MAX))

        # add x axis
        xaxis2 = scene.AxisWidget(orientation='top', axis_label='X Axis', axis_font_size=10, axis_label_margin=6,
                                 tick_label_margin=3)
        xaxis2.height_max = CANVAS_SIZE[1] - canvas_offset_per_row

        self.grid.add_widget(xaxis2, row=1, col=0)
        xaxis2.link_view(self.view_freq_plot)

        # add y axis
        yaxis2 = scene.AxisWidget(orientation='left', axis_label='Y Axis', axis_font_size=10, axis_label_margin=6,
                                 tick_label_margin=3)
        yaxis2.width_max = 0  # distance from right side of the window

        self.grid.add_widget(yaxis2, row=1, col=1)
        yaxis2.link_view(self.view_freq_plot)

        '''
        global waterfall_time_array
        # Waterfall plot
        img_data1, img_data2 = np.meshgrid(waterfall_time_array, freq_plot_data[1])
        img_data = (img_data2 * np.exp(1j * img_data1)).astype(np.complex64)

        #img_data = waterfall_data()

        # View it with "complex_mode=imaginary"
        self.view_waterfall_plot = self.grid.add_view(2, 0, bgcolor='#063970')
        self.waterfall_img = scene.visuals.ComplexImage(img_data, parent=self.view_waterfall_plot.scene, complex_mode="phase")
        self.view_waterfall_plot.camera = scene.PanZoomCamera(aspect=1)
        self.view_waterfall_plot.camera.set_range()
        #self.view_waterfall_plot.camera.set_range(x=(FREQ_X_LIMIT_MIN, FREQ_X_LIMIT_MAX),y=(FREQ_Y_LIMIT_MIN, FREQ_Y_LIMIT_MAX))
        self.view_waterfall_plot.camera.zoom(1)
        
        '''

    def set_time_color(self, color):
        print(f"Changing line color to {color}")
        self.time_line.set_data(color=color)

    def set_freq_color(self, color):
        print(f"Changing line color to {color}")
        self.freq_line.set_data(color=color)

    def set_time_scale(self, scale):
        if scale == "scale/1":
            self.view_time_plot.camera.set_range(x=(TIME_X_LIMIT_MIN / 1, TIME_X_LIMIT_MAX / 1),
                                           y=(TIME_Y_LIMIT_MIN, TIME_Y_LIMIT_MAX))
        if scale == "scale/2":
            self.view_time_plot.camera.set_range(x=(TIME_X_LIMIT_MIN / 2, TIME_X_LIMIT_MAX / 2),
                                           y=(TIME_Y_LIMIT_MIN, TIME_Y_LIMIT_MAX))
        elif scale == "scale/4":
            self.view_time_plot.camera.set_range(x=(TIME_X_LIMIT_MIN / 4, TIME_X_LIMIT_MAX / 4),
                                           y=(TIME_Y_LIMIT_MIN, TIME_Y_LIMIT_MAX))
        elif scale == "scale/8":
            self.view_time_plot.camera.set_range(x=(TIME_X_LIMIT_MIN / 8, TIME_X_LIMIT_MAX / 8),
                                           y=(TIME_Y_LIMIT_MIN, TIME_Y_LIMIT_MAX))
        elif scale == "scale/16":
            self.view_time_plot.camera.set_range(x=(TIME_X_LIMIT_MIN / 16, TIME_X_LIMIT_MAX / 16),
                                           y=(TIME_Y_LIMIT_MIN, TIME_Y_LIMIT_MAX))
        elif scale == "scale/32":
            self.view_time_plot.camera.set_range(x=(TIME_X_LIMIT_MIN / 32 , TIME_X_LIMIT_MAX / 32),
                                           y=(TIME_Y_LIMIT_MIN, TIME_Y_LIMIT_MAX))


    def set_freq_scale(self, scale):
        if scale == "scale/1":
            self.view_freq_plot.camera.set_range(x=(FREQ_X_LIMIT_MIN / 1, FREQ_X_LIMIT_MAX / 1),
                                           y=(FREQ_Y_LIMIT_MIN, FREQ_Y_LIMIT_MAX))
        if scale == "scale/2":
            self.view_freq_plot.camera.set_range(x=(FREQ_X_LIMIT_MIN / 2, FREQ_X_LIMIT_MAX / 2),
                                           y=(FREQ_Y_LIMIT_MIN, FREQ_Y_LIMIT_MAX))
        elif scale == "scale/4":
            self.view_freq_plot.camera.set_range(x=(FREQ_X_LIMIT_MIN / 4, FREQ_X_LIMIT_MAX / 4),
                                           y=(FREQ_Y_LIMIT_MIN, FREQ_Y_LIMIT_MAX))
        elif scale == "scale/8":
            self.view_freq_plot.camera.set_range(x=(FREQ_X_LIMIT_MIN / 8, FREQ_X_LIMIT_MAX / 8),
                                           y=(FREQ_Y_LIMIT_MIN, FREQ_Y_LIMIT_MAX))
        elif scale == "scale/16":
            self.view_freq_plot.camera.set_range(x=(FREQ_X_LIMIT_MIN / 16, FREQ_X_LIMIT_MAX / 16),
                                           y=(FREQ_Y_LIMIT_MIN, FREQ_Y_LIMIT_MAX))
        elif scale == "scale/32":
            self.view_freq_plot.camera.set_range(x=(FREQ_X_LIMIT_MIN / 32, FREQ_X_LIMIT_MAX / 32),
                                           y=(FREQ_Y_LIMIT_MIN, FREQ_Y_LIMIT_MAX))

    def restart_plot(self):
        print("Restart is clicked")
        global is_restart_clicked
        is_restart_clicked = True

    def update_data(self, new_data_dict):
        #print("Updating data...")
        self.time_line.set_data(new_data_dict["time"])
        self.freq_line.set_data(new_data_dict["freq"])
        #self.waterfall_img.set_data(new_data_dict["watefall"])


def waterfall_data(size=512, phase_range=(-np.pi, np.pi), mag_range=(0, 10)):
    """Returns a complex array where X ramps phase and Y ramps magnitude."""
    p0, p1 = phase_range
    phase_ramp = np.linspace(p0, p1 - 1 / size, size)

    m0, m1 = mag_range
    mag_ramp = np.linspace(m1, m0 + 1 / size, size)

    phase_ramp, mag_ramp = np.meshgrid(phase_ramp, mag_ramp)

    return (mag_ramp * np.exp(1j * phase_ramp)).astype(np.complex64)

class MyMainWindow(QtWidgets.QMainWindow):
    closing = QtCore.pyqtSignal()

    def __init__(self, canvas_wrapper: CanvasWrapper, *args, **kwargs):
        super().__init__(*args, **kwargs)

        self.setFixedWidth(CANVAS_SIZE[0])
        self.setFixedHeight(CANVAS_SIZE[1])

        self.setWindowTitle("FMCW Radar by Cenk Keskin")

        central_widget = QtWidgets.QWidget()
        main_layout = QtWidgets.QHBoxLayout()

        self._controls = Controls()
        main_layout.addWidget(self._controls)
        self._canvas_wrapper = canvas_wrapper
        main_layout.addWidget(self._canvas_wrapper.canvas.native)

        central_widget.setLayout(main_layout)
        self.setCentralWidget(central_widget)

        self._connect_controls()

    def _connect_controls(self):
        self._controls.time_color_chooser.currentTextChanged.connect(self._canvas_wrapper.set_time_color)
        self._controls.freq_color_chooser.currentTextChanged.connect(self._canvas_wrapper.set_freq_color)
        self._controls.time_scale_chooser.currentTextChanged.connect(self._canvas_wrapper.set_time_scale)
        self._controls.freq_scale_chooser.currentTextChanged.connect(self._canvas_wrapper.set_freq_scale)
        self._controls.restart_button.clicked.connect(self._canvas_wrapper.restart_plot)

    def closeEvent(self, event):
        print("Closing main window!")
        self.closing.emit()
        return super().closeEvent(event)


class DataSource(QtCore.QObject):

    new_data = QtCore.pyqtSignal(dict)
    finished = QtCore.pyqtSignal()

    def __init__(self, parent=None):
        super().__init__(parent)
        self._should_end = False

        # create arrays
        self._time_domain_data = np.zeros((TIME_NUM_LINE_POINTS, 2), dtype = np.float32) # 2 x NUM_LINE_POINTS array
        self._freq_domain_data = np.zeros((FREQ_NUM_LINE_POINTS, 2), dtype = np.float32) # 2 x NUM_LINE_POINTS array

        '''
        global waterfall_time_array
        # Waterfall plot
        img_data1, img_data2 = np.meshgrid(waterfall_time_array, self._freq_domain_data[1])
        self._waterfall_data = (img_data2 * np.exp(1j * img_data1)).astype(np.complex64)

        self.waterfall_counter = 0
        '''

    def run_data_creation(self):

        print("Run data creation is starting")
        global line_number_textFile
        global record_file
        global is_restart_clicked
        global clutter_counter
        global fft_prev_array
        global fft_current_array

        while line_number_textFile < RECORD_COUNTER:

            if is_restart_clicked == True:

                print("Reset variables")

                is_restart_clicked = False
                print("is_restart_clicked: ", is_restart_clicked)

                record_file.seek(0)  # move file cursor to line 12, first 11 lines are radar info data

                line_number_textFile = 0
                print("line_number_textFile: ",line_number_textFile)

                # Read info lines
                for i in range(0, 11):
                    _line = record_file.readline()
                    print(_line)

                clutter_counter = 0

            if self._should_end:
                print("Data source is told to stop")
                break

            # set this time according to the update rate
            #print("TIME_BETWEEN_PLOT",TIME_BETWEEN_PLOT)
            #time.sleep(TIME_BETWEEN_PLOT/1000)
            time.sleep(0.00001)

            sample_line = record_file.readline()
            samples_hex = bytes.fromhex(sample_line)  # get hex data from string
            length_line = len(samples_hex)

            index = 0

            # If there is data available
            if length_line > 0:

                while index < length_line:

                    if ADC_SELECT == 1:
                        # For faster operation i transfer 4 bit and 6 bit of the samples in 2 bytes
                        current_sample_16bit = ((samples_hex[index] & 0xF) << 6) | (samples_hex[index + 1] & 0x3F)

                        current_sample_float = (current_sample_16bit / 2 ** 10) * 5.0

                        #current_sample_float -= 2.25 # bias voltage

                    else:
                        current_sample_16bit = ((samples_hex[index] & 0xFF) << 8) | (samples_hex[index + 1] & 0xFF)

                        current_sample_float = (current_sample_16bit / 2 ** 12) * 3.3

                        #current_sample_float -= 2.5 # bias voltage

                    index += 2
                    freq_sample_array.append(current_sample_float)
                    time_sample_array.append(current_sample_float)

            # Add another plot and try plotting with pointwise update from left to right

            # Plot Freq Line
            if len(freq_sample_array) == FREQ_RANGE:

                fx, fy = FFT_Calculate(freq_sample_array, 1 / SAMPLING_FREQUENCY, np.hamming, AVERAGING_NUM)

                if REMOVE_CLUTTER:

                    if clutter_counter == 0:
                        fft_prev_array = fy
                        clutter_counter = clutter_counter + 1
                    else:
                        fft_current_array = fy - fft_prev_array

                        # subtraction makes negative amplitude so i make them zero
                        fft_current_array = np.where(fft_current_array < 0, 0, fft_current_array)

                        fft_prev_array = fy

                        clutter_counter = clutter_counter + 1

                    if clutter_counter > 0:

                        # magnitude adjustement on fft data
                        #for i in range(0, 200000):
                            #if i < 100000:
                             #   fft_current_array[i] = fft_current_array[i] / 1
                            #if i >= 100000 and i < 200000:
                                #fft_current_array[i] = 1 * fft_current_array[i]

                        self._freq_domain_data[:, 0] = fx # freq values from 0 to 1/2 samplig freq
                        self._freq_domain_data[:, 1] = fft_current_array  # amplitude values of each freq

                else:
                    self._freq_domain_data[:, 0] = fx  # freq values from 0 to 1/2 samplig freq
                    self._freq_domain_data[:, 1] = fy # amplitude values of each freq

                freq_sample_array.clear()

            # Plot Time Line
            if len(time_sample_array) == TIME_NUM_LINE_POINTS:
                time_step = np.linspace(0.0, float(TIME_MS / 1000), len(time_sample_array))
                self._time_domain_data[:, 0] = time_step
                self._time_domain_data[:, 1] = time_sample_array

                time_sample_array.clear()

            line_number_textFile += 1

            data_dict = {
                "time": self._time_domain_data,
                "freq": self._freq_domain_data,
                #"watefall": self._waterfall_data
            }

            self.new_data.emit(data_dict)
            #print("Data creation")

            if line_number_textFile == RECORD_COUNTER:
                line_number_textFile = 0

                freq_sample_array.clear()
                time_sample_array.clear()

        print("Data source finishing")
        self.finished.emit()

    def stop_data(self):
        print("Data source is quitting...")
        self._should_end = True

def butter_highpass(cutoff, fs, order=5):
    nyq = 0.5 * fs
    normal_cutoff = cutoff / nyq
    b, a = signal.butter(order, normal_cutoff, btype='high', analog=False)
    return b, a

def butter_highpass_filter(data, cutoff, fs, order=5):
    b, a = butter_highpass(cutoff, fs, order=order)
    y = signal.filtfilt(b, a, data)
    return y
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

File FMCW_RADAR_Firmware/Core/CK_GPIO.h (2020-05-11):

#ifndef CK_GPIO_H_
#define CK_GPIO_H_

#include "stm32f4xx.h"

typedef enum
{
  CK_GPIO_INPUT                 = 0u,
  CK_GPIO_OUTPUT                = 1u,
  CK_GPIO_AF               	    = 2u,
  CK_GPIO_ANALOG                = 3u

}CK_GPIOx_Mode;

typedef enum
{
  CK_GPIO_PUSHPULL              = 0u,
  CK_GPIO_OPENDRAIN             = 1u

}CK_GPIOx_Type;

typedef enum
{
  CK_GPIO_LOW              		= 0u,
  CK_GPIO_MEDIUM              	= 1u,
  CK_GPIO_HIGH					= 2u,
  CK_GPIO_VERYHIGH              = 3u

}CK_GPIOx_Speed;

typedef enum
{
	CK_GPIO_NOPUPD              = 0u,
	CK_GPIO_PULLUP              = 1u,
	CK_GPIO_PULLDOWN            = 2u

}CK_GPIOx_PUPD;


typedef enum
{
	CK_GPIO_AF0               = 0u,
	CK_GPIO_AF1               = 1u,
	CK_GPIO_AF2               = 2u,
	CK_GPIO_AF3               = 3u,
	CK_GPIO_AF4               = 4u,
	CK_GPIO_AF5               = 5u,
	CK_GPIO_AF6               = 6u,
	CK_GPIO_AF7               = 7u,
	CK_GPIO_AF8               = 8u,
	CK_GPIO_AF9               = 9u,
	CK_GPIO_AF10              = 0xAu,
	CK_GPIO_AF11              = 0xBu,
	CK_GPIO_AF12              = 0xCu,
	CK_GPIO_AF13              = 0xDu,
	CK_GPIO_AF14              = 0xEu,
	CK_GPIO_AF15              = 0xFu,
	CK_GPIO_NOAF              = 0x10u

}CK_GPIOx_AFx;

void CK_GPIO_Init(GPIO_TypeDef* GPIOx, uint16_t GPIOx_Pin, CK_GPIOx_Mode GPIOx_Mode, CK_GPIOx_AFx GPIOx_AF,
				  CK_GPIOx_Type GPIOx_Type, CK_GPIOx_Speed GPIOx_Speed, CK_GPIOx_PUPD GPIOx_PUPD);

void CK_GPIO_ClockEnable(GPIO_TypeDef* GPIOx);

void CK_GPIO_SetPin(GPIO_TypeDef* GPIOx,uint16_t GPIOx_Pin);

void CK_GPIO_ClearPin(GPIO_TypeDef* GPIOx,uint16_t GPIOx_Pin);

uint8_t CK_GPIO_ReadPin(GPIO_TypeDef* GPIOx ,uint16_t GPIOx_Pin);

#endif /* CK_GPIO_H_ */

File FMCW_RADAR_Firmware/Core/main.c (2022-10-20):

#include "stm32f4xx_hal.h"

#include "USBD_CDC/CK_USBD_INTERFACE.h"
#include "CK_TIME_HAL.h"
#include "CK_SYSTEM.h"
#include "CK_GPIO.h"

#include "CK_TQP5523.h"
#include "CK_MCP4022.h"

#include "CK_MAX1426.h"
#include "CK_ADC_DMA.h"

#include "CK_DAC.h"
#include "CK_ADF4158.h"

#include "CK_CONFIGURATION.h"
#include "CK_MICROCARD.h"

/*
 * I will use a sawtooth ramp with 1ms period and 200MHz bandwith
 * 5.8-6.0 GHz range is 5v to 8.3v -> 1.67 to 2.77
 * so DAC range is from 2072 to 3438.
 * Approximately 1 microsecond timer update is necessary.
 *
 * Hardware parameters are configured by python script at the beginning of radar measurement.
 *
 * Radar range:
 * Distance 		= (c * Ts * Fif) / (2 * B)
 * Apprx. 500meters	= (3*10^8 * 1*10^-3 * 500*10^3) / (2 * 200 * 10^6)
 *
 */

#define MIXER_EN_GPIO			GPIOA
#define MIXER_EN_PIN			0

#define SYNC_SIGNAL_GPIO		GPIOB
#define SYNC_SIGNAL_PIN			9

#define FPGA_MODE				0

uint32_t RECORD_TIME_COUNTER 	= 10000; 	// default
uint8_t	 TX_MODE	 			= 0;		// 0 for continuous tx, 1 for on off with tx
uint8_t	 DATA_LOG				= 0;		// 0 for USB Transfer, 1 for Microcard Log
uint8_t	 ADC_SELECT				= 0;		// 0 for ADC DMA, 1 for External ADC MAX1426
uint8_t  PLL_SELECT				= 1;		// 0 for DAC, 1 for PLL

uint32_t record_counter = 0;

int isRestarted = 0;


typedef enum{

	IDLE,
	START_SAMPLING,
	CHECK_SAMPLING,
	TRANSFER_SAMPLES,
	FINISH_SAMPLING

}SAMPLING_STATES_E;

SAMPLING_STATES_E sampling_state = IDLE;

int main(void){

	CK_SYSTEM_SetSystemClock(SYSTEM_CLK_168MHz);

	HAL_Init();

	CK_GPIO_ClockEnable(GPIOA);
	CK_GPIO_ClockEnable(GPIOB);
	CK_GPIO_ClockEnable(GPIOC);
	CK_GPIO_ClockEnable(GPIOD);

	/*
	 * PA0 -> MIXER_EN, Enables or disables bias circuit and the internal detector.
	 * 		  See datasheet pg28 bias circuit. Use pull high
	 */
	CK_GPIO_Init(MIXER_EN_GPIO, MIXER_EN_PIN, CK_GPIO_OUTPUT, CK_GPIO_NOAF, CK_GPIO_PUSHPULL, CK_GPIO_VERYHIGH, CK_GPIO_NOPUPD);
	CK_GPIO_SetPin(MIXER_EN_GPIO, MIXER_EN_PIN);

	/*
	 * Sync pulse is used to check if sampling and usb transfer is occurring before
	 * muxout so ramp timings. Use scope to check state machine.
	 */
	CK_GPIO_Init(SYNC_SIGNAL_GPIO, SYNC_SIGNAL_PIN, CK_GPIO_OUTPUT, CK_GPIO_NOAF, CK_GPIO_PUSHPULL, CK_GPIO_VERYHIGH, CK_GPIO_NOPUPD);
	CK_GPIO_ClearPin(SYNC_SIGNAL_GPIO, SYNC_SIGNAL_PIN);

	CK_USBD_Init();

	// adc uses it pin
	//MCP4022_Init();

	CK_TQP5523_Init(); // Start before configuration

	CK_CONFIGURATION_InitHardware(1); // 1 receive python, 2 default values for debugging, 3 for fpga

	RECORD_TIME_COUNTER 	= CK_CONFIGURATION_GetRecordTimeCounter();

	TX_MODE 				= CK_CONFIGURATION_GetTXMode();

	DATA_LOG				= CK_CONFIGURATION_GetDataLog();

	ADC_SELECT  			= CK_CONFIGURATION_GetAdcSelect();

	PLL_SELECT				= CK_CONFIGURATION_GetPLLSelect();

	uint8_t gain_value 		= CK_CONFIGURATION_GetGainValue();


	if(DATA_LOG == 1){
		CK_MICROCARD_Init(SPI_DMA_INTERRUPT_MULTIBLOCK);
	}

	//MCP4022_SetValue(gain_value);

	if(PLL_SELECT == 1){
		CK_ADF4158_Init(SAWTOOTH_WAVEFORM);
	}
	else{
		CK_DAC_Init(SAWTOOTH_WAVEFORM_DAC);
	}

	if(ADC_SELECT == 1){
		CK_MAX1426_Init();
	}
	else{
		CK_ADC_DMA_Init();
	}

	while(1){

		#if FPGA_MODE

			static int is_system_started = 0;

			if(!is_system_started){

				CK_TQP5523_Enable();

				uint8_t record_time = CK_CONFIGURATION_GetRecordTime();

				for(int i = 0; i < record_time * 1000; i++){

					CK_TIME_DelayMicroSec(1000);

				}

				CK_TQP5523_Disable();

				is_system_started = 1;

			}


		#else

			switch(sampling_state){

			case IDLE:

				if(TX_MODE == 0){
					CK_TQP5523_Enable();
				}

				sampling_state = START_SAMPLING;

				break;

			case START_SAMPLING:

				if(CK_ADF4158_RampCompleted() == 0 && CK_ADF4158_RampStarted() == 1){

					if(TX_MODE == 1){
						CK_TQP5523_Enable();
					}

					if(ADC_SELECT == 1){

						CK_MAX1426_Reset_Counter();
						CK_MAX1426_ResetRecordDone();
						CK_MAX1426_ADC_OutputEnable();
						CK_MAX1426_PWM_Start();

					}
					else{

						// Start sampling
						CK_ADC_DMA_Start();

					}

					sampling_state = CHECK_SAMPLING;

					// Use these pulse to check sync with muxout.
					CK_GPIO_ClearPin(SYNC_SIGNAL_GPIO, SYNC_SIGNAL_PIN);

				}

				break;

			case CHECK_SAMPLING:

				if(ADC_SELECT == 1){

					// Check is buffer full
					if(CK_MAX1426_IsRecordDone() == 1){

						if(TX_MODE == 1){
							CK_TQP5523_Disable();
						}

						CK_MAX1426_ADC_OutputDisable();
						CK_MAX1426_PWM_Stop();

						sampling_state = TRANSFER_SAMPLES;

					}

				}
				else{

					// Check full dma transfer is completed
					if(CK_ADC_DMA_IsTxComplete() == 1){

						if(TX_MODE == 1){
							CK_TQP5523_Disable();
						}

						// DMA is not in circular mode so it stops automatically after NDTR transfers

						// Use these pulse to check sync with muxout.
						CK_GPIO_SetPin(SYNC_SIGNAL_GPIO, SYNC_SIGNAL_PIN);

						sampling_state = TRANSFER_SAMPLES;
					}
				}

				break;

			case TRANSFER_SAMPLES:

				if(CK_ADF4158_RampCompleted() == 1 && CK_ADF4158_RampStarted() == 0){

					if(DATA_LOG == 0){

						if(record_counter < RECORD_TIME_COUNTER){

							record_counter++;

							CK_GPIO_ClearPin(SYNC_SIGNAL_GPIO, SYNC_SIGNAL_PIN);

							if(ADC_SELECT == 1){
								CK_MAX1426_TransferSamplesUSB();
							}
							else{
								CK_ADC_DMA_TransferSamplesUSB();
							}


							CK_GPIO_SetPin(SYNC_SIGNAL_GPIO, SYNC_SIGNAL_PIN);

							sampling_state = START_SAMPLING;

						}
						else{

							if(TX_MODE == 0){
								CK_TQP5523_Disable();
							}

							sampling_state = FINISH_SAMPLING;
						}

					}
					else{

						if(!CK_MICROCARD_IsCompleted()){

							CK_GPIO_ClearPin(SYNC_SIGNAL_GPIO, SYNC_SIGNAL_PIN);

							if(ADC_SELECT == 1){
								CK_MAX1426_TransferSamplesMicroCard();
							}
							else{
								// Implement microcard log for adc dma
							}

							CK_GPIO_SetPin(SYNC_SIGNAL_GPIO, SYNC_SIGNAL_PIN);

							sampling_state = START_SAMPLING;

						}

						else{

							if(TX_MODE == 0){
								CK_TQP5523_Disable();
							}

							sampling_state = FINISH_SAMPLING;
						}

					}

				}

				break;

			case FINISH_SAMPLING:

				NVIC_SystemReset();

				break;

			}


		#endif


	}

}
